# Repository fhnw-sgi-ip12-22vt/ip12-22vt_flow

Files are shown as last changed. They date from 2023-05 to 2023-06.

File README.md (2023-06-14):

# Project FLOW

## Beschreibung

Die Primeo Energie AG ist ein Energieversorgungsunternehmen in Münchenstein und versorgt Teile von Basel-Landschaft, Solothurn und Saint-Louis (F) mit Strom. Primeo legt einen grossen Wert auf erneuerbare Energien.

Primeo hat bereits eine Lernwelt in Münchenstein und in Olten aufgebaut. In dieser Lernwelt werden Workshops angeboten, Experimente können durchgeführt werden und Führungen werden angeboten. Link: [primeo-energie.ch](https://www.primeo-energie.ch/ueber-uns/lernwelt-energie.html)

Mit dem Projekt Primeo Energie Kosmos wird ein neues Science- und Erlebniscenter in Münchenstein gebaut. Es soll eine Verbindung zwischen Klima und Energie geschaffen werden und erneuerbare Energien attraktiver gemacht werden.

### Grundidee
Grundidee unseres Produktes ist, Kindern und Jugendlichen nachhaltige Energieproduktionen und das Max Flow Problem spielerisch näher zu bringen. Die physischen Komponenten sollen bei den Personen ein Interesse wecken, damit sie von alleine auf das Produkt zugehen. Mithilfe von haptischen Elementen soll die Spielperson aktiver am Spiel teilnehmen können.  Eine kurze Spieldauer von 2-3min verhindert Langeweile und Frustration bei der spielenden Person. Um die Verweilzeit am Spiel zu verlängern und die Herausforderung für geschickte Spielpersonen zu erhöhen, können schwierigere Levels ausgewählt werden.

Ziel des Spiels ist es, von der Source (in Abb.1 die Windkraftanlage und der Staudamm) möglichst viel Strom in die Senke (die Fabrik) zu leiten. Dafür wählt die Spielperson die Verbindungslinie zwischen den Häusern mit einem Knopfdruck an und wählt auf dem Display die Menge an Stromeinheiten (0,1,2 oder 3), welche durch diese ausgewählte Kante fliessen soll, aus. Die rote Zahl ist die Maximalkapazität dieser Kante, das heisst die Spielperson kann nicht mehr Einheiten Strom legen, als die Maximalkapazität der Kante. Versucht die Spielperson dennoch einen höheren Wert zu legen, blinkt die Kante rot und nimmt den gelegten Wert nicht an.

Ein Haus kann nur soviel Einheiten Strom weitergeben, wie es auch erhalten hat (Input >= Output). Wird mit einem Spielzug der Input < Output eines Hauses, blinkt die manipulierte Kante und dann die Kontrollleuchte rot und der Wert wird nicht gespeichert. Eine Lösung der Spielperson wird akzeptiert, sobald mindestens 1 Einheit Strom in der Fabrik ankommt.

In schwierigeren Leveln weht kein Wind mehr und die Windkraftwerke produzieren keinen Strom mehr, oder es muss ein Zwischenziel mit Strom versorgt werden. Beim Zwischenziel leuchtet die Kontrollleuchte orange.

Wer nicht unnötig viel Einheiten Strom legt, wird am Ende mit einem höheren Score belohnt. Im Optimalfall sind also bei allen Häusern Input = Output.
## Requirements
[Verweis](Docu/Requirements_Flow.pdf) zu den Requirements.
## Usablity Dossier
[Verweis](Docu/Usability_Dossier.pdf) zu dem Usability Dossier.
## Teileliste
[Verweis](Docu/hardware/Hardware.adoc) zu der Teileliste.

## Visuals
 
Erste Skizze des Projekts: <br />
Erste Skizze des Projekts Erste Skizze <br />
Projektarbeit während der zweiten Projektwoche: <br />
Arbeit an Projekt von zwei Projektmitgliedern Arbeit an Projekt <br />
Erfolgreiches Leuchten der Verbindungslinien: <br />
Projekt mit beleuchteten Plexiglas Stäben Projekt Bild 1 <br />

## Installation

### Vorinstallation

Link für das übernommene Setup: [pi4j.com/getting-started](https://pi4j.com/getting-started/set-up-a-new-raspberry-pi/)
JDK und I2C Konfigurationsänderungen sind im Verweis nicht enthalten.

- Raspberry Pi OS (früher Raspbian) von der offiziellen WebsiteImage auf eine Micro-SD-Karte laden mit Tool Raspberry Pi Imager.
- Micro-SD-Karte mit Tastatur, Maus, HDMI-Kabel, Ethernet-Kabel verbinden und schliesslich das Stromkabel an dem Raspberry Pi anschliessen.
- Raspberry Pi einschalten und warten bis das Raspberry Pi OS gestartet ist.
- Einrichtungsassistenten ausführen, um die Sprache, Zeitzone, Tastaturbelegung und Netzwerkverbindung einzustellen.
- Installiere Bellsoft Liberica full jdk 17 (https://bell-sw.com/pages/downloads/) auf dem Raspberry pi.
- Tool "raspi-config" verwenden, um Einstellungen anzupassen: Ausführen des Befehls "sudo raspi-config"
  - Pfeiltasten verwenden, um zu "Interfacing Options" oder "Schnittstellenoptionen" zu navigieren und Enter betätigen.
  - Navigation zu "I2C" und Enter drücken.
  - Nach Frage ob ARM I2C-Schnittstelle aktivieren werden sollte, "Ja" auswählen und Enter drücken.
- Anschliessen von Maus und Tastatur über den USB-A Anschluss des Raspberry Pi 4 
- Bedienen des Raspberry Pi über Maus und Tastatur 
- Starten des Programms "Terminal"
- Ausführen des Befehls: "cd /opt/flow". Nun befindet sich man im Verzeichnis des Projekts. 
- Das Projekt muss nun geklont werden: [git clone](git-repo-clone-url).

### Rahmenbedingungen
[Verweis](Docu/software(sad)/src/04_solution_strategy.adoc) zu den Rahmenbedingungen.

### Hardware Setup
Der physische Spielkasten beinhaltet alle Hardware Komponenten des Produkts "FLOW".
Folgende Schritte um die Hardware startbereit zu bringen, sind nötig:

- Das daran verbundene Stromkabel muss an einer Steckdose (Typ J) angeschlossen werden.
- Der Switch an dem Stromkabel muss betätigt werden.

Nun hat das Produkt ausreichend Strom um zu funktionieren.

### Software Setup
Um das Softwaresetup auszuführen wird das Hardwaresetup vorausgesetzt.
Die Software wird mithilfe maven gestartet.
Um die Applikation erfolgreich zu starten, werden folgende Schritte benötigt:

- Anschliessen von Maus und Tastatur über den USB-A Anschluss des Raspberry Pi 4
- Bedienen des Raspberry Pi über Maus und Tastatur
- Starten des Programms "Terminal"
- Ausführen des Befehls: "cd /opt/flow". Nun befindet sich man im Verzeichnis des Projekts.
- Ausführen des Befehls: "i2cset -y 1 0x70 0x4"
- Ausführen des Befehls: "export DISPLAY=:0 && xhost local:root && sudo mvn clean javafx:run" im Verzeichnis des Projekts.
- Alternativ kann der pi im selben netzwerk eines Computers sein, welcher mit ssh verbunden wird. In diesem fall kann das bash script: unter /assets/bash-script/run.sh verwendet werden und mit "./run.sh & disown" detached ausgeführt werden.

### Future Requirements
Future Requirements sind im Anhang des Dokuments [Requirements](Docu/Requirements_Flow.pdf) zu finden.

## Autoren und Anerkennung
- Tim H.
- Joshua B.
- Adrian M.
- Shane Z.
- Maik D.
- Erhan B.
- Ron G.

## License
Das Produkt steht unter "MIT License"

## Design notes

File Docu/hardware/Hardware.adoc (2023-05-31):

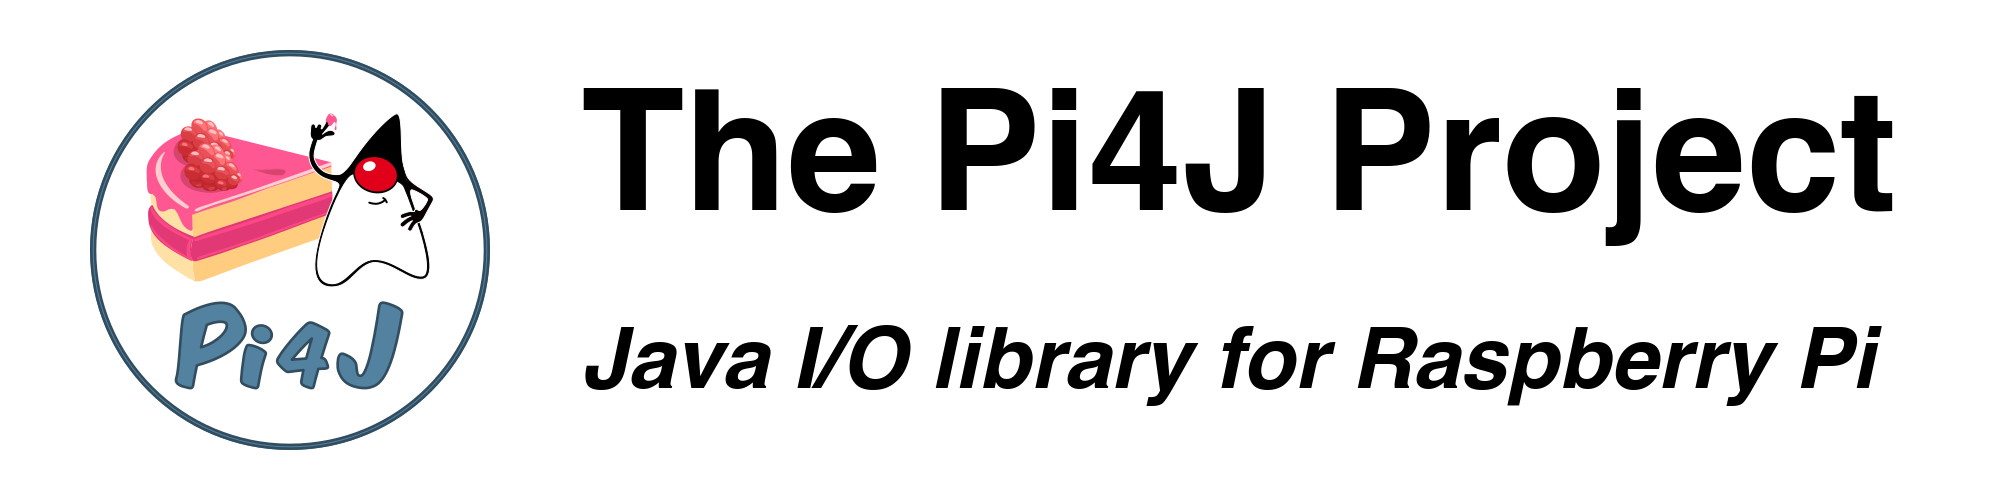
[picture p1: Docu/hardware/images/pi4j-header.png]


Informationen zum Erstellen und Zusammenbauen finden sie hier: https://www.cs.technik.fhnw.ch/confluence20/display/IP1222vt/Material[] TODO: Link anpassen

== Teileliste
[[Teileliste]]
Die Mengenangabe in der Liste ist ohne Ersatzteile und benötigtes Testequipment zu verstehen.

[options="header"]
|=======================================================================
| Nr | Name                            | Stückzahl | Kaufort
| 1 | Raspberry Pi 4B 4GB RAM         | 1 | Von FHNW besorgt
| 2 | 7inch Capacitive Touch Display LCD  1024×600 HDMI   | 1 | https://www.bastelgarage.ch/7inch-capacitive-touch-display-lcd-c-1024-600-hdmi

| 3 | Wax für 3D Druck TODO Liter              | 3 | TODO
| 4 | TCA9548A I2C Multiplexer         | 1 |https://www.bastelgarage.ch/8-kanal-i2c-multiplexer-tca9548a

| 5 | Gravity CH423 I2C 24 Digital IO Portexpander | 7 | https://www.bastelgarage.ch/gravity-ch423-i2c-24-digital-io-portexpander?search=Gravity%20io%20expander
| 6 | Sekundenleim 3ml                    | 2 | Im Migros gekauft
| 7 | Micro HDMI - zu - HDMI Adapter  | 2 |https://www.ricardo.ch/de/a/micro-hdmi-zu-hdmi-adapter-(fabrikneu-ovp)-1218087588/
| 8 | Holz für Baukasten         | 1 | Bei OBI in Deutschland gekauft
| 9 | Square Momentary Button. 12 x 12 x 8 mm with Cap    | 21 |https://www.play-zone.ch/en/platinenschalter-12mm-x-12mm-mit-farbiger-kappe.html

| 10 | PLEXIGLAS® LED FARBLOS 0E011 L | Gesamtlänge 240cm mit &#216;8mm | https://www.plexiglas-shop.com/de/produkte/plexiglas-led/sr0e011l.html
| 11 | LED LL 5-8000RGB (RG LED) | 30 |https://www.distrelec.ch/de/led-gr-565nm-627nm-gruen-rot-mm-kingbright-59egw/p/17521456

| 12 | L-59EGW (RGB LED)| 12 |https://secure.reichelt.com/ch/en/led-5-mm-4-pin-4000-8000-mcd-rgb-led-ll-5-8000rgb-p156358.html?&nbc=1

| 13 | 3D gedruckte Teile | siehe unten | Privat gedruckt von Tim H.
| 14 | Jumperkabel Dupont M/M 30cm | 40 |https://www.bastelgarage.ch/jumperkabel-dupont-set-30cm-m-m-40-stuck?search=Jumper

| 15 | Jumperkabel Dupont M/F 30cm | 40 |https://www.bastelgarage.ch/jumperkabel-dupont-set-30cm-m-f-40-stk?search=Jumper

| 16 | Jumperkabel Dupont F/F 30cm | 40 | https://www.bastelgarage.ch/jumperkabel-dupont-set-30cm-f-f-40-stuck

| 17 | Lötzinn 20cm | 1 | Aus der FHNW Werkstatt
|=======================================================================

== Dateien der 3D gedruckten Spielelemente: +
link:images/[Bilder] +
link:3D_files/[3D files]

== Abmessungen:

[%header,format=csv]
|===
"Objekt","Länge","Breite","Höhe"
"Spielkasten","700mm","700mm","150mm"
"A","X","Y","Z"
|===

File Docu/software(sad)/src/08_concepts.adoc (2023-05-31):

[[section-concepts]]
== Querschnittliche Konzepte
=== Fachliche Konzepte

.Spielprinzip
Das Projekt FLOW basiert auf dem Max-flow Problem und vermittelt den Spielern die Grundlagen der optimalen Verteilung von Strom im Stromnetz. Die Spieler interagieren mit den "Edges" und "Kapazitäten", um die beste Verteilungsmöglichkeit zu finden.

.Spielmechanik
Die Spieler wählen Edges durch das Betätigen von Buttons aus und weisen ihnen Kapazitäten zu. Nodes und Edges sind durch LEDs und LED-Tubes visualisiert. Das Spiel hat zwei Energiequellen (Windrad und Wasserkraftwerk) und ein Ziel (Fabrik).

=== User Experience (UX)

.Benutzerfreundlichkeit
Die Benutzeroberfläche ist intuitiv und ansprechend gestaltet, sodass die Spieler leicht mit den verschiedenen Elementen des Spiels interagieren können. Die LED-Visualisierung hilft dabei, den Status der Nodes und Edges zu verstehen. Die 3D-gedruckten Häuser und Kraftwerke stellen die Problemstellung konkretisierter dar und erhöht somit das Verständnis des Spielers.

.UI des Touch Screen
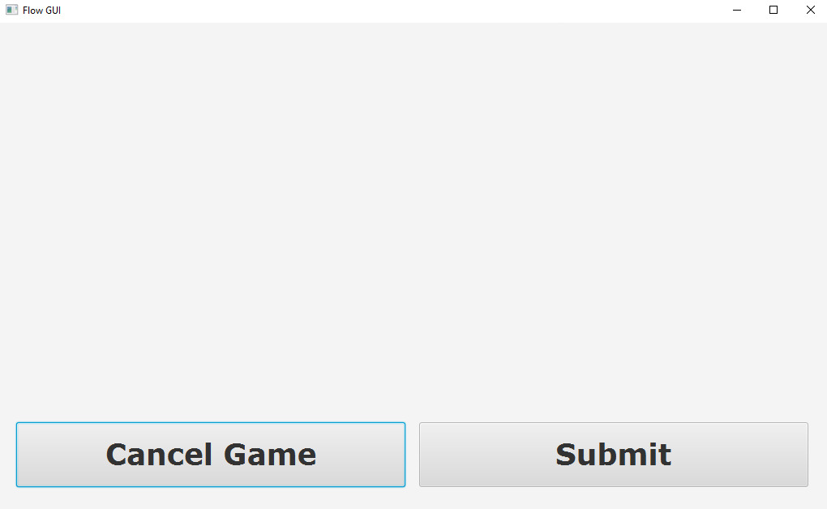
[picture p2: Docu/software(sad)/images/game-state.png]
Game-State

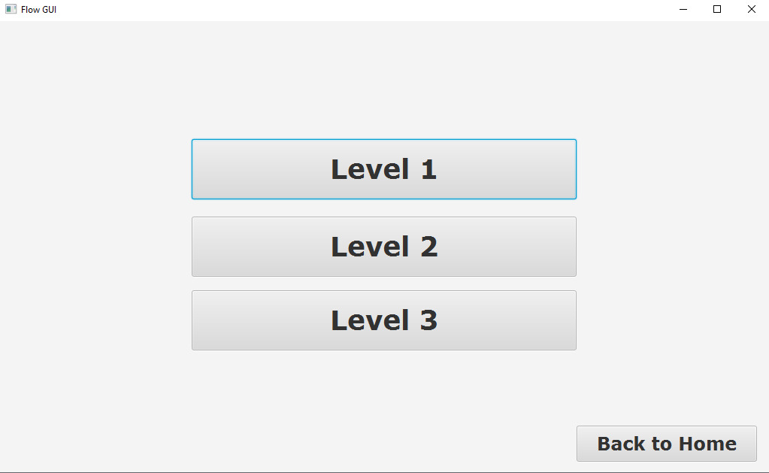
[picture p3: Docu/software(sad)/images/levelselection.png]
Level-Auswahl

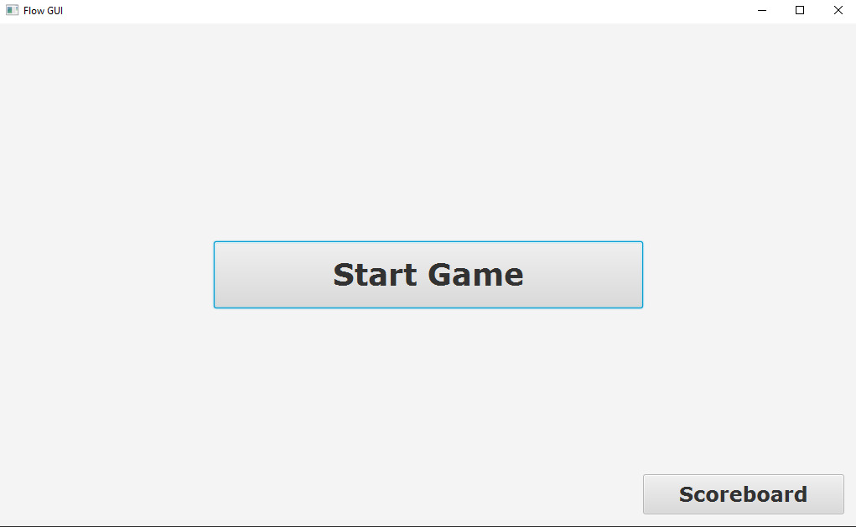
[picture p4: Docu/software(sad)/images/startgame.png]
Start-Game


.Anpassungsfähigkeit
Das Spiel kann an verschiedene Altersgruppen und Bildungsniveaus angepasst werden, indem die Komplexität der Aufgaben und die Anzahl der verfügbaren Ressourcen variiert werden.

=== Sicherheitskonzepte (Safety und Security)

.Elektrische Sicherheit
Das Projekt verwendet sichere elektrische Komponenten und Verkabelung, um Stromschlag- und Brandgefahren zu minimieren. Die Stromversorgung und -verteilung sind so konzipiert, dass sie den geltenden Sicherheitsstandards entsprechen.

.Datenschutz und Datensicherheit:
Da das Projekt hauptsächlich ein physisches Spielbrett ist und keine Benutzerdaten gespeichert werden, sind Datenschutz und Datensicherheit nicht relevant.

=== Unter-der-Haube

.Hardware-Komponenten
Die Hauptkomponenten des Projekts sind der Raspberry Pi 4, TCA9548a, CH423 und Buttons. Sie sind für die Steuerung, Kommunikation und Interaktion der verschiedenen Elemente des Spiels verantwortlich.

.Software
Die Software des Projekts ist in Java geschrieben und verwendet die pi4j-Bibliothek für die Ansteuerung der Hardwarekomponenten. Maven wird für das Deployment der Software eingesetzt.

=== UML Diagramm
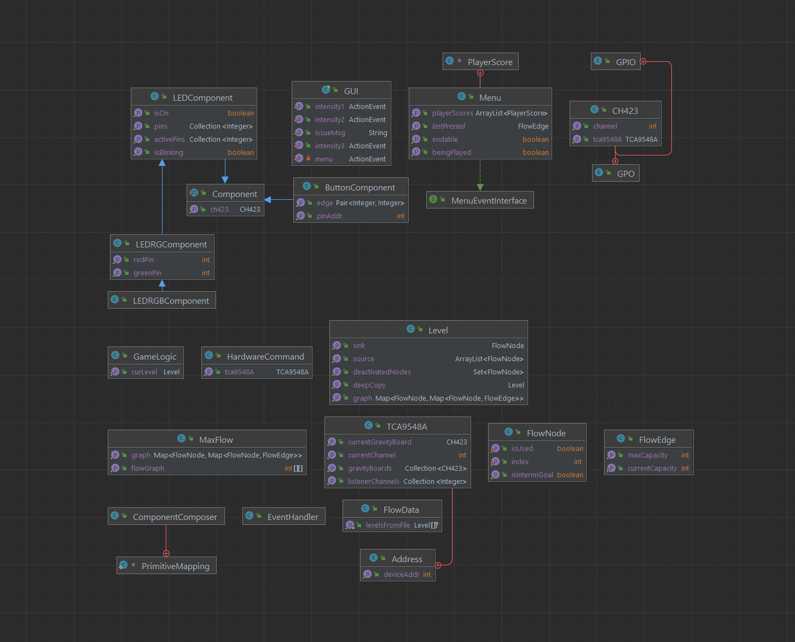
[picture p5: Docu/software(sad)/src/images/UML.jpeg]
Visualiserte Klassen

Dieses Diagramm visualisiert die Abhängigkeit der verschiedenen Klassen und deren Attribute. Es wurde reduziert, um den Überblick zu vereinfachen

=== Architektur- und Entwurfsmuster

.Systemarchitektur
Das Projekt FLOW ist modular aufgebaut, sodass Hardware- und Softwarekomponenten leicht erweitert werden können.
Um dies sicherzustellen wurde: 

- Gängige Technologien verwendet: RFID, Buttons, LED-Lampen, I2C Bus Communication, I2C Multiplexer, GPO/GPIO Gravity Board.
- Funktonalität abstrahiert und Objekt Orientiert Programmiert.
- Konfiguration in Dateien abgelegt oder leicht änderbar implementiert.

==== Netzwerktopologie
Die Netztopologie ist hierarchisch und sternförmig, wobei der Raspberry Pi 4 im Zentrum steht und die Hardwarekomponenten wie RGB LEDs, GPIO Extender, I2C GPIO Expander und Multiplexer über I2C-Busse und GPIO-Pins verbunden sind. Der Multiplexer ist direkt am Extender des Raspberry Pi4 angebunden und daran erweitert sind die I2c GPIO Expander.

===== Verkabelung der Komponenten
Die Dokumentation der Verkabelung der einzelnen Komponenten steht noch aus und muss erstellt werden. Leider sind in der Fritzing Open-Source-Bibliothek einige Komponenten, die wir in unserem Projekt verwenden, nicht verfügbar. Dazu gehört der CH423. Daher werden wir eine eigene Darstellung der Verkabelung dieser Komponenten erstellen und in die Dokumentation aufnehmen. Zusätzlich ist darauf hinzuweisen, dass das aktuell verfügbare Bild der Verkabelung lediglich eine stark vereinfachte Version der endgültigen Verkabelung darstellt. In der finalen Version werden noch weitere Komponenten und Verkabelungen hinzugefügt, welche dann detailliert dokumentiert werden.

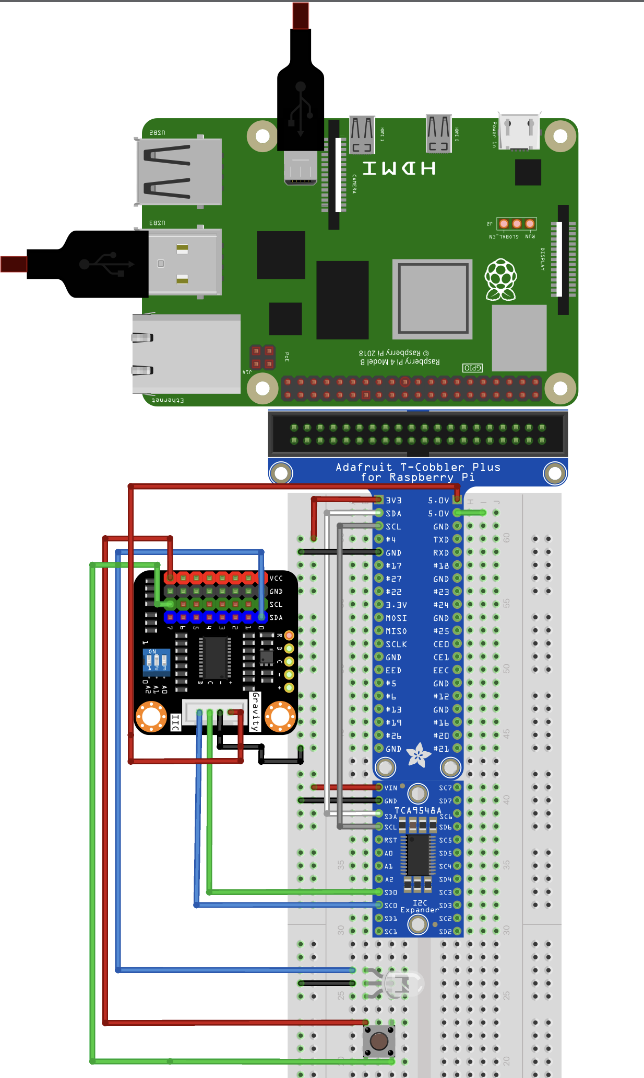
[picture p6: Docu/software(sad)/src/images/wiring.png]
Wiring Template


- Dieses Wiring-Diagramm veranschaulicht die Verbindung eines LED- und Button-Paares. Das CH423 Gravity-Board wurde hier durch ein anderes Board des gleichen Herstellers ersetzt. Der einzige Unterschied besteht darin, dass dieses Board ein anderes visuelles Pin-Layout hat. Ausserdem wurden die Kabel direkt angeschlossen.

.Kommunikationsmuster:
Die I2C-Kommunikation ermöglicht den Datenaustausch zwischen den Hardwarekomponenten wie dem Raspberry Pi 4, TCA9548a und CH423. Dieses Kommunikationsprotokoll gewährleistet eine effiziente und zuverlässige Datenübertragung im System.

=== Entwicklungskonzepte

.Implementierungsregeln
Um eine konsistente und qualitativ hochwertige Implementierung zu gewährleisten, sollten Best Practices für Softwareentwicklung und Hardwareintegration angewendet werden

=== Betriebskonzepte
==== Datenmigration
Beschrieben wird folgend der Vorgang, um die Daten des Projekt "FLOW" auf ein neues Medium zu übertragen:

- Projekt Ordner
    * Auf dem Raspberry Pi unter "/opt/flow" finden sie den Projektordner, auf welchem alle notwendige gespeichert sind.
- Log-Dateien
    * Auf dem Raspberry Pi können separat unter "/var/log/flow" gefunden werden, sie sind aber nicht für das Projekt notwendig.
- Relevanten Daten speichern

    * Kopieren auf ein externes Speichermedium:
        ** USB-Stick
            *** Schliessen Sie den USB-Stick an einen verfügbaren USB-Anschluss Ihres Raspberry Pi an.
            *** Öffnen Sie ein Terminalfenster.
            *** Geben Sie lsblk ein, um die Gerätebezeichnung des USB-Sticks zu identifizieren (z.B. "sda1").
            *** Erstellen Sie einen temporären Mount-Punkt für den USB-Stick: sudo mkdir /mnt/usbstick.
            *** Mounten Sie den USB-Stick an den temporären Mount-Punkt: "sudo mount /dev/sda1 /mnt/usbstick" (Ersetzen Sie "sda1" durch die tatsächliche Gerätebezeichnung).
            *** Kopieren Sie den Ordner "opt/flow" auf den USB-Stick: "sudo cp -r /opt/flow /mnt/usbstick/".
            *** Nachdem der Kopiervorgang abgeschlossen ist, unmounten Sie den USB-Stick: "sudo umount /mnt/usbstick".
            *** Entfernen Sie den USB-Stick sicher vom Raspberry Pi.
        ** Externe Festplatte
            *** Schliessen Sie die externe Festplatte an einen verfügbaren USB-Anschluss Ihres Raspberry Pi an.
            *** Öffnen Sie ein Terminalfenster.
            *** Geben Sie "lsblk" ein, um die Gerätebezeichnung der externen Festplatte zu identifizieren (z.B. "sdb1").
            *** Erstellen Sie einen temporären Mount-Punkt für die externe Festplatte: "sudo mkdir /mnt/ext_hdd".
            *** Mounten Sie die externe Festplatte an den temporären Mount-Punkt: "sudo mount /dev/sdb1 /mnt/ext_hdd" (Ersetzen Sie "sdb1" durch die tatsächliche Gerätebezeichnung).
            *** Kopieren Sie den Ordner "opt/flow" auf die externe Festplatte: "sudo cp -r /opt/flow /mnt/ext_hdd/".
            *** Nachdem der Kopiervorgang abgeschlossen ist, unmounten Sie die externe Festplatte: "sudo umount /mnt/ext_hdd".
            *** Entfernen Sie die externe Festplatte sicher vom Raspberry Pi.
--

- Nach erfolgreicher Migration
    * Auf dem neuen System können nun die gesicherten Daten zurück in den entsprechenden Projektordner kopiert werden
    * Validieren Sie die Datenintegrität (Dateiformat und Dateigrösse).
- Nach erfolgreicher Migration der Daten auf das neue System; Import der gesicherten Daten und Validierung der Datenintegrität:
    * JUnit Tests ausführen
    * Hardware-Komponenten überprüfen

.Löschen vorheriger Version
- Stellen Sie sicher, dass alle wichtigen Daten gesichert und migriert wurden.
- Wenn das Projekt auf einem Raspberry Pi ausgeführt wurde, können Sie auch das Betriebssystem neu installieren oder den Speicherplatz mit einem sicheren Löschen-Tool überschreiben, um sicherzustellen, dass keine Datenreste zurückbleiben.
    * Mehr hierzu steht im Kapitel 7 Verteilungssicht unter Vorinstallationen.
- Wenn dies nicht möglich ist, löschen Sie alle Dateien und Ordner, die mit der Installation von FLOW in Verbindung stehen. Dies einschliesslich der Anwendungsdateien, Konfigurationsdateien und Log-Dateien. Dies umfasst:
    * Projektordner:    "/opt/flow"
    * Log Dateien:      "/var/log/flow
--

==== Konfigurierbarkeit

Das "FLOW" Projekt nutzt zwei JSON-Dateien, "edges.json" und "nodes.json", zur Konfiguration der Hardwarekomponenten an den Knoten und Kanten des Graphen. Dies ermöglicht eine flexible Anpassung des Systems an unterschiedliche Hardware-Konfigurationen und Spielmodi.

===== Edges

Die "edges.json" Datei enthält eine Liste von Objekten, die jeweils eine Kante im Graphen repräsentieren. Jedes Objekt enthält folgende Schlüssel:

- "edge": Eine Liste von zwei Zahlen, die die Indizes der verbundenen Knoten in der Graphenstruktur repräsentieren.
- "leds": Eine Liste von Listen, die die Konfiguration der zugehörigen RGB-LEDs repräsentieren. Jede innere Liste enthält vier Zahlen: Den Index der CH423 Gravity Boards und die GPIO-Pins, an denen die Pins des RGB-LED angeschlossen sind. Eine Kante kann mehrere LEDs beinhalten.
- "button": Eine Liste von zwei Zahlen, den Index des CH423 Gravity Boards und den der GPIO-Pin des zugehörigen Buttons.

Um die "edges.json" Datei zu erweitern oder zu ändern, können Sie einfach neue Objekte zur Liste hinzufügen oder bestehende Objekte bearbeiten. Stellen Sie sicher, dass die Indizes und GPIO-Pins korrekt den physischen Verbindungen in Ihrem System entsprechen.

===== Nodes

Die "nodes.json" Datei enthält eine Liste von Listen, die die Knoten im Graphen repräsentieren. Jede Liste enthält:

- Den Index des CH423 Gravity Boards
- Den GPIO-Pin des roten Kabels
- Den GPIO-Pin des grünen Kabels

Um die "nodes.json" Datei zu erweitern oder zu ändern, können Sie einfach neue Listen zur Liste hinzufügen oder bestehende Listen bearbeiten. Stellen Sie sicher, dass der index des CH423 Gravity Boards und die GPIO-Pins korrekt den physischen Verbindungen in Ihrem System entsprechen.

Insgesamt erlaubt diese Struktur eine hohe Konfigurierbarkeit, sowohl in Bezug auf die Hardware-Konfiguration als auch auf die Spiellogik. Änderungen an den JSON-Dateien erlauben es Ihnen, das System schnell und effizient an neue Anforderungen anzupassen.

= Erweiterbarkeit

Die Erweiterbarkeit eines Systems umfasst sowohl Hardware- als auch Softwarekomponenten.

== Anpassungen an der Hardware

In Bezug auf die Hardware sind Anpassungen im Allgemeinen weniger zeitaufwendig. Der Austausch von LEDs und Tasten ist relativ einfach und kann schnell durchgeführt werden. Dies wurde bereits genauer dokumentiert.

link:07_deployment_view.adoc[Informationen zu "Repairability"]

== Anpassungen an der Software

Verglichen mit der Hardware sind Anpassungen auf der Softwareseite oft zeitaufwendiger. Insbesondere bedeutende Änderungen an der Klasse CH423 sind ohne Vorwissen sehr zeitaufwendig. Dies ist vor allem der Fall, wenn die CH423 mit dem i2c Multiplexer tca9854a verwendet wird. Die Änderungen in diesem Bereich erfordern eine beträchtliche Zeitinvestition.

Als Nachschlagewerk für diese Komponenten dient das Datasheet:

https://www.ti.com/lit/ds/symlink/tca9548a.pdf (I2C Multiplexer)

http://www.wch-ic.com/products/CH423.html (Gravity Board / Ch423)

Oberflächliche Anpassung der grafischen Benutzeroberfläche (GUI) sind jedoch meist weniger zeitaufwendig. Dennoch bedarf auch diese Art von Anpassungen einer gewissen Zeitinvestition.

== Anpassbarkeit der Spiellogik

Auch die Spiellogik ist anpassbar. Obwohl dies durchaus machbar ist, erfordert es jedoch eine gewisse Menge an Recherche und Verständnis für das zugrunde liegende System.

////
[role="arc42help"]
****
.Inhalt
Dieser Abschnitt beschreibt übergreifende, prinzipielle Regelungen und Lösungsansätze, die an mehreren Stellen (=_querschnittlich_) relevant sind.

Solche Konzepte betreffen oft mehrere Bausteine.
Dazu können vielerlei Themen gehören, beispielsweise:

* Modelle, insbesondere fachliche Modelle
* Architektur- oder Entwurfsmuster
* Regeln für den konkreten Einsatz von Technologien
* prinzipielle -- meist technische -- Festlegungen übergreifender Art
* Implementierungsregeln

.Motivation
Konzepte bilden die Grundlage für _konzeptionelle Integrität_ (Konsistenz, Homogenität) der Architektur und damit eine wesentliche Grundlage für die innere Qualität Ihrer Systeme.

Manche dieser Themen lassen sich nur schwer als Baustein in der Architektur unterbringen (z.B. das Thema „Sicherheit“).

.Form
Kann vielfältig sein:

* Konzeptpapiere mit beliebiger Gliederung,
* übergreifende Modelle/Szenarien mit Notationen, die Sie auch in den Architektursichten nutzen,
* beispielhafte Implementierung speziell für technische Konzepte,
* Verweise auf „übliche“ Nutzung von Standard-Frameworks (beispielsweise die Nutzung von Hibernate als Object/Relational Mapper).

.Struktur
Eine mögliche (nicht aber notwendige!) Untergliederung dieses Abschnittes könnte wie folgt aussehen (wobei die Zuordnung von Themen zu den Gruppen nicht immer eindeutig ist):

* Fachliche Konzepte
* User Experience (UX)
* Sicherheitskonzepte (Safety und Security)
* Architektur- und Entwurfsmuster
* Unter-der-Haube
* Entwicklungskonzepte
* Betriebskonzepte

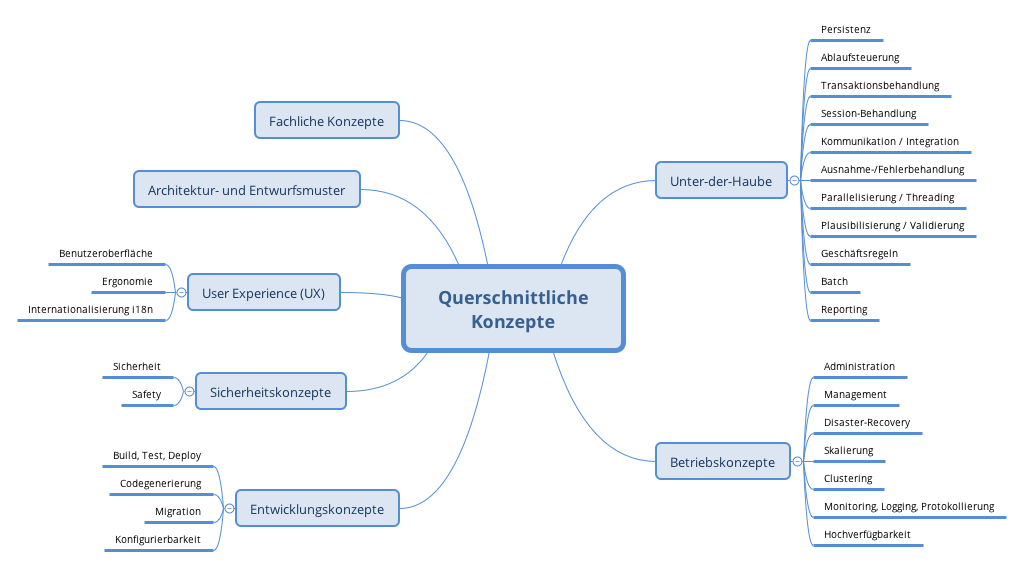
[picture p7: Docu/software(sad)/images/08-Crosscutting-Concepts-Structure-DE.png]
Possible topics for crosscutting concepts


.Weiterführende Informationen

Siehe https://docs.arc42.org/section-8/[Querschnittliche Konzepte] in der online-Dokumentation (auf Englisch).

****

=== _<Konzept 1>_

_<Erklärung>_

=== _<Konzept 2>_

_<Erklärung>_

...

=== _<Konzept n>_

_<Erklärung>_

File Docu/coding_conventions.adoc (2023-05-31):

= Coding Conventions

== Verwendete Konventionen

Zur Sicherung der Code Qualität verwenden wir die Sun Coding Conventions.
https://www.oracle.com/technetwork/java/codeconventions-150003.pdf

== Sicherstellung der Einhaltung der Konventionen

- Checkstyle IntelliJ linter
- Checkstyle Maven Plugin
- Code Reviews
- CI/CD Pipelines

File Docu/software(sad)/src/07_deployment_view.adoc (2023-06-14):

[[section-deployment-view]]
== Verteilungssicht

=== Komponenten
System: Die Applikation wird lokal auf einem Raspberry Pi 4 ausgeführt, der vor Ort beim Benutzer installiert ist. Die Ausführungsumgebung besteht aus dem Betriebssystem Raspberry Pi OS.
Der Hauptrechner ist der Raspberry Pi 4, ein Einplatinencomputer mit einem ARM Cortex-A72 Quad-Core-Prozessor.

Kanäle: Die Kommunikation zwischen dem Raspberry Pi 4 und den Hardwarekomponenten erfolgt über I2C-Verbindungen und GPIO-Pins.

Sonstige Bestandteile:

- RG/RGB LEDs: Verwendet für die Visualisierung von Nodes/Edges.
- Plexiglasstäbe: LED-Röhren, die Edges darstellen.
- GPIO Extension Board: Erweitert die Anzahl der verfügbaren GPIO-Pins auf dem Raspberry Pi 4.
- TCA9548a I2C-Multiplexer: Der TCA9548a ermöglicht es mehrere Busse zu verwenden und bis zu 8 I2C-Geräte über einen I2C-Bus zu steuern.
- CH423 IO Expansion Board: Ermöglicht die Nutzung von zusätzlichen GPIO-Pins über den I2C-Bus.

=== Vorinstallationen
Link für das ursprünglich übernommene Setup: https://pi4j.com/getting-started/set-up-a-new-raspberry-pi/
[%linebreak]
JDK und I2C Konfigurationsänderungen sind im Link nicht enthalten.

- Raspberry Pi OS (früher Raspbian) von der offiziellen WebsiteImage auf eine Micro-SD-Karte laden mit Tool Raspberry Pi Imager.
- Micro-SD-Karte mit Tastatur, Maus, HDMI-Kabel, Ethernet-Kabel verbinden und schliesslich das Stromkabel an dem Raspberry Pi anschliessen.
- Raspberry Pi einschalten und warten bis das Raspberry Pi OS gestartet ist.
- Einrichtungsassistenten ausführen, um die Sprache, Zeitzone, Tastaturbelegung und Netzwerkverbindung einzustellen.
- Installiere Bellsoft Liberica full jdk 17 (https://bell-sw.com/pages/downloads/) auf dem Raspberry pi.
- Tool "raspi-config" verwenden, um Einstellungen anzupassen: Ausführen des Befehls "sudo raspi-config"
. Pfeiltasten verwenden, um zu "Interfacing Options" oder "Schnittstellenoptionen" zu navigieren und Enter betätigen.
. Navigation zu "I2C" und Enter drücken.
. Nach Frage ob ARM I2C-Schnittstelle aktivieren werden sollte, "Ja" auswählen und Enter drücken.
. Anschliessen von Maus und Tastatur über den USB-A Anschluss des Raspberry Pi 4
. Bedienen des Raspberry Pi über Maus und Tastatur
. Starten des Programms "Terminal"
. Ausführen des Befehls: "cd /opt/flow". Nun befindet sich man im Verzeichnis des Projekts.
. Das Projekt muss nun geklont werden: "git clone <git-repo-clone-url>".

=== Deployment

==== Hardwaresetup
Der physische Spielkasten enthält alle Hardware-Komponenten des Produkts "FLOW"
Folgende Schritte sind nötig, um die Hardware startbereit zu bringen:

- Das daran verbundene Stromkabel muss an einer Steckdose (Typ J) angeschlossen werden.
- Die Switch an dem Stromkabel muss betätigt werden.

Nun hat das Produkt ausreichend Strom um zu funktionieren.

==== Softwaresetup
Um das Softwaresetup auszuführen wird das Hardwaresetup vorausgesetzt.
Die Software wird mithilfe maven gestartet.
Um die Applikation erfolgreich zu starten, werden folgende Schritte benötigt:

- Anschliessen von Maus und Tastatur über den USB-A Anschluss des Raspberry Pi 4
- Bedienen des Raspberry Pi über Maus und Tastatur
- Starten des Programms "Terminal"
- Ausführen des Befehls: "cd /opt/flow". Nun befindet sich man im Verzeichnis des Projekts.
- Ausführen des Befehls: "i2cset -y 1 0x70 0x4"
- Ausführen des Befehls: "export DISPLAY=:0 && xhost local:root && sudo mvn clean javafx:run" im Verzeichnis des Projekts.
- Alternativ kann der pi im selben netzwerk eines Computers sein, welcher mit ssh verbunden wird. In diesem fall kann das bash script: unter /assets/bash-script/run.sh verwendet werden und mit "./run.sh & disown" detached ausgeführt werden.

=== Wartung
Um die Wartung zu vereinfachen, können viele Komponenten einfach ausgetauscht werden. Lötkenntnisse sind Voraussetzung,
um die Kabel korrekt zu verbinden. +

Alle Knöpfe und LED haben auf der Unterseite des Baukastens eine Nummer, in welchen Steckplatz sie gehören. Die Nummer ist wie folgt aufgebaut: +
[options="header"]
|===
| Komponent | Aufbau
| Knöpfe | a/b/c
| RG LED | a/b/c,d
| RGB LED | a/b/c,d,e
|===

[options="header"]
|=====================
|Nummer | Bedeutung
| a | Nummer des I2C GPIO Expanders
| b | 0 -> GPO Slot, 1 -> GPIO Slot
| c,d,e | Nummer des Slots
|=====================
Wobei bei einer RG LED bei c der rote Channel und d der grüne Channel ist. Bei einer RGB LED ist c der rote Channel, d der grüne Channel und e der blaue Channel. +

Die I2C GPIO Expander sehen wie folgt aus und ihre Nummerierung ist neben dem Expander zu finden. Hier ist der Expander Nr. 5 abgebildet: +

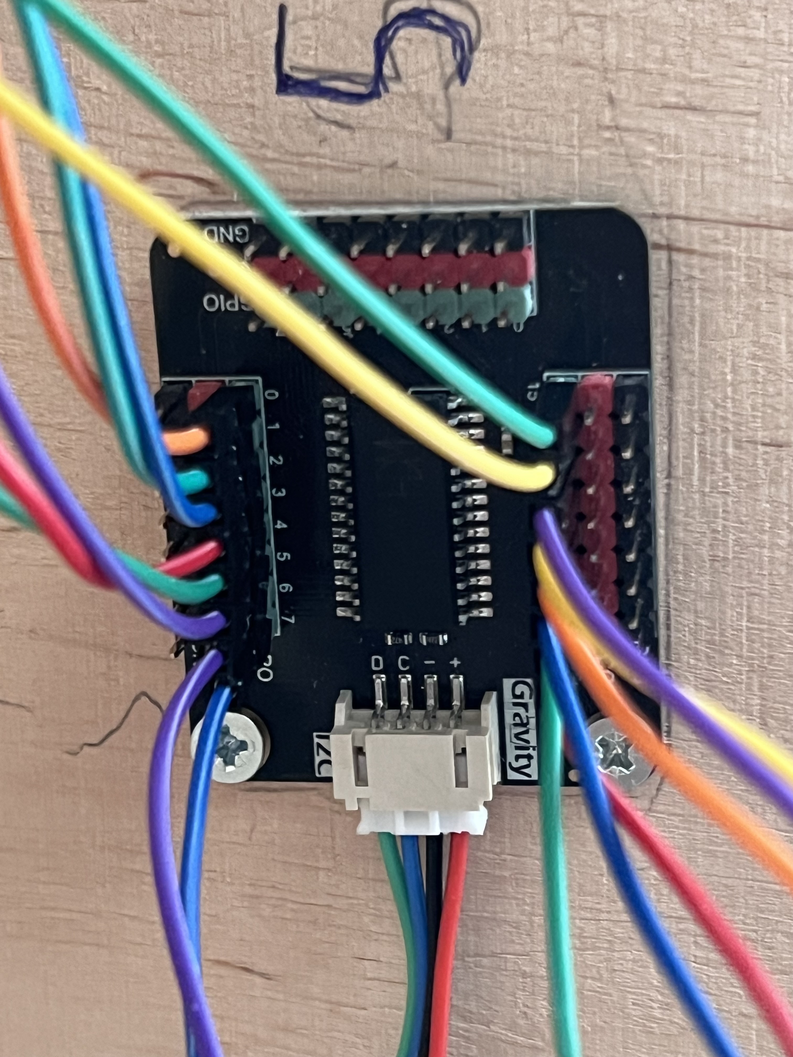
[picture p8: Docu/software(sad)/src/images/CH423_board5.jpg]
I2C GPIO Expander Nr.5


z.B. 1/0/1 bedeutet, dass der Knopf am ersten I2C GPIO Expander im GPIO Slot 1 steckt. +
oder: 2/1/3,4 bedeutet, dass die LED am zweiten I2C GPO Expander im GPO Slot 3 und 4 steckt.

==== Knöpfe
Knöpfe haben zwei Ground Kabel, welche mit anderen Ground Kabeln von Knöpfen verlötet sind. Das andere Kabel ist in einem I2C GPIO Expander im GPIO Channel eingesteckt.
Das eine Ende des Grounds ist in einem beliebigen GND Pin eingesteckt, das andere Ende ist isoliert an den Holzkasten geklebt. +

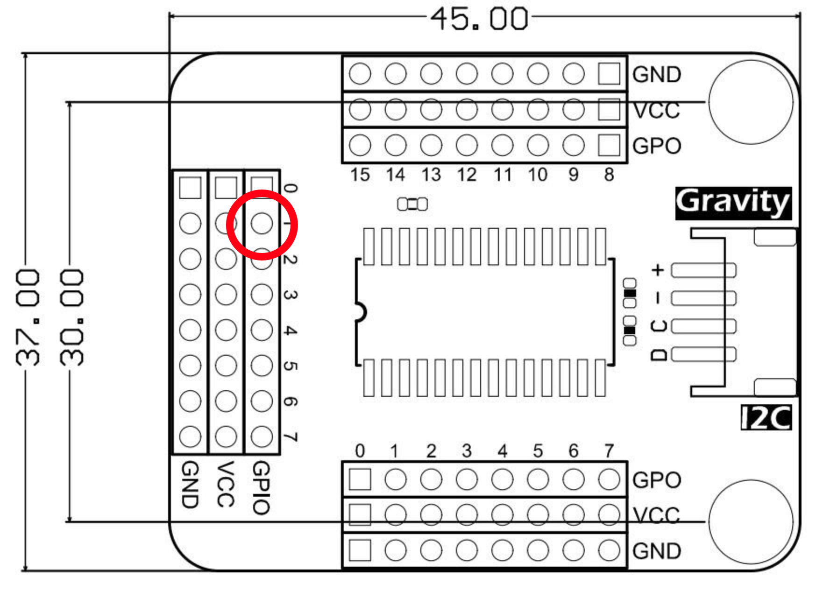
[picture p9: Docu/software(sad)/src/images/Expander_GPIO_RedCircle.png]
Knöpfe GPIO Pins


Um einen Button zu ersetzen, muss zuerst das Kabel vom I2C GPIO Expander ausgesteckt werden, und die Groundkabel mithilfe eines Lötstabes trennen.
Der Button ist mit Sekundenkleber festgeklebt und kann somit vom Brett gelöst werden. Es ist zwingend notwendig, dass die Steckplätze der LED unverändert bleiben.
Es ist zwingend notwendig, dass die Steckplätze der Knöpfe unverändert bleiben.+
Der Arbeitsaufwand für das Ersetzten von 1 Button wird auf 45min geschätzt.

==== Kanten LED (RGB LED)
Damit sind die LEDs gemeint, welche die Plexiglas Stäbe beleuchten.
Für die Verkabelung wurden verschiedene Farben benutzt: +
- Rot/Orange -> Rote LED +
- Grün/Gelb -> Grüne LED +
- Blau/Violett -> Blaue LED +
- Schwarz/Grau/Weiss/Braun -> Ground +
Die RGB Kabel sind im I2C GPIO Expander in den GPO Pins eingesteckt.

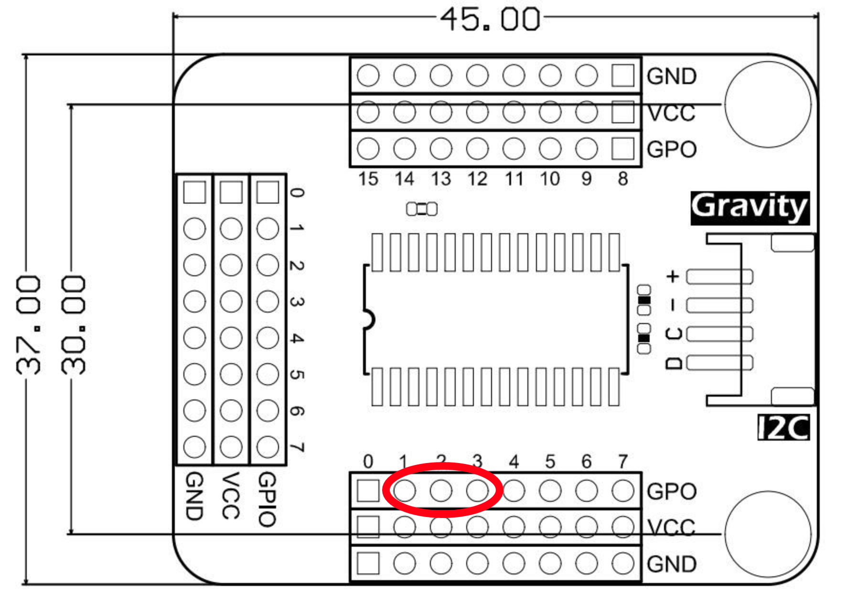
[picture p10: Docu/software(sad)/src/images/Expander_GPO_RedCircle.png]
Kanten LED GPO Pins


Um die LED zu entfernen, müssen die Kabel auf dem I2C GPIO Expander ausgesteckt werden. Dann den Deckel des 3D Gehäuses entfernen und die LED nach unten drücken.
Zu empfehlen ist, die LED mit einem Holz- oder Plastikstäbchen runter zu drücken +
Der Arbeitsaufwand wird auf 1h geschätzt.

==== Knotenpunkt LED (RG LED)
Damit sind die LEDs gemeint, welche neben den Häusern in der grauen 3D gedruckten Halterung sind.
Die Verkabelung ist wie folgt gekennzeichnet: +
- Mit Isolierband markiert -> Gelb +
- Kabel mit gelötetem Ende -> Ground +
- Übriges Kabel -> Rot +

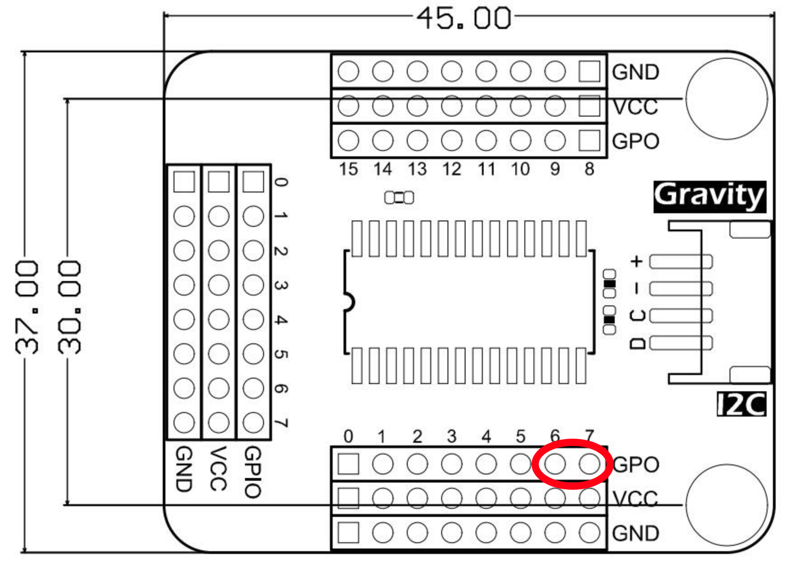
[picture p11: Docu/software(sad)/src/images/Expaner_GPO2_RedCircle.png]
Knotenpunkt LED


Um die LED zu entfernen, ist es von Vorteil, die 3D Halterung ebenfalls abzulösen. Diese ist mit Sekundenkleber festgeklebt. Alternativ kann auch die Verkabelung auf der Unterseite von der LED gelöst werden und versucht werden, die LED aus der 3D gedruckten Halterung zu entfernen.
Es ist zwingend notwendig, dass die Steckplätze der LED unverändert bleiben. +
Der Arbeitsaufwand wird auf 1h geschätzt.

==== I2C GPIO Expander
Die I2C GPIO Expander sind mit zwei Schrauben an der Holzplatte befestigt. Diese müssen gelöst werden, damit die Expander entfernt werden können. +
Die Kabel können am weissen Steckplatz des Expanders entfernt werden, somit muss nicht die ganze Verkabelung neu gelegt werden. +

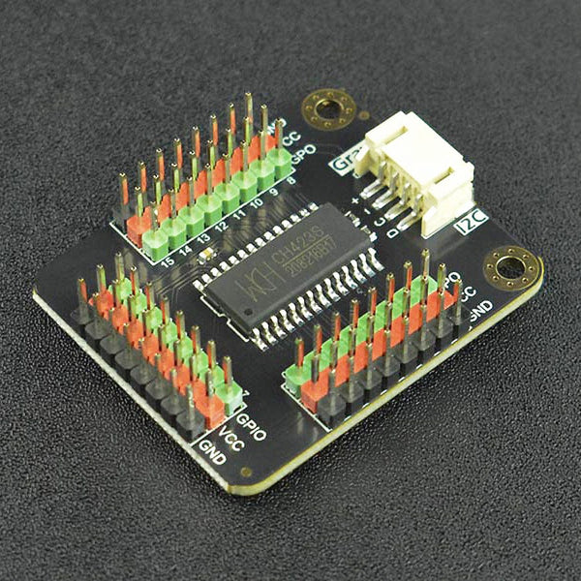
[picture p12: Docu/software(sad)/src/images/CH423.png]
I2C GPIO Expander


Es ist essenziell, dass alle LEDs und Buttons an den gleichen Steckplätzen bleiben, dafür kann die Nummerierung der Steckplätze auf der Unterseite des Holzkastens verwendet werden. +

Der Arbeitsaufwand wird auf 30min geschätzt. +

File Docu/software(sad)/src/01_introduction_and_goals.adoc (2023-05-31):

[[section-introduction-and-goals]]
==	Einführung und Ziele

In diesem Kapitel wird auf die Aufgabenstellung, die funktionalen Anforderung, dies das Produkt beschriebt sowie auch die Qualitätsziele eingegangen.
Ausserdem werden die Stakeholder und ihre Erwartungshaltung definiert.
Dies soll einen Überblick über die Rahmenbedingungen des Systems bieten.

=== Aufgabenstellung

In der Aufgabenstellung wird dies näher angeschaut und das Produkt erläutert.

== Was ist FLOW?

Wie genau das Stromnetz aufgebaut wissen wenige.
Mit der steigenden "Awareness" bezüglichem der effizienten Stromnutzung und optimaler Verteilung des Stroms innerhalb eines Netzes.
Wie gelangt genug Strom effizient an die jeweiligen Endnutzer.
Bzw. in unserem abstrahierten Fall Häuser.

Unser Produkt, mit dem Namen "FLOW" soll diese optimale Verteilung, basierend auf dem "Max-flow-Algorithmus" anschaulich dargestellt werden.

* Thematisiert die Komplexität der Verteilung von Strom im Stromnetz

* Interaktiver Umgang mit den einzelnen "Edges" und den "Kapazitäten"

* Die optimale Verteilung wird als anstrebendes Ergebniss dem Nutzer übergeben.
Der Spieler versucht also durch überlegen, selber auf die beste Verteilungs-möglichkeit zu kommen.

== Wesentliche Features

Die wesentlichen Features sind:

* Anbieten eines strategischen Optimierungs-Spiel.

* Wiederspielbarkeit, durch über Levelauswahl.

* Wissensübertrag, Verständniss bezüglich Stromverteilung und Graphentheorie wird erhört.

.Produktziele
[cols="1,1,2,2,1"]
|===
| ID | Name | Beschreibung | Messung | Soll-Wert

| Z01 | Bewusstsein & Energienutzung
| 14 Jährige haben ein Bewusstsein für eine nachhaltige Energienutzung entwickelt oder erweitert.
| Auf Google Forms wird die Frage "Hast du dir während des Spielens Gedanken zur effizienten Energienutzung gemacht?" gestellt und kann mit "Ja" oder "Nein" beantwortet werden.
| Mindestens 50% der Antworten sind "Ja".

| Z02 | Unterhaltung
| Wer das Produkt nutzt, soll während des Spielens unterhalten werden und Spass daran haben. Im Vergleich zur Alternative "Solarauto-Workshop" und "Lernwelt" hat die jugendliche Zielgruppe mehr Spass in einer kürzeren Zeitspanne. Die Wahrnehmung von Spass und Unterhaltung ist subjektiv.
| Weil Spass und Unterhaltung subjektiv ist, ist es schwierig dies zu messen. Sinnvoll ist eine Frage auf dem Google Forms, welche mit einer Skala von 1-5 bewertet werden kann.
| Der Durchschnitt des Fragenbogens soll bei mindestens 3.5 von 5 Sternen sein.

| Z03 | Max Flow Problem
| Das mathematische Problem (Max Flow Problem) soll den Spielern näher gebracht werden. Benötigt ein Ort im Stromnetz mehr Energie, muss ein optimaler Weg für die Energie vom Herstellungsort bis zur Senke berechnet werden. Dabei hilft das Max Flow Problem.
| Die Spielerinnen und Spieler beantworten eine Frage auf Google Forms, ob sie mehr über das Max Flow Problem lernen möchten und können die Frage mit "Ja" oder "Nein" beantworten. Ein Link zur Website wird gezeigt.
| 10% der Spieler besuchen die Website.
|===

=== Stakeholder

.Stakeholders des Arc42 Document
[role="arc42help"]

[cols="1,1"]
|===
s|Wer?
s|Interesse, Bezug

|Softwarearchitektinnen und -architekten:
|Erfahrungen über das Unterhalten und erstellen eines Arc42 Dokuments sammeln.

|Entwicklerinnen und Entwickler:
|Dokumentieren der Entwicklung eines Projekts

|Kunde:
|Unterstützung der Kreation eines spannenden Max-flow-basierten Spiel

|===

.Stakeholders Projekt
[options="header"]
|=========================================================================================================================================================================================================================================================================================================================================================================
s| Stakeholder           s| Ansprechspersonen                           s| Charakterisierung und Hintergrund                                                                                                                  s| Bedürfnisse
| Art des Stakeholders  | Name, e-Mail...                             | Eigenschaften, Fähigkeiten, Geräte, Wissen, Erfahrungen, etc., die in die Nutzung des Produkts gebracht werden. Evtl. Verweise auf Dokumente/URL.  | Mögliche Ziele, Anforderungen, Einschränkungen, die das Produkt attraktiv machen.
| Kunde                 | Andreas Vogt, andreas.vogt@fhnw.ch          | Vertritt Primeo Energie AG, war in den letzten 3 Jahren bereits Kunde bei der FHNW und hat Board Games und Arcade Games in Auftrag gegeben.        | Spielerischer Faktor des Spiels muss gewährleistet sein, erneuerbare Energien müssen eine Rolle spielen. Muss das Max Flow Problem beinhalten
| Auftraggeber (FHNW)   | Barbara Scheuner, barbara.scheuner@fhnw.ch  | nimmt jährlich Aufträge an, welche realisierbar für das Projekt IP12 sind. Eine Jury wird das Produkt am Ende bewerten.                            | Erfüllung von Deadlines und Abgabeterminen.
| Qualitätsmanager      | Shane Zulauf, shane.zulauf@students.fhnw.ch  | Verantwortlich für die Entwicklung und Einhaltung | Einhaltung der Qualitätsanforderungen im Projekt
| Projektmanager        | Ron Gürber, ron.guerber@students.fhnw.ch | Verantwortlich für das initiieren, Planen, Steuern, Kontrollieren und Abschliessen des Projekts.                | Mitarbeit von Teammitgliedern, Einhaltung von Terminen
|=========================================================================================================================================================================================================================================================================================================================================================================

Features

.Features
[options="header"]
|==========================================================================================================================================================================================================================================================================================================================================================================================================================================================================================================
| ID  | Name                            | Wichtigkeit  | Aufwand  | Kurzbeschreibung                                                                                                                                                                                     | Ziele                                                                                                                                            | Implementierung
| F101 | [line-through]#RFID Daten auslesen# | [line-through]#high# | [line-through]#high#
| [line-through]#Das System sollte die vom User gelegten Bausteine auslesen können.#
| [line-through]#Spieler können ihren Spielzug auf dem Spielfeld realisieren#
| [line-through]#RFID reading in Java#

| F102 | Button Input an Edge erkennen           | high         | high     | Das System sollte nach jetzigen Plan mindestens 20 individuelle ansteuerbare Buttons besitzen | Spieler können ihren Spielzug auf dem Spielfeld realisieren                     | Buttons event handling Java

| F103 | Kontrollleuchte neben den Gebäuden  | high         | low      | Knotenpunkte besitzen eine Kontrollleuchte, damit der Spieler erkennen kann, ob seine Lösung erlaubt ist. Auch kann mit der Kontrollleuchte der Startpunkt und Zwischen-/Endpunkt angezeigt werden.  | System hat die möglichkeit dem User seinen Fehler darzustellen.| LED auf dem Spielfeld sind alle einzeln Ansteuerbar.
| F104 | Levelauswahl                    | high       | high     | Auf einem Touch Bildschirm werden Buttons für verschiedene Levels dargestellt. Mit drücken auf den Bildschirm auf einen Button wird ein Level ausgewählt. Das System weiss somit welches vordefinierte Level dem User dargestellt werden soll.
| System gibt dem User die Möglichkeit das Spiel, an seinen gewollten Schwierigkeitsgrad anzupassen.
| Touch-Bildschirm
| F05| Physische Spielanleitung        | medium       | low       | Auf dem Holz des Board Games ist die Spielanleitung zum Spiel geschrieben.                                                                                                                           | Der Spieler muss nicht den Bildschirm bedienen um die Spielanleitung zu lesen und kann während des Spielens jederzeit die Spielanleitung lesen.  | Laserdruck auf Holz, Klebstoff auf Holz
| F06 | Touch Screen                    | medium       | high     | Mithilfe eines Touch Screens kann die Levelauswahl betätigt werden, der Highscore kann angezeigt werden und bei einem Fehler des Spielers kann dies auch angezeigt werden.                           | Der Spieler tippt auf den Bildschirm, um weitere Level spielen zu können                                                                         | Verkabelung mit RPi und programmierung auf RPi, dann Einsetzung in Holzrahmen
|==========================================================================================================================================================================================================================================================================================================================================================================================================================================================================================================

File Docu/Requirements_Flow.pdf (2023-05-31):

# Requirements

# Umgehen mit neuen Requirements

Falls neue Requirements aufkommen oder bestehende Requirements geändert werden müssen, wird dies innerhalb des Teams besprochen. Zusätzlich wird der Kunde über die Änderung informiert und gefragt, ob er mit dieser Entscheidung zufrieden ist.

Bei grossen Änderungen ist es von Vorteil, ein Meeting mit dem Kunden aufzusetzen, um Alternativen gemeinsam finden zu können.

Geänderte und neue Requirements per 12.04.2023:

Geändert:

F101: siehe Arc42 Dokument

F201: Es werden nicht bei jedem Knotenpunkt Spielbausteine gelegt, sondern nur noch an einem Ort auf dem Spielfeld. Die Knoten werden per Knopfdruck (F301) ausgewählt.

F204.4 (geändert 19.04.): Level 4 wird nicht weiter verfolgt, da während des Meetings am selben Tag gemerkt wurde, dass mehr Zeit in die UX fliessen muss.

Neu:

F301: Buttons an Edges

Future Requirements (Entscheid 17.05.2023)

F401: Level 4

F402: RFID Leser für Gewichtung

# Priorisierung der Requirements

## Top10-Methode

Feature | Name | Votes
F101 | RFID Daten auslesen | 7
F102 | Kontrollleuchten neben den Gebäuden 7
F103 | Levelauswahl | 5
F201 | Spielbausteine | 7
F202 | Kontrollleuchten | 7
F203 | Display | 5
F204 | Physische Spielanleitung | 0
F205 | QR Code | 4

# Glossar

KL | Kontrollleuchte neben einem Knotenpunkt. Leuchtet diese grün, herrscht Input >= Output. Leuchtet diese rot, herrscht Input<Output

EL | Edge Leuchte. Zeigt an, wieviel Einheiten im Moment durch die Edge fliessen.
Display | Touch-Bildschirm, eingebaut im Spielbrett und gesteuert durch den RasperryPi.
Information von EL nach Farbe | gegebene Information
Cyan #48D3FA | 1 Einheit
Gelb #E6D801 | 2 Einheiten
Violett #8500E5 | 3 Einheiten
Rot #EB2000 | Fehler
"Blinkend" | Edge ist im Moment ausgewählt

Die Farbcodes können mit den RGB LEDs nicht genau dargestellt werden und werden so nah wie möglich dem Hexcode angeglichen

# Feature F202: Kontrollleuchten neben Knotenpunkte

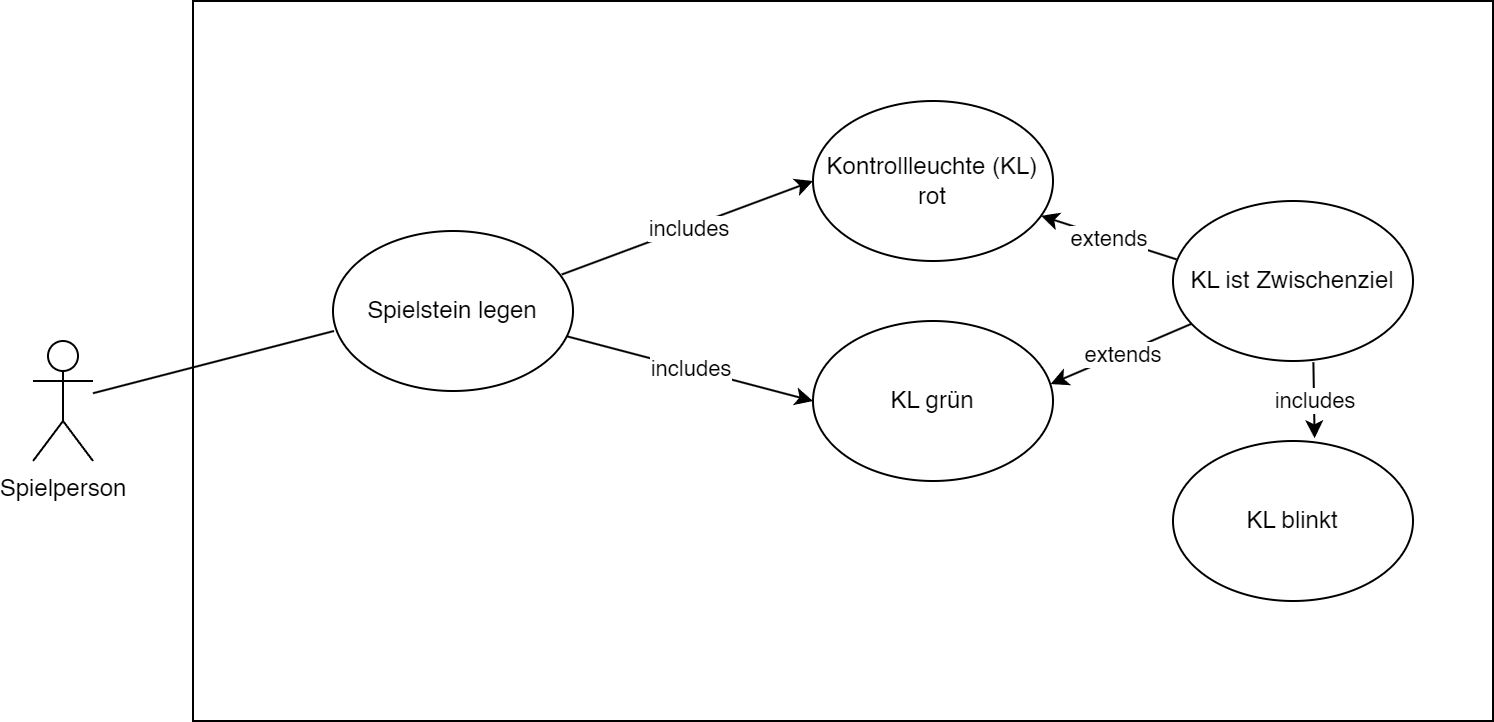
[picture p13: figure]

Name | Beschreibung
ID | F202.UC01
Name | Wert der anliegenden Edge ändern
Summary | Die Spielperson ändert den Wert einer anliegenden Edge, die KL reagiert auf die Aktion der Spielperson
Actor | Spielperson
Precondition | Level wurde gestartet.
| Eine Edge wurde ausgewählt
Post-Condition | a) Ein anderer Button wird gedrückt
b) Das Spiel wurde beendet
Trigger | Ein Spielbaustein wird auf den RFID Reader gelegt.

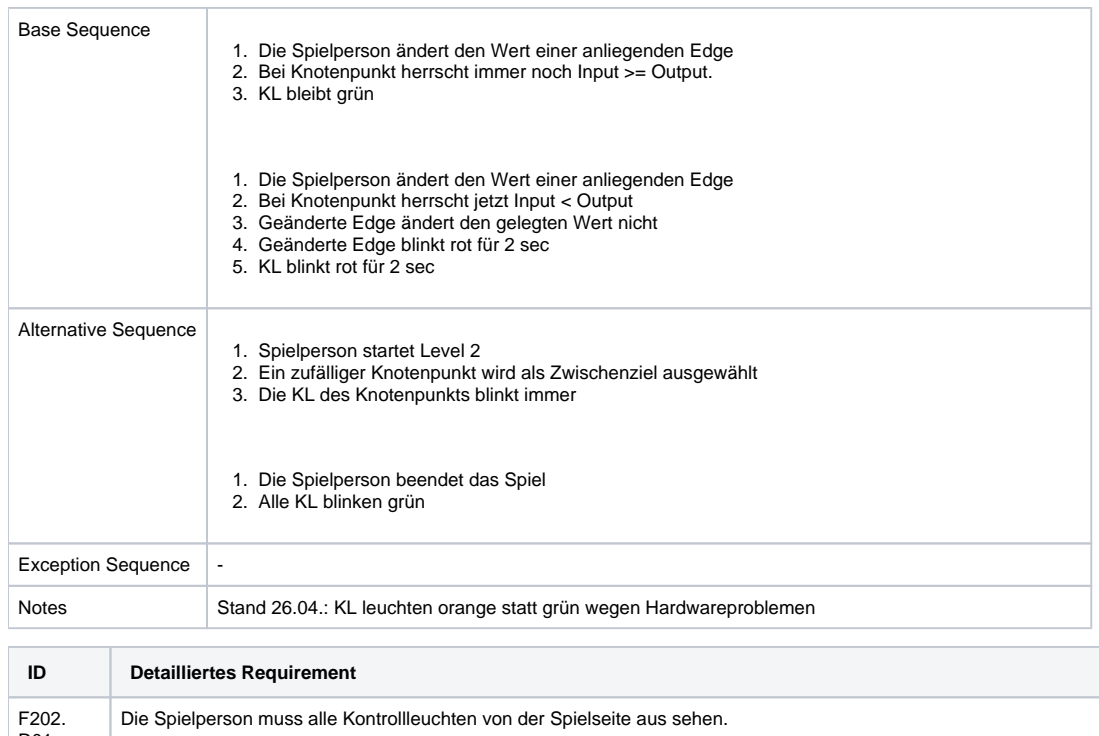
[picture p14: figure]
Base Sequence; KL bleibt grün; Geänderte Edge blinkt rot für 2 sec KL blinkt rot für 2 sec; Alternative Sequence; Spielperson startet Level 2; Die KL des Knotenpunkts blinkt immer; Die Spielperson beendet das Spiel Alle KL blinken grün; Exception Sequence; Detailliertes Requirement

Die Spielperson ändert den Wert einer anliegenden Edge Bei Knotenpunkt herrscht immer noch Input >= Output.

Die Spielperson ändert den Wert einer anliegenden Edge Bei Knotenpunkt herrscht jetzt Input < Output
Geänderte Edge ändert den gelegten Wert nicht

Ein zufälliger Knotenpunkt wird als Zwischenziel ausgewählt

Notes | Stand 26.04.: KL leuchten orange statt grün wegen Hardwareproblemen

R01

Die Spielperson muss alle Kontrollleuchten von der Spielseite aus sehen.

F202.
R02

Die Spielperson muss die Kontrollleuchten in ihrer Farbe unterscheiden können, auch wenn die Spielperson eine Rot/Grün Schwäche besitzt.

F202.
R03

Die Spielperson muss ihre Veränderung auf dem Spielfeld über die Kontrollleuchten innerhalb 3 Sekunden sehen.

F202.
R04

Die Spielperson kann ihre Veränderung auf dem Spielfeld über die Kontrollleuchten innerhalb 0,5 Sekunden sehen.

# Feature F203: Display

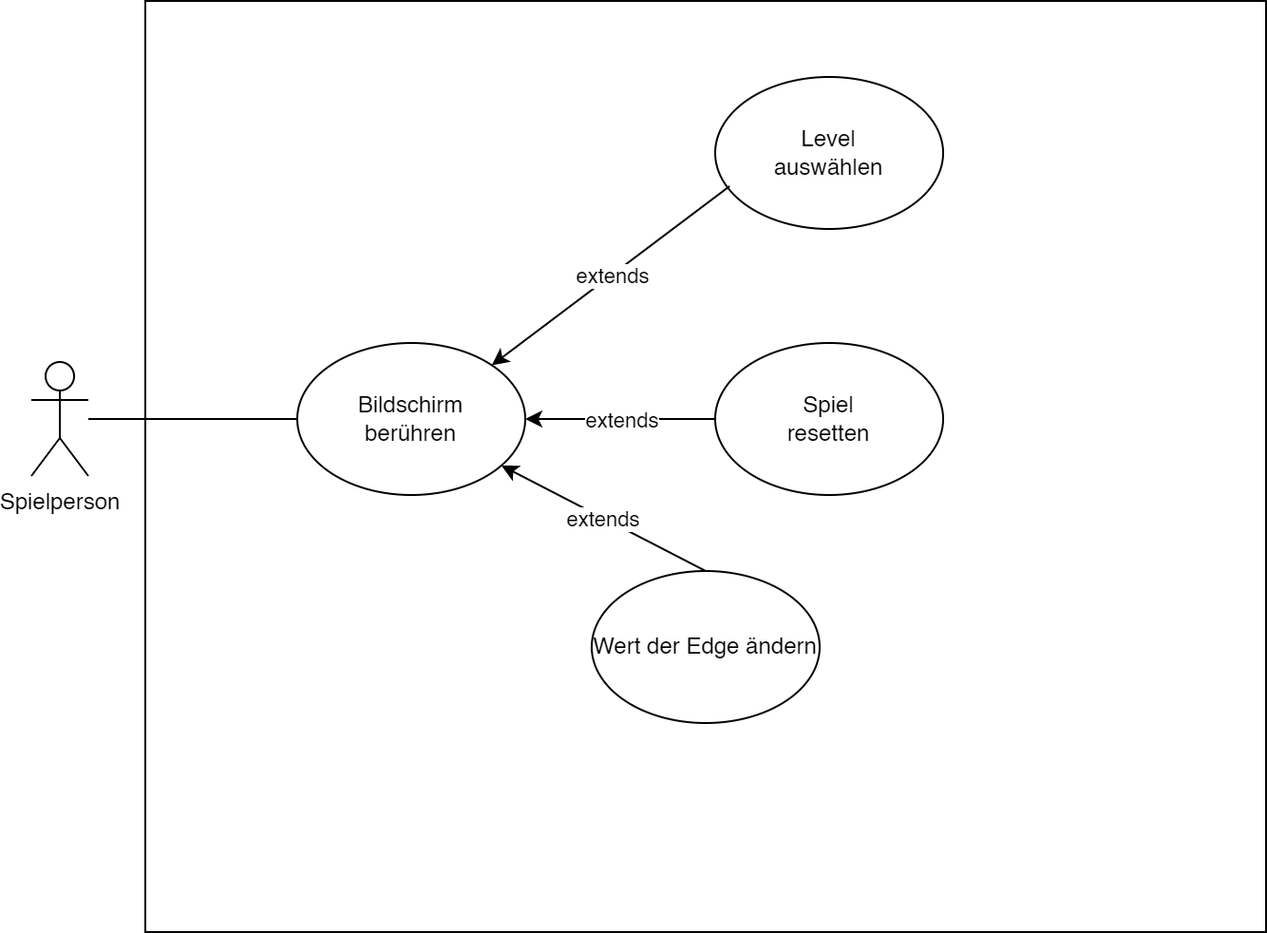
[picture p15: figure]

1.
2.
3.
4.
Name | Beschreibung
ID | F203.UC01
Name | Level auswählen
Summary | Die Spielperson kann auf dem Display zwischen 4 spielbaren Levels auswählen, wobei Level 1 die einfachste und Level 4 die schwerste Spielerfahrung bietet.
Actor | Spielperson

Precondition
| Es befinden sich keine Spielsteine auf dem Spielfeld. Der Bildschirm ist eingeschaltet

Post-Condition
| Das Spiel wurde gestartet
Trigger | Die Spielperson drückt auf die Levelauswahl und wählt mit einem Klick ein Level aus.

Base Sequence
| Spielperson drückt auf dem Bildschirm die Schaltfläche "Levelauswahl" an. Der Display zeigt nun die verschiedenen Level an. Spielperson drückt auf ein Level. Das System startet das ausgewählte Level.
Alternative Sequence | -

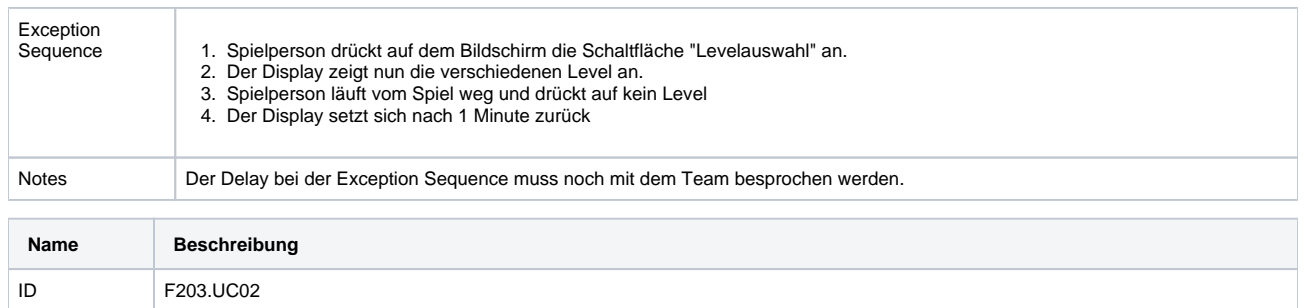
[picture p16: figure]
Exception; Name; Beschreibung

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
Sequence | Spielperson drückt auf dem Bildschirm die Schaltfläche "Levelauswahl" an. Der Display zeigt nun die verschiedenen Level an. Spielperson läuft vom Spiel weg und drückt auf kein Level Der Display setzt sich nach 1 Minute zurück
Notes | Der Delay bei der Exception Sequence muss noch mit dem Team besprochen werden.
Name | Spiel resetten
Summary | Die Spielperson ist in der Lage, durch einen Klick auf dem Bildschirm das Spiel komplett zurücksetzten zu können. Dies ist nötig, falls
| die vorherige Spielperson ein Level nicht beendete.
Actor | Spielperson

Precondition
| Ein Level ist laufend

Post-Condition
| Der Bildschirm zeigt das Hauptmenu
Trigger | Die Spielperson drückt auf dem Bildschirm die Schaltfläche "Spiel resetten" an.

Base
Sequence | Spielperson drückt auf dem Bildschirm die Schaltfläche "Spiel resetten" an.
| System beendet das Spiel.
| Display zeigt keinen Highscore an, aber fordert die Spielperson auf, alle Spielbausteine auf dem Feld zu entfernen.
| Spielperson drückt "ok" auf dem Bildschirm
| Display zeigt Hauptmenu an
| Spielperson kann ein neues Level starten.

Alternative
Sequence | Spielperson drückt auf dem Bildschirm die Schaltfläche "Spiel resetten" an, ohne dass sie dies wollte.
| System beendet das Spiel.
| Display zeigt keinen Highscore an, aber fordert die Spielperson auf, alle Spielbausteine auf dem Feld zu entfernen.
| Spielperson drückt "ok" auf dem Bildschirm.
| Display zeigt Hauptmenu an
| Spielperson kann ein neues Level starten.
Exception | -

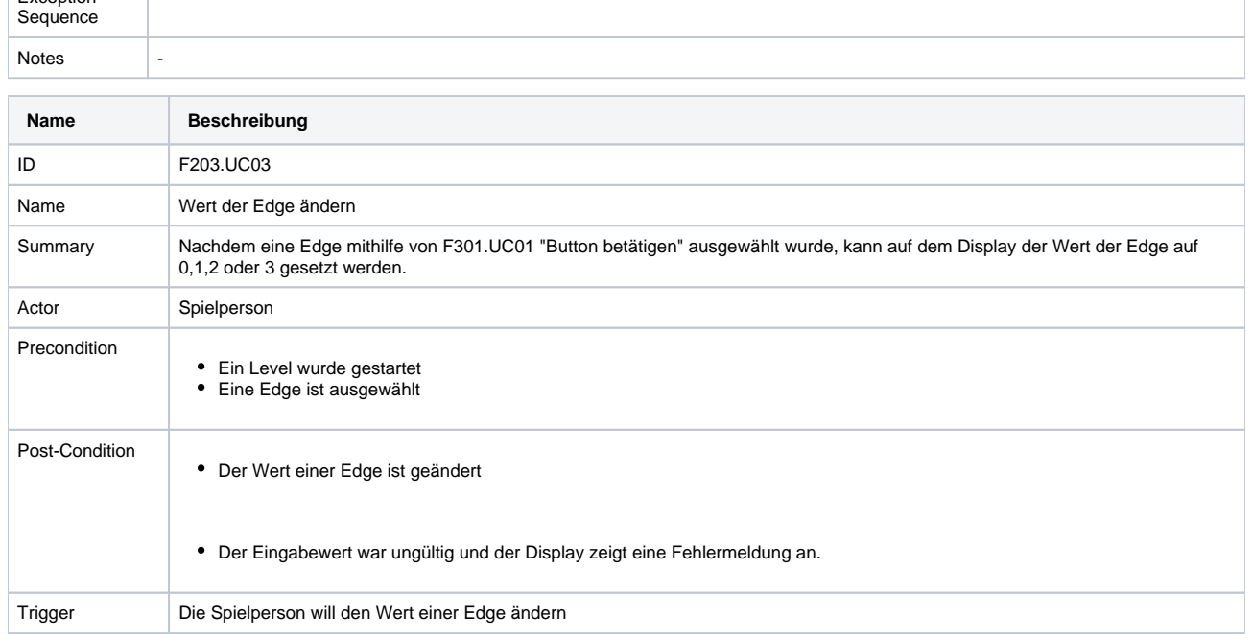
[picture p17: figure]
Sequence; Notes; Name; Beschreibung; Wert der Edge ändern; 0,1,2 oder 3 gesetzt werden.; Actor; Spielperson; Precondition; Ein Level wurde gestartet Eine Edge ist ausgewählt; Post-Condition; Der Wert einer Edge ist geändert

Summary | Nachdem eine Edge mithilfe von F301.UC01 "Button betätigen" ausgewählt wurde, kann auf dem Display der Wert der Edge auf

Der Eingabewert war ungültig und der Display zeigt eine Fehlermeldung an.

Trigger | Die Spielperson will den Wert einer Edge ändern

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
Base Sequence
Spielperson drückt auf die Schaltfläche 0,1,2 oder 3, um den Wert der ausgewählten Edge zu ändern
Es wird geprüft, ob Maximalkapazität der Edge überschritten wurde
Es wird geprüft, ob bei der ausgehenden Node nach Anwenden des Wertes immer noch Input >= Output herrscht Der Wert wird übernommen
Die Edge leuchtet in entsprechender Farbe

Alternative
Sequence | Spielperson drückt auf die Schaltfläche 0,1,2 oder 3, um den Wert der ausgewählten Edge zu ändern
| Es wird geprüft, ob Maximalkapazität der Edge überschritten wurde
| Sie wurde überschritten
| Der Wert wird nicht übernommen
| Die Edge blinkt rot für 3 Sekunden und blinkt dann in der vorherigen Farbe
| Der Display zeigt "Fehlermeldung 1" für 5 Sekunden an.

Spielperson drückt auf die Schaltfläche 0,1,2 oder 3, um den Wert der ausgewählten Edge zu ändern
Es wird geprüft, ob Maximalkapazität der Edge überschritten wurde
Es wird geprüft, ob bei der ausgehenden Node nach Anwenden des Wertes immer noch Input >= Output herrscht Es herrscht Input < Output
Der Wert wird nicht übernommen
Die Edge blinkt rot für 3 Sekunden und blinkt dann in der vorherigen Farbe
Gleichzeitig blinkt die Kontrollleuchte neben der entsprechenden Node Rot für 4 Sekunden Der Display zeigt "Fehlermeldung 2" für 5 Sekunden an.

Exception
Sequence | Die Spielperson drückt auf die Schaltfläche mit dem bereits existierendem Wert der Edge.
| Nichts passiert
Notes | Fehlermeldung 1: "Maximale Kapazität wurde überschritten!"
| Fehlermeldung 2: "Das anliegende Haus hat nicht so viel Strom zur Verfügung!"
ID | Detailliertes Requirement

F203.R01 Die Spielperson muss ein Level auswählen können.

F203.R02 Die Spielperson muss nicht bei Level 1 beginnen.

F203.R03 Die Spielperson muss ein Level abbrechen können.

F203.R04 Die Spielperson muss ihre Lösung überprüfen können.

F203.R05 Die Spielperson sollte von alleine aus die Level in der Reihenfolge spielen.

F203.R06 Die Spielperson sollte eine zusätzliche Hilfestellung über den "Hilfe" Button erhalten

F203.R07 Die Spielperson muss ein Spiel resetten können

F203.R08 Die Spielperson kann ein Spiel abbrechen und weglaufen, ohne etwas zusätzliches tun zu müssen

# Feature F204.1: Level 1

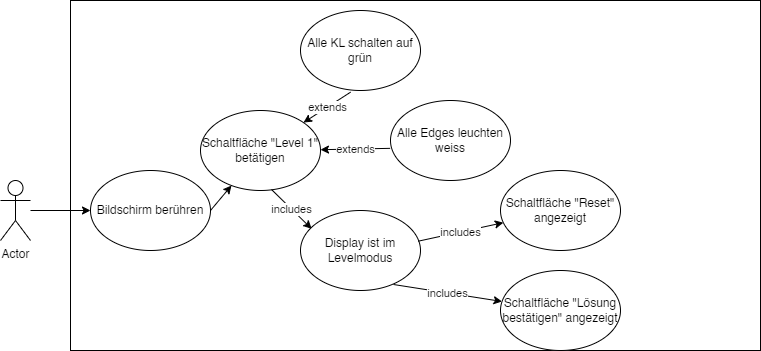
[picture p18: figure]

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
Name | Beschreibung
ID | F204.1.UC01
Name | Schaltfläche "Level 1" betätigen
Summary | Spielperson drückt auf die Schaltfläche "Level 1" und startet somit das erste Level.
Actor | Spielperson

Precondition
| Spielperson drückt auf F203.UC01 "Level auswählen" Es ist kein Spiel am laufen

Post-Condition
| Die Lösung des Spielers wird durch den Spieler mit einer Betätigung auf der Schaltfläche "Lösung bestätigen" eingegeben Ein Highscore wird auf dem Display angezeigt
Trigger | Spielperson drückt auf die Schaltfläche "Level 1"

Base Sequence
| Spielperson drückt auf Schaltfläche "Level 1" Level 1 wird gestartet Alle Knotenpunkte leuchten grün Alle Edges leuchten weiss Level 1 ist spielbar

Alternative Sequence -

Exception Sequence
| Ein Spiel wird bereits gespielt und die Schaltfläche "Level 1" ist fälschlicherweise verfügbar Spielperson drückt auf Schaltfläche "Level 1" Das Spiel wird resetted und das Level 1 wird gestartet

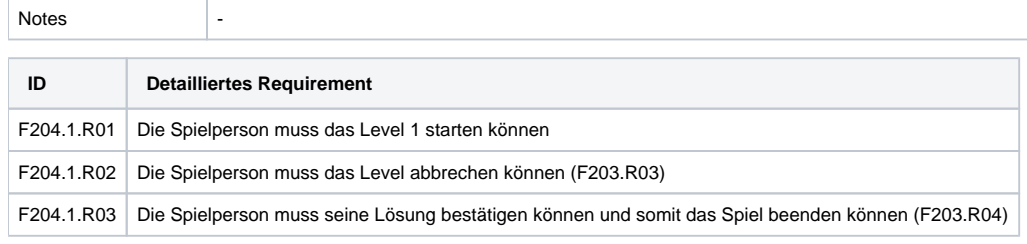
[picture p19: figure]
Notes; Detailliertes Requirement

F204.1.R01 Die Spielperson muss das Level 1 starten können

F204.1.R02 Die Spielperson muss das Level abbrechen können (F203.R03)

F204.1.R03 Die Spielperson muss seine Lösung bestätigen können und somit das Spiel beenden können (F203.R04)

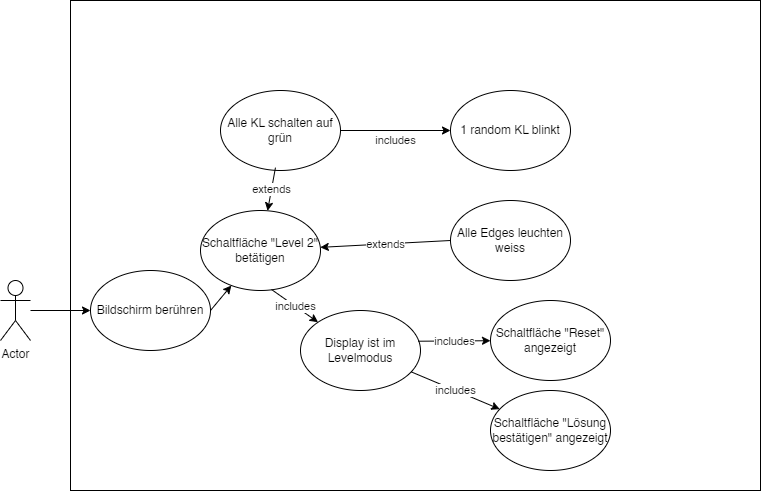
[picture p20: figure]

1.
2.
3.
4.
5.
6.

# Feature F204.2: Level 2

Name | Beschreibung
ID | F204.2.UC01
Name | Schaltfläche "Level 2" betätigen
Summary | Spielperson drückt auf die Schaltfläche "Level 2" und startet somit das zweite Level.
Actor | Spielperson

Precondition
| Spielperson drückt auf F203.UC01 "Level auswählen" Es ist kein Spiel am laufen

Post-Condition
| Die Lösung des Spielers wird durch den Spieler mit einer Betätigung auf der Schaltfläche "Lösung bestätigen" eingegeben Ein Highscore wird auf dem Display angezeigt
Trigger | Spielperson drückt auf Schaltfläche "Level 2"

Base Sequence
| Spielperson drückt auf Schaltfläche "Level 2" Level 2 wird gestartet Alle Knotenpunkte leuchten grün Ein zufälliger Knotenpunkt wird als Zwischenziel ausgewählt, dieser blinkt während der ganzen Dauer des Levels Alle Edges leuchten weiss Level 2 ist spielbar

Alternative Sequence -

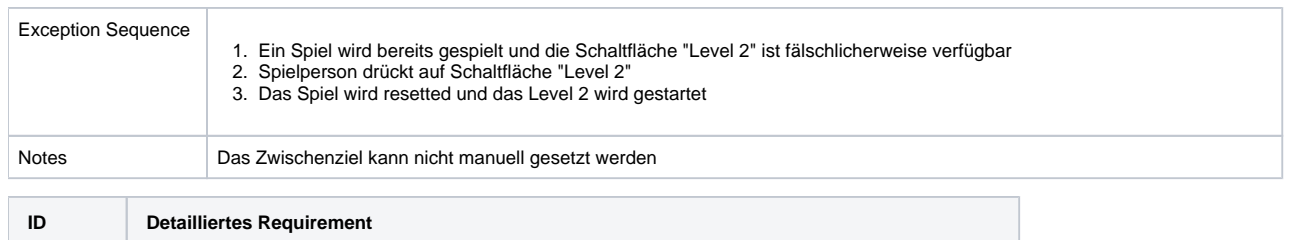
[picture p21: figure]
Exception Sequence; Detailliertes Requirement

Ein Spiel wird bereits gespielt und die Schaltfläche "Level 2" ist fälschlicherweise verfügbar Spielperson drückt auf Schaltfläche "Level 2"
Das Spiel wird resetted und das Level 2 wird gestartet
Notes | Das Zwischenziel kann nicht manuell gesetzt werden

F204.2.R01 Die Spielperson muss das Level 2 starten können

F204.2.R02 Die Spielperson muss das Level abbrechen können (F203.R03)

F204.2.R03 Die Spielperson muss seine Lösung bestätigen können und somit das Spiel beenden können (F203.R04)

# Feature F204.3: Level 3

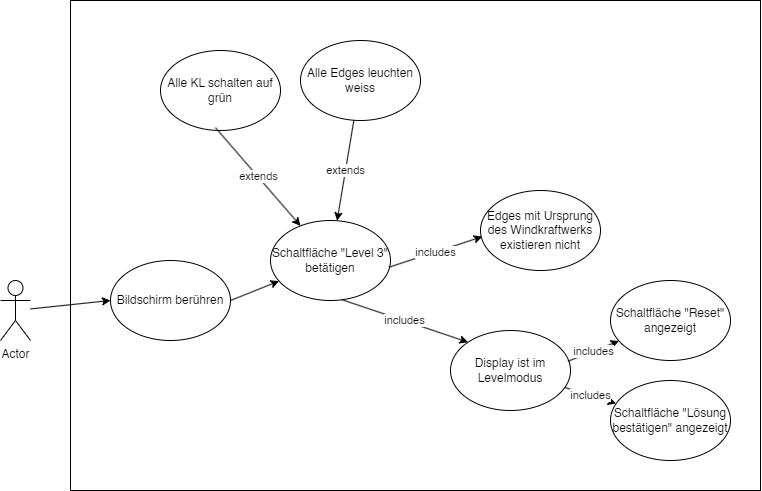
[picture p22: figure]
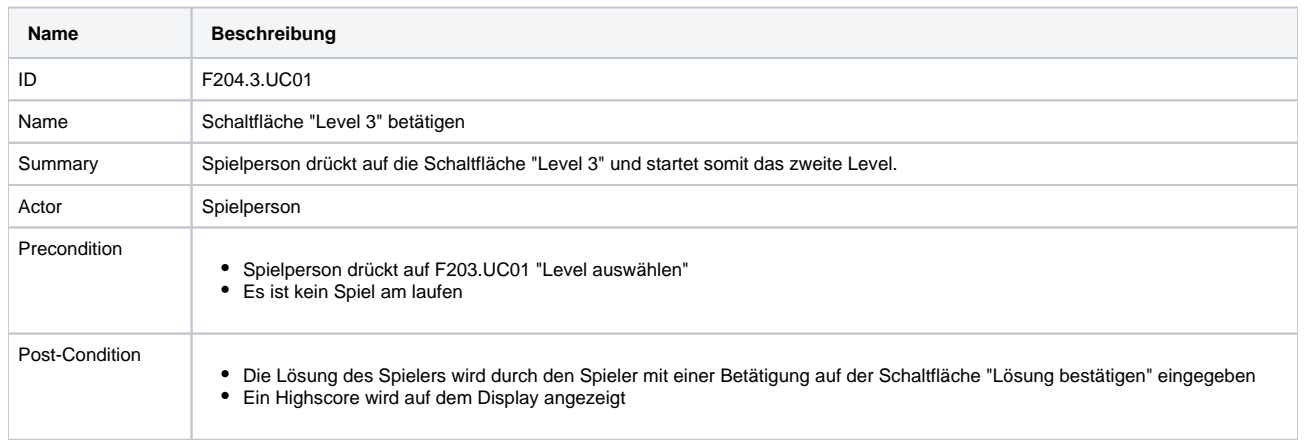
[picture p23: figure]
Name; Beschreibung; Schaltfläche "Level 3" betätigen; Actor; Spielperson; Precondition; Es ist kein Spiel am laufen; Post-Condition

Summary | Spielperson drückt auf die Schaltfläche "Level 3" und startet somit das zweite Level.

Spielperson drückt auf F203.UC01 "Level auswählen"

Die Lösung des Spielers wird durch den Spieler mit einer Betätigung auf der Schaltfläche "Lösung bestätigen" eingegeben Ein Highscore wird auf dem Display angezeigt

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
Trigger | Spielperson drückt auf Schaltfläche "Level 3"

Base Sequence
| Spielperson drückt auf Schaltfläche "Level 3"
| Level 3 wird gestartet
| Alle Knotenpunkte leuchten grün
| Die Edges ausgehend der Windkraftwerke sind nicht verfügbar
| Alle Edges leuchten weiss, ausser die eben Erwähnten
| Level 3 ist spielbar
Alternative Sequence | -

Exception
Sequence | Ein Spiel wird bereits gespielt und die Schaltfläche "Level 3" ist fälschlicherweise verfügbar
| Spielperson drückt auf Schaltfläche "Level 3"
| Das Spiel wird resetted und das Level 3 wird gestartet
Notes | Wird trotzdem ein Edge ausgehend der Windkraftwerke mithilfe der Knöpfe ausgewählt, passiert nichts. Die Edges beginnen nicht

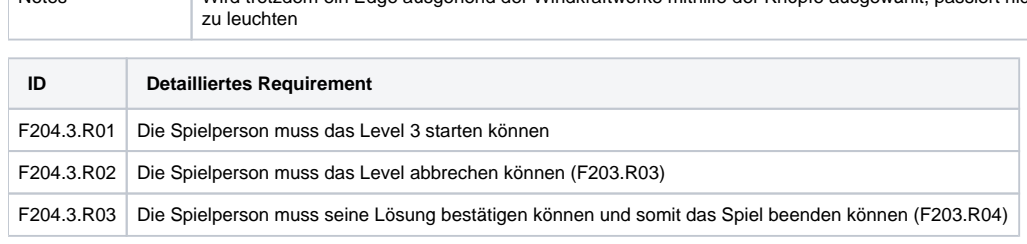
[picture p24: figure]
zu leuchten; Detailliertes Requirement

F204.3.R01 Die Spielperson muss das Level 3 starten können

F204.3.R02 Die Spielperson muss das Level abbrechen können (F203.R03)

F204.3.R03 Die Spielperson muss seine Lösung bestätigen können und somit das Spiel beenden können (F203.R04)

# Feature F205: Physische Spielanleitung


Name | Beschreibung
ID | F205.UC01
Name | Spielanleitung lesen
Summary | Die Spielperson kann die Spielanleitung direkt auf dem Spielbrett lesen, ohne dafür den Bildschirm verwenden zu müssen.
| Damit steht die Spielanleitung jederzeit für die Spielperson leserlich verfügbar.
Actor | Spielperson

Precondition
| keine

Post-Condition
Spielperson versteht die Spielregeln Spielperson wählt Level auf Display aus
Trigger | Person läuft zum Spielbrett.

Base Sequence
| Person läuft zum Spielbrett heran und wird damit zur Spielperson Spielperson liest die Spielregeln Spielperson versteht die Spielregeln Spielperson startet ein beliebiges Level auf dem Display

Alternative Sequence
| Person läuft zum Spielbrett heran und wird damit zur Spielperson Spielperson liest die Spielregeln Spielperson versteht die Spielregeln Spielperson läuft wieder weg und ist damit keine Spielperson mehr
| 2. Person läuft zum Spielbrett heran und wird damit zur Spielperson Spielperson liest die Spielregeln Spielperson versteht die Spielregeln nicht Spielperson läuft wieder weg und ist damit keine Spielperson mehr

Exception Sequence
| Spielperson liest die Spielregeln nicht fertig

Notes; Detailliertes Requirement

F205.R01 Die Spielperson muss die Spielregeln innerhalb von 2min30sec gelesen und verstanden haben

F205.R02 Die Spielperson soll die Spielregeln innerhalb von 1min gelesen und verstanden haben

F205.R03 Die Spielperson kann die Spielregeln innerhalb von 30sec gelesen und verstanden haben

# Feature F206: QR Code


Name | Beschreibung

1.
2.
3.
ID | F206.UC01
Name | QR Code scannen
Summary | Spielperson scannt den QR Code auf dem Brett und wird dann auf die Webseite weitergeleitet, auf der das Max-Flow Problem genauer
| erklärt wird. Ebenfalls ist ein Link zur FHNW Website verfügbar
Actor | Spielperson

Precondition
| Spielperson interessiert sich um die Funktionalität und den Sinn des Spiels
| Spielperson erkennt den QR Code auf dem Spielbrett

Post-
Condition | Spielperson versteht den Sinn des Spiels und dessen Wichtigkeit im Zusammenhang mit der Umwelt
Trigger | Spielperson hat Interesse, mehr über das Problem zu lernen

Base
Sequence | Spielperson hat ein Level beendet
| Spielperson interessiert sich mehr für das Problem
| Spielperson sieht den QR Code und scannt diesen
Alternative Sequence | -
Exception | -

Sequence; Notes; Name; Beschreibung; Link auf der FHNW Seite; Actor; Spielperson; Precondition; Spielperson scannt QR Code; Post-Condition; Base Sequence; Spielperson drückt auf den FHNW Link; Alternative Sequence -; Exception Sequence; Detailliertes Requirement

Summary | Spielperson kann auf der Webseite einen Link finden, der auf die FHNW Projektseite weiterleitet

Spielperson liest den Inhalt der durch den QR Code geöffnete Website

Spielperson lernt andere Projekte der FHNW kennen

Trigger | Spielperson hat Interesse an anderen Projekten der FHNW

Spielperson scrollt durch die durch de QR Code geöffnete Website

F206.R01 Die Spielperson muss den QR Code mit der Kamera seines Smartphones scannen können

F206.R02 Die Spielperson soll den QR Code innerhalb 3sec scannen können

# Feature F301: Buttons an Edges


1.
2.
3.
4.
5.
6.
7.
Name | Beschreibung
ID | F301.UC01
Name | Button betätigen
Summary | Die Spielperson will den Wert einer Edge ändern und betätigt dafür den Button neben einer Edge
Actor | Spielperson, RasperryPi

Precondition
| Beliebiges Level ist gestartet

Post-Condition
| Ein anderer Button wird gedrückt
| oder
| Das Spiel wird beendet/resetted
Trigger | Die Spielperson will den Wert einer Edge ändern, um entweder einen Fehler auszugleichen oder im Spiel voranzukommen.

Base Sequence
| Spielperson drückt auf den Button neben einer Edge Edge blinkt in momentaner Farbe Spielperson legt Spielstein auf RFID Reader Wert der Edge ändert sich auf den des Spielsteins Edge blinkt in Farbe des Spielbausteins Spielperson drückt auf den Button neben einer anderen Edge Vorherige Edge leuchtet (blinkt nicht mehr)

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
Alternative Sequence
Spielperson drückt auf den Button neben einer Edge
Es liegt bereits ein Spielstein auf dem RFID Reader
Edge nimmt sofort den Wert des Spielsteins an und blinkt in spezifischer Farbe

Spielperson startet Level
Alle Edges leuchten weiss
Spielperson drückt auf den Button neben einer Edge
Edge blinkt weiss

Spielperson drückt auf den Button neben einer Edge Edge blinkt
Spielperson beendet das Spiel
Edge hört auf zu blinken.
Falls durch Edge Strom geflossen ist, leuchtet sie blinkt sie grün

Exception Sequence
Spielperson drückt auf den Button neben einer Edge
Edge blinkt in momentaner Farbe
Spielperson legt Spielstein auf RFID Reader
Der Wert des Spielsteins übersteigt die Maximalkapazität der Edge Edge blinkt rot für 2 Sekunden
Edge nimmt den vorherigen Wert wieder an und blinkt in dieser Farbe

Spielperson drückt auf den Button neben einer Edge
Edge blinkt in momentaner Farbe
Spielperson legt Spielstein auf RFID Reader
Der anliegende Knotenpunkt hat nicht so viel Einheiten für die Weitergabe zu Verfügung Der Knotenpunkt blinkt rot für 2 Sekunden
Die Edge blinkt rot für 2 Sekunden
Edge nimmt den vorherigen Wert wieder an und blinkt in dieser Farbe
Notes | Ein fehlerhafter Wert wird nie gespeichert

F301.R01 Spielperson kann 100ms nach dem Drücken auf den Button den Wert der Edge ändern.

F301.R02 Spielperson kann alle Buttons erreichen, wenn sie an der Seite des Displays steht.

F301.R03 Spielperson kann nicht 2 Edges gleichzeitig auswählen.

# Anhänge

# Zukünftige Anforderungen

# F401: Level 4


1.
2.
3.
4.

1.
2.
3.
Name | Beschreibung
ID | F204.4.UC01
Name | Schaltfläche "Level 4" betätigen
Summary | Spielperson drückt auf die Schaltfläche "Level 4" und startet somit das zweite Level.
Actor | Spielperson

Precondition
| Spielperson drückt auf F203.UC01 "Level auswählen"
| Es ist kein Spiel am laufen

Post-Condition
| Die Lösung des Spielers wird durch den Spieler mit einer Betätigung auf der Schaltfläche "Lösung bestätigen" eingegeben
| Ein Highscore wird auf dem Display angezeigt
Trigger | Spielperson drückt auf Schaltfläche "Level 4"

Base Sequence
| Spielperson drückt auf Schaltfläche "Level 4"
| Level 4 wird gestartet
| Alle Knotenpunkte leuchten rot, ausser der Knotenpunkt ist ein Haus mit Solardach. Diese KL leuchtet grün
| Level 4 ist spielbar
Alternative Sequence | -

Exception
Sequence | Ein Spiel wird bereits gespielt und die Schaltfläche "Level 4" ist fälschlicherweise verfügbar
| Spielperson drückt auf Schaltfläche "Level 4"
| Das Spiel wird resetted und das Level 4 wird gestartet

Notes | Wird trotzdem ein Edge ausgehend der Windkraftwerke mithilfe der Knöpfe ausgewählt, passiert nichts. Die Edges beginnen nicht zu leuchten
ID | Detailliertes Requirement

F204.4.R01 Die Spielperson muss das Level 4 starten können

F204.4.R02 Die Spielperson muss das Level abbrechen können (F203.R03)

F204.4.R03 Die Spielperson muss seine Lösung bestätigen können und somit das Spiel beenden können (F203.R04)

F204.4.R04 Die Spielperson sollte eine Lösung innerhalb von 2 Minuten bestätigen können.

F204.4.R05 Die Spielperson muss eine Lösung innerhalb von 3 Minuten bestätigen können.

# F402: RFID Leser für Gewichtung


Name | Beschreibung
ID | F302.UC01
Name | Spielstein auf RFID Leser legen
Summary | Die Spielperson kann drei verschiedene Spielsteine auf den RFID Leser legen, mit dem sie die Werte 1, 2 oder 3 auf der ausgewählten
| Edge speichert.
Actor | Spielperson

Precondition
| Spielperson hat ein Level gestartet
| Spielperson nimmt einen Spielstein in die Hand

Post-
Condition | Wert der aktiven Edge wurde geändert
Trigger | Spielperson will Wert einer Edge ändern

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
Base
Sequence | Spielperson wählt eine Edge aus
| Spielperson legt Spielstein auf RFID Leser
| Wert der Edge verändert sich
| Edge leuchtet in anderer Farbe
| Spielperson wählt eine andere Edge aus

Alternative
Sequence | Spielperson legt Spielstein auf RFID Leser
| Spielperson wählt eine Edge aus
| Wert der Edge verändert sich
| Edge leuchtet in anderer Farbe
| Spielperson wählt eine andere Edge aus

Exception
Sequence | Spielperson wählt eine Edge aus
| Spielperson legt Spielstein auf RFID Leser
| Wert der Edge verändert sich nicht
| Farbe der Edge bleibt unverändert
Notes | Wird eine neue Edge mit betätigen eines Buttons (F301.UC02) ausgewählt, muss der Spielstein nicht ein weiteres Mal aufgelegt
| werden. Es wird sofort der Wert, welcher auf dem RFID Leser liegt genommen.
ID | Detailliertes Requirement

F204.R01 Spielperson muss Änderung der Spieloberfläche nach legen des Spielsteins innerhalb von 1 Sekunde sehen

F204.R02 Spielperson soll Änderung der Spieloberfläche nach legen des Spielsteins innerhalb von 200ms sehen

F204.R03 Spielperson muss sich nicht achten, dass der Spielbaustein korrekt auf dem Feld liegt.

F204.R04 Spielperson kann den Spielbaustein auf dem Feld liegen lassen und eine andere Edge auswählen,

# Verworfene Requirements und Features

# Feature F201: Spielbausteine (verworfen)


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
Summary | Die Spielbausteine sind Stromblöcke, welche von der Spielperson gelegt werden. Es ist die Hauptkomponente des Spiels.
Actor | Spielperson
Pre-conditions | Ein Level wurde gestartet.
Post-conditions | Update von Spielstatus pending.
| Spielstatus aktualisiert.
| Kontrollleuchte ändert ihre Farbe.
Trigger | Spielbaustein auf ein valides Spielfeld gelegt

Base Sequence
| Spielperson nimmt Spielbaustein in die Hand Spielperson legt Spielbaustein auf ein valides Feld Kontrollleuchte am vorherigen Kontrollpunkt leuchtet grün

Alternative Sequence
| Spielperson nimmt Spielbaustein in die Hand Spielperson legt Spielbaustein auf ein valides Feld Kontrollleuchte am vorherigen Knotenpunkt leuchtet magenta

Spielperson nimmt Spielbaustein in die Hand
Spielperson legt Spielbaustein auf ein invalides Feld
RasperryPi erkennt Fehler
Auf dem Bildschirm erscheint eine Info, ein Spielbaustein ist falsch plaziert Kontrollleuchte am vorherigen Knotenpunkt leuchtet magenta

Exception Sequence
Energie unterbrochen
Spielperson weiss nicht, ob Spielzug valid ist

Notes; Name; Beschreibung; Spielbaustein entfernen; Actor; Spielperson; Pre-conditions; Ein Spielbaustein wurde gelegt.; Post-conditions; Update von Spielstatus pending.; Spielstatus aktualisiert.; Kontrollleuchte ändert ihre Farbe.; Base Sequence; Kontrollleuchte ändert seine Farbe; Exception Sequence; Energie unterbrochen; Detailliertes Requirement

Summary | Die Spielbausteine können von der Spielperson vom Spielbrett entfernt werden.
Trigger | Spielbaustein wurde von der Spielperson entfernt.
| Spielperson nimmt den Spielbaustein vom Spielbrett

Spielperson weiss nicht, ob Spielzug erkannt wurde.

F201.R01 Die Spielperson muss die Spielbausteine mit einer Hand bewegen können

F201.R02 Die Spielperson muss genügend Spielbausteine zur Verfügung haben, das Spiel lösen zu können

F201.R03 Die Spielperson muss die Spielbausteine legen können, ohne die Spielfläche zu zerstören

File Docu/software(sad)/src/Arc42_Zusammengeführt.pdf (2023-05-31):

# Einführung und Ziele

In diesem Kapitel wird auf die Aufgabenstellung, die funktionalen Anforderung, dies das Produkt beschriebt sowie auch die Qualitätsziele eingegangen. Ausserdem werden die Stakeholder und ihre Erwartungshaltung definiert. Dies soll einen Überblick über die Rahmenbedingungen des Systems bieten.

# Aufgabenstellung

In der Aufgabenstellung wird dies näher angeschaut und das Produkt erläutert.

# Was ist "Produktname"?

Wie genau das Stromnetz aufgebaut wissen wenige, mit der steigenden "Awareness" bezüglichem der effizienten Stromnutzung und auch der optimalen Verteilung des Stroms innerhalb des Netzes an die jeweiligen Endnutzer. bzw. zur Abstraktion in unserem Fall Häuser.

Unser Produkt, mit dem Namen "Produktname" soll diese optimale Verteilung, basierend auf dem "Max-flow-Algorithmus" anschaulich dargestellt werden.

- Thematisiert die Komplexität der Verteilung von Strom im Stromnetz
- Interaktiver Umgang mit den einzelnen "Edges" und den "Kapazitäten"
- Die optimale Verteilung wird als anstrebendes Ergebniss dem Nutzer übergeben. Der Spieler versucht also durch überlegen, selber auf die beste Verteilungs-möglichkeit zu kommen.

# Wesentliche Features

Die wesentlichen Features sind:

- Strategisches Spiel, bzw. "Quiz".
- Wiederspielbarkeit bzw. "replayability", da Anpassung auf den eigenen Wissenstand möglich, da Levelauswahl vorhanden.
- Wissensübertrag, Verständniss bezüglich Stromnetz wird erhört.

# Qualitätsziele

Die Qualitätsziele umfassen die wichtigsten Qualitätsanforderung an das Spiel mit dem Namen "Produktname". Sie sind nach Priorität in der folgenden Tabelle geordnet.

Table 1. Qualitätsziele
Qualitätsziel | Motivation und Beschreibung
Benutzbarkeit: | Der Aufwand der Nutzung für die User sollte minimal sein.

Zuverlässigkeit: | Unser System soll die zugewiesene Funktion in einem, von uns noch zu definierenden Zeitfenster erledigen.
Robustheit: | Da mit greifbaren Teilen, Knöpfen und Spielfiguren gespielt werden kann, sollen diese Robust und gleichzeitig "wartbar" sein.
Effizienz: | Da unser Spiel live demonstriert wird, ist es wichtig, dass die Berechnungen schnell erledigt werden..

Auszug aus den Produktzielen unserer Confluence Seite (https://www.cs.technik.fhnw.ch/confluence20/display/VT122208/Produktvision)

Table 2. Produktziele
ID | Name | Beschreibung | Messung | Soll-Wert
| Kurzer Name des Ziels | Beschreibung des Zieles im Detail, inkl. in welcher Situation bzw. durch wen das Ziel erreicht werden soll. | Wie in einer Demo/Nutzerte st die Zielerreichung überprüft werden soll | Schwellwert, um auszusagen "Ziel ist erreicht."

Z01 | Bewusstsein & Energienutzung

Die
Besucher:innen
der Ausstellung
der Primeo
Energie AG in
Münchenstein
sollen ein
Bewusstsein für
die Nutzung
von Strom
entwickeln. Ziel
ist es, dass
Strom nicht als
Selbstverständli
chkeit
angeschaut
wird und man
dadurch
sparsamer und
bewusster mit
Energie/Strom
umgeht. Im
Allgemeinen
betrifft dies
nicht nur
Primeo Energie
AG, sondern
jeden
Menschen.14
Jährige haben
ein Bewusstsein
für eine
nachhaltige
Energienutzung
entwickelt oder
erweitert.

Am Schluss
eine Frage auf
Touch Display
stellen, die mit
einer Skala von
1-5 bewertet
werden kann.
Ein Fragebogen
auf Papier
funktioniert
auch

Der
Durchschnitt
des
Fragenbogens
soll bei 3.5 von
5 Sternen sein.

Z02 | Unterhaltung | Wer das Produkt nutzt, soll während des Spielens unterhalten werden und Spass daran haben, das gestellte Problem spielerisch zu lösen. So haben die Besucher:innen der Ausstellung der Primeo Energie AG in Münchenstein eine positive Tätigkeit erlebt
- der Besuch
| | der Ausstellung wird somit emotional positiv gewertet.Habe ich Spass? Qualität Vergleich mit Alternativen. Subjektive Wahrnehmung des Spasses/Unterh altung

Es wird ein
Counter
eingeführt, der
misst, wie viele
Levels gespielt
wurden.dann
dito wie oben

Die Spieler
spielen mehr
als 1 Level bei
unserem
Produkt.

Z03 | Max Flow Problem

Das
mathematische
Problem (Max
Flow Problem)
soll den
Spielern näher
gebracht
werden.
Benötigt ein Ort
im Stromnetz
mehr Energie,
muss ein
optimaler Weg
für die Energie
vom
Herstellungsort
bis zur Senke
berechnet
werden. Dabei
hilft das Max
Flow Problem.

Die Spieler
scannen den
QR-Code um
auf eine
Website mit
Informationen
über das Max
Flow Problem
zu gelangen

10% der Spieler
besuchen die
Website

# Stakeholder

Table 3. Stakeholders des Arc42 Document
Wer? | Interesse, Bezug
Softwarearchitektinnen und -architekten: | Erfahrungen über das Unterhalten und erstellen eines Arc42 Dokuments sammeln.
Entwicklerinnen und Entwickler: | Dokumentieren der Entwicklung eines Projekts
Kunde: | Unterstützung der Kreation eines spannenden Max-flow-basierten Spiel

Table 4. Stakeholders Projekt
Stakeholder | Ansprechspersonen | Charakterisierung und Hintergrund | Bedürfnisse
Art des Stakeholders | Name, e-Mail… | Eigenschaften, Fähigkeiten, Geräte, Wissen, Erfahrungen, etc., die in die Nutzung des Produkts gebracht werden. Evtl. Verweise auf Dokumente/URL. | Mögliche Ziele, Anforderungen, Einschränkungen, die das Produkt attraktiv machen.

Stakeholder | Ansprechspersonen | Charakterisierung und Hintergrund | Bedürfnisse
Kunde | Andreas Vogt, andreas.vogt@fhnw.ch | Vertritt Primeo Energie AG, war in den letzten 3 Jahren bereits Kunde bei der FHNW und hat Board Games und Arcade Games in Auftrag gegeben. | Spielerischer Faktor des Spiels muss gewährleistet sein, erneuerbare Energien müssen eine Rolle spielen. Muss das Max Flow Problem beinhalten
Auftraggeber (FHNW) | Barbara Scheuner, barbara.scheuner@fhn w.ch | nimmt jährlich Aufträge an, welche realisierbar für das Projekt IP12 sind. Eine Jury wird das Produkt am Ende bewerten. | Erfüllung von Deadlines und Abgabeterminen.
Qualitätsmanager | Joshua Brehm, joshua.brehm@student s.fhnw.ch | Verantwortlich für die Entwicklung und Einhaltung der Qualitätsstandarts. Hat bereits in der IT-Branche gearbeitet. | klarer Informationsfluss, Mitarbeit von Teammitgliedern
Projektmanager | Shane Zulauf, shane.zulauf@students. fhnw.ch | Verantwortlich für das initiieren, Planen, Steuern, Kontrollieren und Abschliessen des Projekts. Hat bereits ein Projekt geleitet. | Mitarbeit von Teammitgliedern, Einhaltung von Terminen

Features

Table 5. Features
ID | Name | Wichtigkeit | Aufwand | Kurzbeschr eibung | Ziele | Implementi erung
F101 | RFID Daten auslesen | high | high | Das System sollte die vom User gelegten Bausteine auslesen können. | Spieler können ihren Spielzug auf dem Spielfeld realisieren | RFID reading in Java

ID | Name | Wichtigkeit | Aufwand | Kurzbeschr eibung
Ziele | Implementi
erung
F102 | Kontrollleuc hte neben den Gebäuden | high | low | Knotenpunkt e besitzen eine Kontrollleuc hte, damit der Spieler erkennen kann, ob seine Lösung erlaubt ist. Auch kann mit der Kontrollleuc hte der Startpunkt und Zwischen- /Endpunkt angezeigt werden.

System hat
die
möglichkeit
dem User
seinen
Fehler
darzustellen.

LED auf dem
Spielfeld
sind alle
einzeln
Ansteuerbar.
F103 | Levelauswah
l
high | high | Auf einem Touch Bildschirm werden Buttons für verschieden e Levels dargestellt. Mit drücken auf den Bildschirm auf einen Button wird ein Level ausgewählt. Das System weiss somit welches vordefiniert e Level dem User dargestellt werden soll.

System gibt
dem User die
Möglichkeit
das Spiel, an
seinen
gewollten
Schwierigkei
tsgrad
anzupassen.

Touch-Bildschirm

ID | Name | Wichtigkeit | Aufwand | Kurzbeschr eibung | Ziele | Implementi erung
F04 | Physische Spielanleitu ng | medium | low | Auf dem Holz des Board Games ist die Spielanleitu ng zum Spiel geschrieben. | Der Spieler muss nicht den Bildschirm bedienen um die Spielanleitu ng zu lesen und kann während des Spielens jederzeit die Spielanleitu ng lesen. | Laserdruck auf Holz, Klebstoff auf Holz
F05 | Touch
Screen
medium | high | Mithilfe eines Touch Screens kann die Levelauswah l betätigt werden, der Highscore kann angezeigt werden und bei einem Fehler des Spielers kann dies auch angezeigt werden.

Der Spieler
tippt auf den
Bildschirm,
um weitere
Level spielen
zu können

Verkabelung
mit RPi und
programmie
rung auf RPi,
dann
Einsetzung
in
Holzrahmen

# Randbedingungen

2.1 Technische Randbedingungen

Die Randbedingungen umfassen technische und organisatorische Randbedingungen des Projektes

Randbedingung | Erläuterung, Hintergrund
Hardwareausstattung | Das Projekt sollte auf einem 1,5 GHz 64-Bit ARM Cortex-A72 Quad-Core-Prozessors funktionieren. Dieser Computer bringt eigene Begrenzungen bezüglich Performance und den diversen Ausgabemöglichkeiten mit.
Betrieb auf einem Embedded System bzw mit Raspbian OS | Das Projekt muss auf Rasbian OS laufen.
Implementierung in Java 17 | Der Code soll grösstenteils in Java implementiert und geschrieben werden
Pi4j | Die Applikation soll mit der offiziellen Pi4J Library entwickelt werden.
Testing & JUnit5 | Das Testing-Framework ist zu übernehmen. Dokumentieren von funktionstüchtigen Tests im Gitlab Repository
Coding Conventions | https://www.oracle.com/technetwork/java/codeconventions-150003.pdf (https://www.oracle.com/technetwork/java/codeconventions-150003.pdf) - Kapitel 2, 5, 6, 7, 8, 9 und 10
Source Code & Version Control | Eigenes Gitlab-Project. https://gitlab.fhnw.ch/ip12-22vt/ip12-22vt_netzwerkkapazitaeten (https://gitlab.fhnw.ch/ip12-22vt/ip12-22vt_netzwerkkapazitaeten)
Architekturdokumentation | Arc42
Zeitplan | Genauer Nötig: Sommer 2023
Qualitätsanforderung | Das Projekt soll weiter, nicht funktionale Anforderungen beinhalten und umsetzen: TODO
SQLite DB | Vorgegebene Datenbank
Entwicklungsumgebung | Intellij IDEA - Professional Edition (Students)
Internet Verbindung | Wichtig zu beachten, Falls kein Internet vorhanden, müssen wichtige Dinge in den "Cache" gespeichert werden (Wetter API)
Dokumentation | Das ganze Projekt sollte gründlich dokumentiert werden. Dies beinhaltet Aspekte wie z.B: Spielablauf, Inbetriebnahme und die Wartung des Systems

### 2.2 Organisatorische Randbedingungen

Randbedingung | Erläuterung, Hintergrund
Team | Shane Zulauf (PM) Adrian Miller (IM) Erhan Bilgili (Test-Manager) Ron Gürber (RE) Tim Hoffmann (DEV) Maik Degen (SA) Joschua Brehm (QM)
Zeitplan | --- Genauer Nötig 12.09.22 - Start 28.11. - 03.12.22 - Projektwoche im Team 20.02.23 - Start FS23
Vorgehensmodell | Entwicklung risikogetrieben, iterativ und inkrementell. Zur Dokumentation der Architektur kommt arc42 zum Einsatz. Eine Architekturdokumentation gegliedert nach dieser Vorlage ist zentrales Projektergebnis.
Entwicklungswerkzeuge | Entwurf mit Stift und Papier, UML - Diagramme im Enterprise Architect. Arbeitsergebnisse zur Architekturdokumentation gesammelt auf dem Gitlab sowohl auch dem Confluence Wiki. Erstellung der Java-Quelltexte in IntelliJ.
Testing | JUnit-Testing für die Sicherstellung der Software. "Test-driven development".

### 2.3 Konventionen

Konventionen | Erläuterung, Hintergrund
Architekturdokumentation | Gliederung nach dem deutschen arc42-Template auf dem Gitlab.
Kodierrichtlinien für Java | Java Coding Conventions basierend auf Oracle
Sprache (Deutsch vs. Englisch) | Grundsätzlich wird die Benennung von Dingen (Schnittstellen und Komponenten) in Diagrammen auf Deutsch verfasst. Im Fachbereich der Grafentheorie bezüglich Max-flow-Problem werden, wenn möglich alle Englische begriffe auf Deutsch übersetzt und ausführlich erklärt. **

# Kontextabgrenzung

In der Kontextabgrenzung werden folgende Fragen beantwortet: Welche Nachbarsysteme existieren.+ Wie sehen diese Grenzen aus.

Allgemeine definierung des Scopes des Projekts.

# Fachlicher Kontext

Der fachliche Kontext definiert alle Kommunikationsbeziehung des Systems. (Ein- und Ausgabedaten)

Das Projekt "PROJEKTNAME" interagiert im jetzigen Stand nur mit einer externen Schnittstelle, der Wetter API. Sonst wird ausschliesslich mit dem menschlichen Benutzer interagiert.

[Context-Diagramm] | ./images/Outside_Template.bmp

# Nutzer:

Unser "Spiel" wird zwischen dem User und dem System gespielt. Das System übernimmt die Rolle des "Gegners". Jede Aktion von dem User wird vom System überprüft und bewertet. (Eingabe möglich? - Eingabe entspricht Maxflow?)

Wetter API (Fremdystem)
Integration der Wetter-API für die Kalkulation der Stromproduktion in späteren Levels

# Ein- und Ausgabearten des Systems

Table 1. Dokumentation Ein- und Ausgabewerte
Kommunikationsa rt | Eingabe | Ausgabe
Veränderung der Kapazitäten | RFID-Chip mit Datenhinterlegung im SQLite DB | Visuelle Bestätigung des Inputs (LEDS)
Auswahl eines neuen Levels | Touchscreen eingabe | Visuelle Darstellung Spielfeld ändert sich.
Maxflow Ergebnis | Konstante Überprüfung innerhalb des Systems. Touchscreen bestätigung | Visuelle Darstellung mithilfe LEDS

Table 2. Technische Schnittstellen

Schnittstelle | Beschreibung | Mapping
GPIOPins | Raspberry Pi 4 (rev. B) besitzt 26 ansteuerbare GPIOPins | LEDS, Schalter?, TODO
Stromversorgung | Raspberry Pi 4 (rev. B) besitzt ein USB-Netzteil mit 5 Volt und 3 Ampere mit USB-Typ-C (Steckverbindung) | -
USB | Raspberry Pi 4 (rev. B) hat 4 USB 3.0 Ports und 2 USB 2.0 Ports | TODO
Touchscreen | Raspberry Pi (4 rev. B) besitzt zwei Micro-HDMI Displayanschlüsse. | Darstellung von Levelauswahl und Eingabe

# Lösungsstrategie

# Erreichen der Qualitätsziele

Table 1. Erreichen der Qualitätsziele
Qualitätsziel | Entscheide zur Erfüllung
Funktionale Eignung | Gestaltung sollte interkativ sein
Funktional korrekt erstellt
Wartbarkeit | Verwendet Komponenten, welche bereits markt- erprobt sind.
| Aus diesem Grund auch einfach in der Beschaffung
Zuverlässigkeit | Testing mithilfe von Unitstests
| Zuverlässige Komponenten (RFID - TO-DO) / Weiteres Testing (mit mehreren RFID (interference) nötig)

# Bausteinsicht

Das System wird in einzelne Bausteine unterteilt. Die Bausteinsicht zeigt diese Bausteine auf und verdeutlicht diese Abhängigkeit.


# Whitebox Gesamtsystem

Die genauere Zerlegung des Gesamtsystems wird in diesem Abschnitt genauer untersucht.

TODO: Create Diagrams

[Hierarchie in der Bausteinsicht] | 05_building_blocks-DE.png

Ebene 1 ist die Whitebox-Beschreibung des Gesamtsystems, zusammen mit Blackbox-Beschreibungen der darin enthaltenen Bausteine.

Ebene 2 zoomt in einige Bausteine der Ebene 1 hinein. Sie enthält somit die Whitebox-Beschreibungen ausgewählter Bausteine der Ebene 1, jeweils zusammen mit Blackbox-Beschreibungen darin enthaltener Bausteine.

Ebene 3 zoomt in einige Bausteine der Ebene 2 hinein, usw.

Weiterführende Informationen

# Risiken und technische Schulden

ID | Risiken | Risiko "LEVEL"
I001 | RFID interference, Da wir vor haben, mehrere RFID Reader zu nutzen, besteht das Risiko von grosser interference. Die Praktische anwendung haben wir noch nicht untersucht (nur small scale testing). | High, lösbar mit viel Testing
I002 | Erste Erfahrung mit Implementation eines Maxflow problems, da implementierung und Verständniss kompliziert, hoher aufwand. | High, viel know-how noch nachzuholen
I003 | Verbindung technischer Komponenten (Verkabelung, Löten), Touchscreen, LED’s | High, da know-how noch zu erarbeiten ist.
I004 | Absturz aufgrund von Memory-Leaks. | medium, Problem sollte bis zur Live-demonstration, nach genug Testing "low" sein.
I004 | Bezüglich Qualitätsziele: Sinnvolle Generation des Schwierigkeitsgrads vom Maxflowproblem. Abschätzung der Stärke | medium
I005 | Implementierung der Wetter API, basierend auf Qualitätszielen: Sollte Offline verfügbar sein. (Caching der Daten) | low
I008 | - | -
I009 | - | -
I010 | - | -
I011 | - | -

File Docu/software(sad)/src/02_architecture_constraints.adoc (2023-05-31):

[[section-architecture-constraints]]
== Randbedingungen

[role="arc42help"]

2.1 Technische Randbedingungen

Die Randbedingungen umfassen technische und organisatorische Randbedingungen des Projektes

[options="header"]
|======================================================================================================================================================================================

|Randbedingung  | Erläuterung, Hintergrund

|Hardwareausstattung               |
Das Projekt sollte auf einem 1,5 GHz 64-Bit ARM Cortex-A72 Quad-Core-Prozessors funktionieren. Dieser Computer bringt eigene Begrenzungen bezüglich Performance und den diversen Ausgabemöglichkeiten mit.

| Betrieb auf einem Embedded System bzw mit Raspbian OS  |
Das Projekt muss auf Rasbian OS laufen.

| Implementierung in Java 11|
Der Code soll in Java implementiert und geschrieben werden
| Pi4j |
Die Applikation soll mit der offiziellen Pi4J Library entwickelt werden.
| Testing & JUnit5
|Das Testing-Framework ist zu übernehmen. Dokumentieren von funktionstüchtigen Tests im Gitlab Repository|
Coding Conventions
|https://www.oracle.com/technetwork/java/codeconventions-150003.pdf - Kapitel 2, 5, 6, 7, 8, 9 und 10
| Source Code & Version Control
| Eigenes Gitlab-Project. +
https://gitlab.fhnw.ch/ip12-22vt/ip12-22vt_netzwerkkapazitaeten
|Architekturdokumentation|Arc42
|Zeitplan|
12.09.2022-14.06.2023
|Qualitätsanforderung | Das Projekt soll weiter, nicht funktionale Anforderungen beinhalten und umsetzen: xref:04_solution_strategy.adoc[Qualitätsanforderungen]
|SQLite DB| Vorgegebene Datenbank
|Entwicklungsumgebung | Intellij IDEA - Professional Edition (Students)
| Internet Verbindung| Keine Internetverbindung nötig
| Dokumentation |
Das ganze Projekt ist gründlich dokumentiert. Dies beinhaltet Aspekte wie z.B: Spielablauf, Inbetriebnahme und die Wartung des Systems

|======================================================================================================================================================================================
////
.Inhalt
Randbedingungen und Vorgaben, die ihre Freiheiten bezüglich Entwurf, Implementierung oder Ihres Entwicklungsprozesses einschränken.
Diese Randbedingungen gelten manchmal organisations- oder firmenweit über die Grenzen einzelner Systeme hinweg.

.Motivation
Für eine tragfähige Architektur sollten Sie genau wissen, wo Ihre Freiheitsgrade bezüglich der Entwurfsentscheidungen liegen und wo Sie Randbedingungen beachten müssen.
Sie können Randbedingungen vielleicht noch verhandeln, zunächst sind sie aber da.

.Form
Einfache Tabellen der Randbedingungen mit Erläuterungen.
Bei Bedarf unterscheiden Sie technische, organisatorische und politische Randbedingungen oder übergreifende Konventionen (beispielsweise Programmier- oder Versionierungsrichtlinien, Dokumentations- oder Namenskonvention).

.Weiterführende Informationen

Siehe https://docs.arc42.org/section-2/[Randbedingungen] in der online-Dokumentation (auf Englisch!).
////

*2.2 Organisatorische Randbedingungen*

|======================================================================================================================================================================================
s|Randbedingung                 s| Erläuterung, Hintergrund
|  Team              |
Shane Zulauf +
Adrian Miller +
Erhan Bilgili +
Ron Gürber +
Tim Hoffmann +
Maik Degen +
Joshua Brehm

| Zeitplan |
12.09.22 - Start +
28.11. - 03.12.22 - Projektwoche im Team +
08.05. - 12.05.23 - Projektwoche im Team +
14.06.23 - Ende

| Vorgehensmodell |
Entwicklung risikogetrieben, iterativ und inkrementell. Zur Dokumentation der Architektur kommt arc42 zum Einsatz. Eine Architekturdokumentation gegliedert nach dieser Vorlage ist zentrales Projektergebnis.

|Entwicklungswerkzeuge |
Entwurf mit Stift und Papier, Diagramme, wenn möglich mit PlantUML. Arbeitsergebnisse zur Architekturdokumentation gesammelt auf dem Gitlab sowohl auch dem Confluence Wiki. Erstellung des Sourcecodes in IntelliJ.

|Testing|
JUnit-Testing für die Sicherstellung der Software. "Test-driven development".

|======================================================================================================================================================================================

*2.3 Konventionen*

|======================================================================================================================================================================================

s|Konventionen                 s| Erläuterung, Hintergrund
|  Architekturdokumentation
|
Gliederung nach dem deutschen arc42-Template auf dem Gitlab.

| Kodierrichtlinien für Java |
Java Coding Conventions basierend auf Oracle

| Sprache (Deutsch vs. Englisch) |
Grundsätzlich wird die Benennung von Dingen (Schnittstellen und Komponenten) in Diagrammen auf Deutsch verfasst. +
Im Fachbereich der Grafentheorie bezüglich Max-flow-Problem werden, wenn möglich alle Englische begriffe auf Deutsch übersetzt und ausführlich erklärt.

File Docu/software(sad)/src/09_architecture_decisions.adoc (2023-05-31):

[[section-design-decisions]]
== Architekturentscheidungen
:toc: right
:toclevels: 3

== Einführung

In diesem Dokument werden die wichtigsten Architekturentscheidungen für das Projekt "FLOW" erfasst.
Jede Entscheidung wird ausführlicher in einem eigenen Unterkapitel behandelt.

== Übersicht der Entscheidungen

[options="header"]

- Entscheidung von Technologie für Benutzerschnittstelle und Interaktion
* [line-through]#RFID-Reader#
* Touch Display
* Knopf

[role="architectural-decision"]
=== Technologie für Benutzerschnittstelle und Interaktion

==== Kontext

Als Hauptinteraktion in dem Produkt "FLOW" interagiert der Spieler mit den Edges des Graphen (mehr zum Spiel unter Kapitel 1):
Der Spieler kann den Flow, welcher durch die Edges fliesst, verändern, dies ist limitiert durch die maximale Kapazität der Edges. Das Verändern des Fluss durch ein Edge ist ein Hauptbestandteil des Spiels und gleichzeitig die, am häufigsten vorkommende Interaktion.

==== Entscheidung

Wir wollen sicherstellen, dass die gewählte Technologie für die Benutzerinteraktion möglichst einfach zu bedienen und intuitiv ist. Die Schnittstelle muss augenblicklich und unmerklich schnell abfolgen. Es muss sichergestellt werden, dass alle Personen unserer Zielgruppe, Jugendliche von 12-17 Jahren, das Produkt verwenden können. Die verwendete Technologie muss schon etabliert sein, um die technische Schuld möglichst realistisch zu behalten.

==== Status

Das Projekt verwendet den Touch Display mit je einem Knopf pro Edge. Somit kann der Benutzer eine Edge mit einem Knopf anwählen und anschliessend einen Wert über den Touch Display zuweisen.
Die ursprüngliche Version des Spiels beinhaltete nur RFID-Reader, welche, entlang der Edges verbaut geworden wären.
Begründet wurde dies mit der einfachen und intuitiven Anwendung für den Benutzer und der bereits zahlreich existierenden Implementationen der RFID Technologie. Zudem existieren für die vorgegebene Library Pi4j Beispielprojekte.
Die geplante Verwendung von RFID-Reader entlang der Edges des Graphen hatte eine Kaskade von technischen Komplikationen zur Folge:

.RFID Interference:
Mögliche Störung der Leseprozesse der RFID Reader, bei zu vielen und zu nah aneinanderliegenden Komponenten.

.Komplexitätszunahme der Hardware Architektur:
Das Verwalten und Ansprechen von über 20 RFID Readern erhöht die technischen Schulden schwerwiegend.
Um die technischen Schulden verkraften zu können, musste ein Grossteil der Interaktion auf Knöpfe verlegt werden. Diese sind ebenfalls einfach zu bedienen, brauchen aber deutlich weniger technischen Aufwand:

.Weniger Verkabelung:
Statt 4 Kabel per Reader nur 2 per Knopf.
Dies vereinfacht das Ersetzen der entsprechenden Komponente und die Verkabelung als Ganzes.

.Weniger komplexe Kommunikation:
Es gibt nur eine Interaktion, nämlich das Betätigen des Knöpfe. Leseoperationen folgen immer durch den gleichen RFID-Reader.

.Einfachere Fehlerbehebung:
Im Falle eines Defekts ist es einfacher, einen einzelnen Knopf auszutauschen, als einen RFID-Reader zu ersetzen. Zudem sind die Kosten für Ersatzteile bei Knöpfe geringer.

.Skalierbarkeit:
Die Verwendung von Knöpfe ermöglicht es, das Projekt einfacher zu erweitern, da sie weniger Platz beanspruchen und kostengünstiger sind als RFID-Reader.

.Energieeffizienz:
Knöpfe verbrauchen weniger Energie als RFID-Reader, was zu einer übersichtlicheren Stromversorgung des Gesamtsystems führt und gleichzeitig die Umweltbelastung verringert.

.Intuitive Lösung für Benutzer, insbesondere Kinder:
Knöpfe sind eine vertraute und einfach zu verstehende Interaktionsmethode für Benutzer aller Altersgruppen, insbesondere für Kinder. Dies fördert die Akzeptanz bei der Zielgruppe.

[role="architectural-decision"]
=== RFID-Reader und Knöpfe

==== Kontext

Der Touch Display und Knöpfe sind entscheidende Elemente der Benutzerschnittstelle des Projekts "FLOW". Sie ermöglichen die Interaktion des Benutzers mit den Edges und die Anpassung des Flusses.

==== Entscheidung

Die Entscheidung wurde getroffen, keine RFID-Reader und stattdessen Knöpfe für jede Edge zu verwenden und dies mit einem Touch Display zu kombinieren.
Dies wurde als der beste Kompromiss zwischen Benutzerfreundlichkeit, technischer Komplexität und Kosten angesehen.

==== Status

Die Umsetzung dieser Entscheidung ist bereits im Gange. Die Verwendung eines zentralen RFID-Readers und Knöpfe für jede Edge wird voraussichtlich die technische Komplexität reduzieren und ermöglicht eine einfachere Skalierung des Projekts.

[role="architectural-decision"]
=== Verwendung von etablierten Technologien

==== Kontext

Um die technische Schuld des Projekts "FLOW" in Grenzen zu halten, ist es wichtig, etablierte Technologien zu verwenden. Dies ermöglicht eine leichtere Integration mit bestehenden Systemen und fördert die Akzeptanz bei der Zielgruppe.

==== Entscheidung

Die Entscheidung wurde getroffen, Technologien zu verwenden, die weit verbreitet sind, wie z. B. RFID-Technologie und Knöpfe. Das Requirement der Programmiersprache Java ist jedoch beibehalten, was für die Implementierung eine Rolle spielt.

==== Status

Die Verwendung etablierter Technologien ist derzeit im Projekt in Arbeit. Obwohl die gewählten Technologien weit verbreitet sind, besteht die Herausforderung darin, dass wenig Code in Java verfügbar ist. Dies hat dazu geführt, dass das Team bei der jetzigen Umsetzung der Library und
der I2C-Schnittstelle auf einige Probleme gestossen ist. Trotz dieser Herausforderungen ermöglicht die Nutzung etablierter Technologien eine Verringerung der technischen Schuld und die Verbesserung der Akzeptanz bei der Zielgruppe, sobald die Umsetzung abgeschlossen ist.

[role="arc42help"]
////
****
.Inhalt
Wichtige, teure, große oder riskante Architektur- oder Entwurfsentscheidungen inklusive der jeweiligen Begründungen.
Mit "Entscheidungen" meinen wir hier die Auswahl einer von mehreren Alternativen unter vorgegebenen Kriterien.

Wägen Sie ab, inwiefern Sie Entscheidungen hier zentral beschreiben, oder wo eine lokale Beschreibung (z.B. in der Whitebox-Sicht von Bausteinen) sinnvoller ist.
Vermeiden Sie Redundanz.
Verweisen Sie evtl. auf Abschnitt 4, wo schon grundlegende strategische Entscheidungen beschrieben wurden.

.Motivation
Stakeholder des Systems sollten wichtige Entscheidungen verstehen und nachvollziehen können.

.Form
Verschiedene Möglichkeiten:

* ADR (https://cognitect.com/blog/2011/11/15/documenting-architecture-decisions[Documenting Architecture Decisions]) für jede wichtige Entscheidung
* Liste oder Tabelle, nach Wichtigkeit und Tragweite der Entscheidungen geordnet
* ausführlicher in Form einzelner Unterkapitel je Entscheidung

.Weiterführende Informationen

Siehe https://docs.arc42.org/section-9/[Architekturentscheidungen] in der arc42 Dokumentation (auf Englisch!).
Dort finden Sie Links und Beispiele zum Thema ADR.

****
////

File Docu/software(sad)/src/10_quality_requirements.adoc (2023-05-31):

[[section-quality-scenarios]]
== Qualitätsanforderungen

[role="arc42help"]
////
****
.Inhalt
Dieser Abschnitt enthält möglichst alle Qualitätsanforderungen als Qualitätsbaum mit Szenarien.
Die wichtigsten davon haben Sie bereits in Abschnitt 1.2 (Qualitätsziele) hervorgehoben.

Nehmen Sie hier auch Qualitätsanforderungen geringerer Priorität auf, deren Nichteinhaltung oder -erreichung geringe Risiken birgt.

.Motivation
Weil Qualitätsanforderungen die Architekturentscheidungen oft maßgeblich beeinflussen, sollten Sie die für Ihre Stakeholder relevanten Qualitätsanforderungen kennen, möglichst konkret und operationalisiert.
****

.Weiterführende Informationen

Siehe https://docs.arc42.org/section-10/[Qualitätsanforderungen] in der online-Dokumentation (auf Englisch!).
////
=== Qualitätsbaum

//link to drawio file in order to edit Qualitätsbaum diagram: https://drive.google.com/file/d/1wzS0GLwfnXFBJj2lL3eeOxayUR5lHsQ1/view?usp=share_link

////
[role="arc42help"]
****
.Inhalt
Der Qualitätsbaum (à la ATAM) mit Qualitätsszenarien an den Blättern.

.Motivation
Die mit Prioritäten versehene Baumstruktur gibt Überblick über die -- oftmals zahlreichen -- Qualitätsanforderungen.

.Form
* Baumartige Verfeinerung des Begriffes „Qualität“, mit „Qualität“ oder „Nützlichkeit“ als Wurzel.
* Mindmap mit Qualitätsoberbegriffen als Hauptzweige

In jedem Fall sollten Sie hier Verweise auf die Qualitätsszenarien des folgenden Abschnittes aufnehmen.
****
////
=== Qualitätsszenarien

==== Nutzungsszenarien
[%header,format=csv]
|===
Name,Beschreibung
Spielstart,"Ein Spieler startet das Spiel, verteilt den "Strom" auf die Verbindungslinien anhand der Buttons und überprüft die Kontrollleuchten, um sicherzustellen, dass die Regeln eingehalten werden."
Levelauswahl,"Ein erfahrener Spieler wählt ein höheres Level, um eine grössere Herausforderung zu erleben."
Fehlerkorrektur,"Ein Spieler bemerkt, dass eine Kontrollleuchte rot blinkt, korrigiert die Stromverteilung und überprüft, ob die Leuchte aufhört rot zu blinken."
Highscore-Überprüfung,"Nach Abschluss des Spiels überprüft der Spieler den Highscore und versucht, ihn im nächsten Spiel zu überbieten."
|===

==== Änderungsszenarien
[%header,format=csv]
|===
Name,Beschreibung
Neues Level,"Die Spielentwickler fügen ein neues Level mit zusätzlichen Häusern und Verbindungslinien hinzu."
Regeländerung,"Die Spielregeln ändern sich, z.B. werden neue Arten von "Strom" hinzugefügt, oder die Kapazitäten der Verbindungslinien werden angepasst."
Designänderung,"Das Design des Spiels ändert sich, z.B. werden neue Farben für die Kontrollleuchten eingeführt oder die physischen Komponenten des Spiels werden modifiziert."
Highscore-Systemänderung,"Das Highscore-System wird geändert, z.B. werden Bonuspunkte für das Erreichen bestimmter Ziele eingeführt."
|===
////
[role="arc42help"]
****
.Inhalt
Konkretisierung der (in der Praxis oftmals vagen oder impliziten) Qualitätsanforderungen durch (Qualitäts-)Szenarien.

Diese Szenarien beschreiben, was beim Eintreffen eines Stimulus auf ein System in bestimmten Situationen geschieht.

Wesentlich sind zwei Arten von Szenarien:

* Nutzungsszenarien (auch bekannt als Anwendungs- oder Anwendungsfallszenarien) beschreiben, wie das System zur Laufzeit auf einen bestimmten Auslöser reagieren soll.
Hierunter fallen auch Szenarien zur Beschreibung von Effizienz oder Performance.
Beispiel: Das System beantwortet eine Benutzeranfrage innerhalb einer Sekunde.
* Änderungsszenarien beschreiben eine Modifikation des Systems oder seiner unmittelbaren Umgebung.
Beispiel: Eine zusätzliche Funktionalität wird implementiert oder die Anforderung an ein Qualitätsmerkmal ändert sich.

.Motivation
Szenarien operationalisieren Qualitätsanforderungen und machen deren Erfüllung mess- oder entscheidbar.

Insbesondere wenn Sie die Qualität Ihrer Architektur mit Methoden wie ATAM überprüfen wollen, bedürfen die in Abschnitt 1.2 genannten Qualitätsziele einer weiteren Präzisierung bis auf die Ebene von diskutierbaren und nachprüfbaren Szenarien.

.Form
Entweder tabellarisch oder als Freitext.
****
////

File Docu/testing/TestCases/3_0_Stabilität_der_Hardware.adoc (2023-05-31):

TC 3.0 Stabilität der 3D-Komponenten

*Beschreibung:* Bei diesem Test soll geprüft werden, ob es möglich ist, physische Komponenten des Spielbretts ohne böswillige Absichten zu entfernen/abreissen.

*Annahmen und Voraussetzungen:* Mit Araldit festgeklebte Komponenten lösen sich unter keinen Umständen, anders festgeklebte Komponenten können böswillig abgerissen werden.

*Testdaten:* 10/11/12.05.2023

*Auszuführende Schritte:* +
Durch horizontales versuchtes Hin- und Herbewegen eines Komponenten mit einer ungefähren Stärke von 100 Newton wird die Stabilität geprüft.

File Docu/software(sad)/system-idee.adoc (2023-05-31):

= Systemidee
Als Grundlage Ihrer Entwurfstätigkeiten sollten Sie eine Vorstellung wichtiger Systemeigenschaften und Anforderungen besitzen und mindestens folgende Fragen über das System beantwortet haben.

Umfang dieses Dokuments 1-3 A4 Seiten.

== Kernaufgabe des Systems
****
//Beschreiben Sie die Kernaufgabe und Verantwortlichkeit des Systems in zwei bis drei Sätzen. Formulieren Sie positiv und benutzen Sie die Kernbegriffe der Fachdomäne.
//Fügen Sie die wichtigsten Begriffe oder Aspekte der Fachdomäne hinzu; wenige Begriffe (fünf bis zehn) genügen häufig.
//Stimmen Sie diese Formulierung mit Kunden und Auftraggebern ab!

Die Kernaufgabe von unserem System ist ein Spiel.
Es gibt dem Nutzer einen Einblick in das Problem, im Teilbereich der Graphentheorie mit dem Namen [.underline]#Maximum flow problem.# 

Dies wird voraussichtlich auf einer Spielfläche geschehen.
Mit 3D-Gedruckten Knotenpunkten (z.B Wind- und Wasserkraftwerke, Solarzellen sowie verschiedene noch zu definierende Senken) und deren jeweiligen Kabelverbindungen.

 - Dieses System sollte einen kleinen Einblick in die Komplexität der Netzstruktur zeigen.

- Anbei eine kleine Darstellung dieses Problems.

Maximum Flow Problem

- Erklärungen der wichtigsten Begriffe der Fachdomäne:

* Source: +
+
Eine Quelle in einem gerichteten Graphen ist ein Scheitelpunkt ohne eingehende Kanten (in Grad gleich 0).

* Sink: +
+
Eine Senke in einem gerichteten Graphen ist ein Scheitelpunkt ohne ausgehende Kanten (Ausgangsgrad gleich 0).

* Kapazität:
+
Die Kapazität einer Kante ist die maximale Durchflussmenge, die eine Kante passieren kann. Formal ist es eine Karte
[STEM]
latexmath:[c :E\to\mathbb {R}^{+}]
+
Weitere Informationen zu Begriffen im Max Flow Problem:
https://en.wikipedia.org/wiki/Maximum_flow_problem

//Eine solche kurze Formulierung erleichtert die Kommunikation über das System. Sie definiert für alle Beteiligten das wichtigste Ziel (= das System). Gleichzeitig schafft sie einen begrifflichen Kontext, an dem sich alle Beteiligten orientieren können.

****

== Kategorie von System
****
Das System beinhaltet Teile aus:

- Teile eines eingebetteten System (weil wir mit einem Raspberry Pi arbeiten).
- Teile eines Systems mit Echtzeitanforderungen, da wir konstante Anforderungen an die Nutzer, mit Hilfe eines kleinen Bildschirms, stellen.
// Interaktive Online-Systeme: Auch als operationale Systeme bezeichnet, arbeiten diese Systeme als Teil der normalen Geschäftsprozesse in Unternehmen. In den meisten Fällen enthalten sie Operationen auf Daten (Transaktionen Änderungs-und Lösch-Operationen), die vom Ablauf her in die Benutzeroberfläche eingebettet sind. Die Art der Transaktionen ist festgelegt. Die Systeme operieren auf möglichst aktuellen Datenbeständen. Sie erfordern ein hohes Maß an Systemverfügbarkeit und Performance.

//- Mobile Systeme: Eine (moderne) Variante von Online-Systeme - durch die starke Verbreitung von Smartphones und Tablet-Computern sehr wichtig geworden. Starker Fokus auf Benutzeroberfläche und Benutzbarkeit, oftmals per Internet an Backend-Systeme angebunden.

//- Entscheidungsunterstützungssysteme (decision support system): arbeiten oftmals auf Kopien der aktuellen Unternehmensdaten (data warehouse) und enthalten hauptsächlich lesende Datenzugriffe. Die Art der Anfragen an die Daten ist flexibel. Benutzer können neue Anfragen (queries) formulieren. Daher ist die Laufzeit von Anfragen im Vorfeld kaum abschätzbar. Solche Systeme tolerieren höhere Ausfallzeiten und geringere Performance.
//- Hintergrundsysteme (Offline-Systeme, Batch-Systeme): dienen hauptsächlich der Datenmanipulation, oftmals zur Vor- oder Nachverarbeitung vorhandener Datenbestände; werden zur Interaktion mit anderen Systemen eingesetzt.

//- Eingebettete Systeme (embedded systems): arbeiten eng verzahnt mit spezieller Hardware. Ein Beispiel für eingebettete Systeme sind Mobiltelefone (viele haben auch Echtzeitanforderungen).

//- Systeme mit Echtzeitanforderungen (real-time systems): Operationen werden innerhalb garantierter Zeiten fertiggestellt. Beispiel: Produktionssteuerung (Fließbänder mit festen Taktzeiten), Herzschrittmacher.
****

== Wesentliche Qualitätsanforderungen
****
//Die Qualität von Softwaresystemen wird immer bezogen auf einzelne Eigenschaften oder Merkmale. Beispiele für solche Merkmale sind Effizienz (Performance), Verfügbarkeit, Änderbarkeit, Verständlichkeit und Zuverlässigkeit.
Die vorrangigen Qualitätsanforderungen an unser System sind die *Benutzbarkeit*, *Zuverlässigkeit* aber natürlich auch die *Robustheit*

Spezifische Qualitätsanforderungen:

- Benutzbarkeit: +
*  Der Aufwand der Nutzung für die User sollte minimal sein.

- Zuverlässigkeit: +
* Unser System soll die zugewiesene Funktion in einem, von uns noch zu definierenden Zeitfenster erledigen.

- Robustheit
* Da mit greifbaren Teilen, Knöpfen und Spielfiguren gespielt werden kann,  sollen diese Robust und gleichzeitig "wartbar" sein.
//Es gibt eine ganze Reihe unterschiedlicher Definitionen von Qualitätsmodellen und Qualitätsmerkmalen. Alle definieren einige zentrale Qualitätseigenschaften (beispielsweise Zuverlässigkeit, Effizienz, Wartbarkeit, Portabilität etc.) und verfeinern diese Eigenschaften durch eine Hierarchie weiterer Merkmale.

//Egal, welches dieser Modelle Sie verwenden: Achten Sie innerhalb Ihrer Systeme oder Projekte auf eine einheitliche Terminologie für Qualitätsanforderungen. Der folgende Link zeigt Ihnen die Qualitätsmerkmale gemäss https://de.wikipedia.org/wiki/ISO/IEC_9126[DIN/ISO 9126]. Diese Norm enthält die wesentlichen Begriffe rund um Softwarequalität.

//Weil unsere Systeme auch Hardware enthalten, beziehen wir die oben beschriebenen Qualitäten auf das Gesamtsystem.
****

== Relevante Stakeholder
****
//Welche Rollen oder Personen (= Stakeholder) innerhalb oder ausserhalb der Organisation haben ein Interesse am System? Beispiele sind Benutzer der Kernfunktionalität („Anwender“), Administratoren und Betreiber, Benutzer mit Sonderfunktionen.

- Stakeholder Ausserhalb: +
Der Kunde (Primeo Energie) erwartet ein Lernspiel, was den Kindern und Teenagern die Funktionalität der Energie im  Stromnetz mithilfe des Maximum flow problem spielerisch beibringt.

- Stakeholder innerhalb:
* Die FHNW, welche interessante Projekte für die Sponsoringpartnern zur Verfügung stellen möchte.
+
* Qualitätsmanager: +
Verantwortlich für die Entwicklung und Einhaltung  der Qualitätsstandards.

* Projektmanager: +
Verantwortlich für das initiieren, Planen, Steuern, Kontrollieren und Abschliessen des Projekts.
****

== Schnittstellen zu externen Systemen
****
//Sie sollten immer eine präzise Vorstellung der (fachlichen wie technischen) Umgebung eines Systems besitzen (= Kontext), d. h. welche Nachbarsysteme mit dem System interagieren.
Schnittstellen sollten zu folgenden Nebensystemen existieren:

- RFID decoder, API, TBD.
- Wetter API der Schweiz, welche uns die aktuelle Wettersituation an den gewünschten Standorten übermittelt. Dies würden wir zur Bestimmung der Energieproduktion verschiedener Solarzellen verwenden. (überlegung über offline nutzung nötig)

//Führen Sie hier eine Liste dieser Systeme auf.

****
== Datenhaltung:
****

Welche Daten müssen gespeichert werden: +

- Mögliche Speicherung des currentScore um Vergleiche mit maxScore last hour/ overall zu darstellen.

- Informationen, welche die RFID referenziert. Das Mapping von RFID zu den verschiedenen Capacities

-
****

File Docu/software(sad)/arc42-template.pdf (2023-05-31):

# Template

### Über arc42

arc42, | das | Template | zur | Dokumentation | von | Software- | und
Systemarchitekturen.

Template Version 8.1 DE. (basiert auf AsciiDoc Version), Mai 2022

Created, maintained and © by Dr. Peter Hruschka, Dr. Gernot Starke and contributors. Siehe https://arc42.org.

HINWEIS

Diese Version des Templates enthält Hilfen und Erläuterungen. Sie dient der Einarbeitung in arc42 sowie dem Verständnis der Konzepte. Für die Dokumentation eigener System verwenden Sie besser die plain Version.

# Inhaltsverzeichnis

# 1. Einführung und Ziele

In diesem Kapitel wird auf die Aufgabenstellung, die funktionalen Anforderung, dies das Produkt beschriebt sowie auch die Qualitätsziele eingegangen. Ausserdem werden die Stakeholder und ihre Erwartungshaltung definiert. Dies soll einen Überblick über die Rahmenbedingungen des Systems bieten.

# 1.1. Aufgabenstellung

In der Aufgabenstellung wird dies näher angeschaut und das Produkt erläutert.

# 2. Was ist "Produktname"?

Wie genau das Stromnetz aufgebaut wissen wenige, mit der steigenden "Awareness" bezüglichem der effizienten Stromnutzung und auch der optimalen Verteilung des Stroms innerhalb des Netzes an die jeweiligen Endnutzer. bzw. zur Abstraktion in unserem Fall Häuser.

Unser Produkt, mit dem Namen "Produktname" soll diese optimale Verteilung, basierend auf dem "Max-flow-Algorithmus" anschaulich dargestellt werden.

- Thematisiert die Komplexität der Verteilung von Strom im Stromnetz
- Interaktiver Umgang mit den einzelnen "Edges" und den "Kapazitäten"
- Die optimale Verteilung wird als anstrebendes Ergebniss dem Nutzer übergeben. Der Spieler versucht also durch überlegen, selber auf die beste Verteilungs-möglichkeit zu kommen.

# 3. Wesentliche Features

Die wesentlichen Features sind:

- Strategisches Spiel, bzw. "Quiz".
- Wiederspielbarkeit bzw. "replayability", da Anpassung auf den eigenen Wissenstand möglich, da Levelauswahl vorhanden.
- Wissensübertrag, Verständniss bezüglich Stromnetz wird erhört.

# 3.1. Qualitätsziele

Die Qualitätsziele umfassen die wichtigsten Qualitätsanforderung an das Spiel mit dem Namen "Produktname". Sie sind nach Priorität in der folgenden Tabelle geordnet.

Tabelle 1. Qualitätsziele
Qualitätsziel | Motivation und Beschreibung
Benutzbarkeit: | Der Aufwand der Nutzung für die User sollte minimal sein.

Zuverlässigkeit: | Unser System soll die zugewiesene Funktion in einem, von uns noch zu definierenden Zeitfenster erledigen.
Robustheit: | Da mit greifbaren Teilen, Knöpfen und Spielfiguren gespielt werden kann, sollen diese Robust und gleichzeitig "wartbar" sein.
Effizienz: | Da unser Spiel live demonstriert wird, ist es wichtig, dass die Berechnungen schnell erledigt werden..

Auszug aus den Produktzielen unserer Confluence Seite (https://www.cs.technik.fhnw.ch/confluence20/display/VT122208/Produktvision)

Tabelle 2. Produktziele
ID | Name | Beschreibung | Messung | Soll-Wert
| Kurzer Name des Ziels | Beschreibung des Zieles im Detail, inkl. in welcher Situation bzw. durch wen das Ziel erreicht werden soll. | Wie in einer Demo/Nutzerte st die Zielerreichung überprüft werden soll | Schwellwert, um auszusagen "Ziel ist erreicht."

Z01 | Bewusstsein & Energienutzung
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

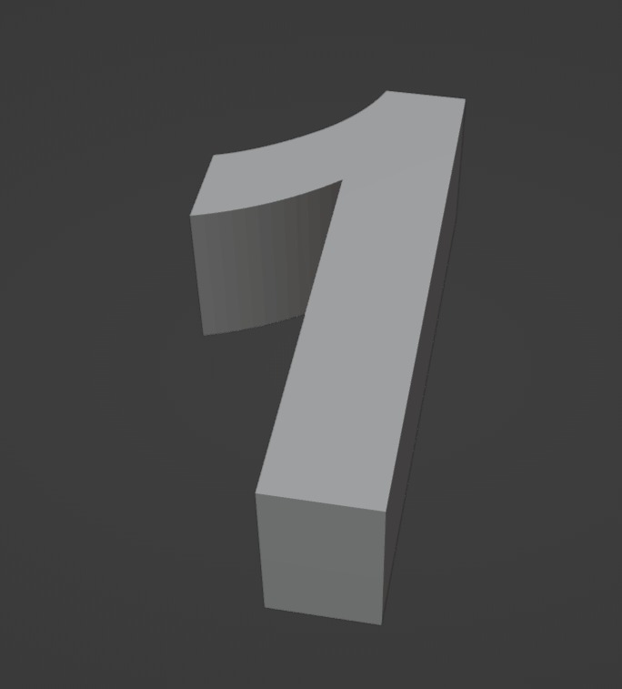
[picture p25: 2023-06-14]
Docu/hardware/images/IP12_Edge_Capacity_Number_1.jpg

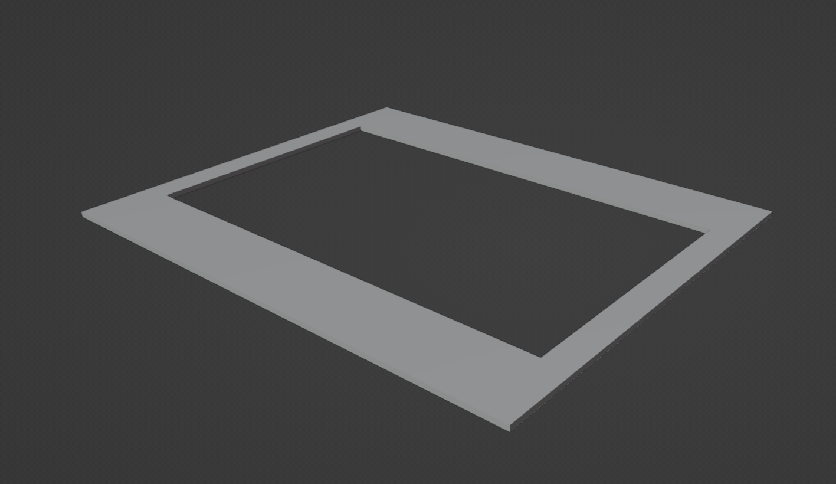
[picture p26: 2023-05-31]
Docu/hardware/images/LCD_Abdeckung_1.png

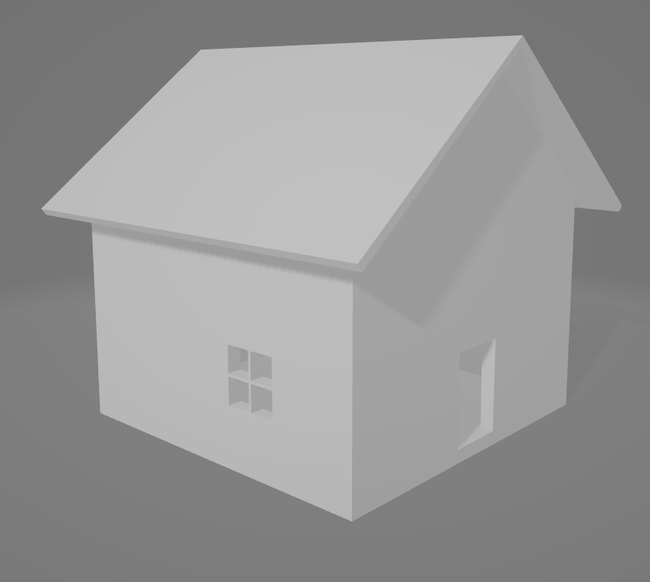
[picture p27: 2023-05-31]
Docu/hardware/images/flow_house3x3.png

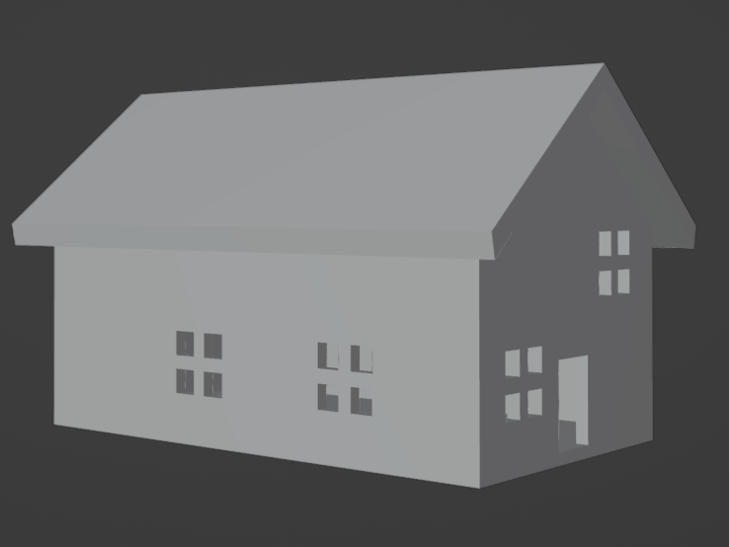
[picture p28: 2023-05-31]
Docu/hardware/images/fow_house3x5.png

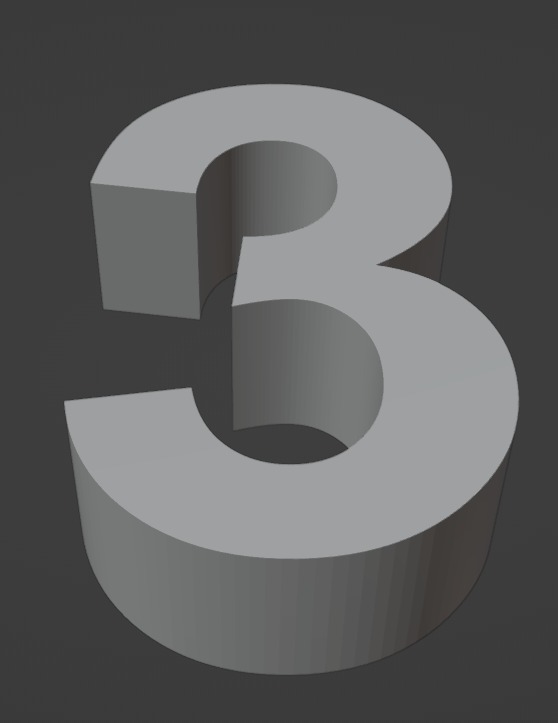
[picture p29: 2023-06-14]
Docu/hardware/images/IP12_Edge_Capacity_Number_3.jpg

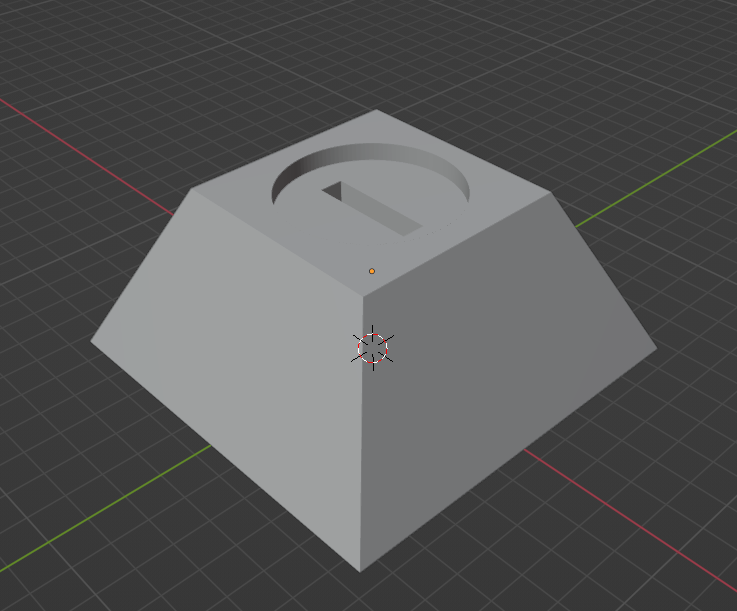
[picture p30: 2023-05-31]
Docu/hardware/images/LED_Cap.png

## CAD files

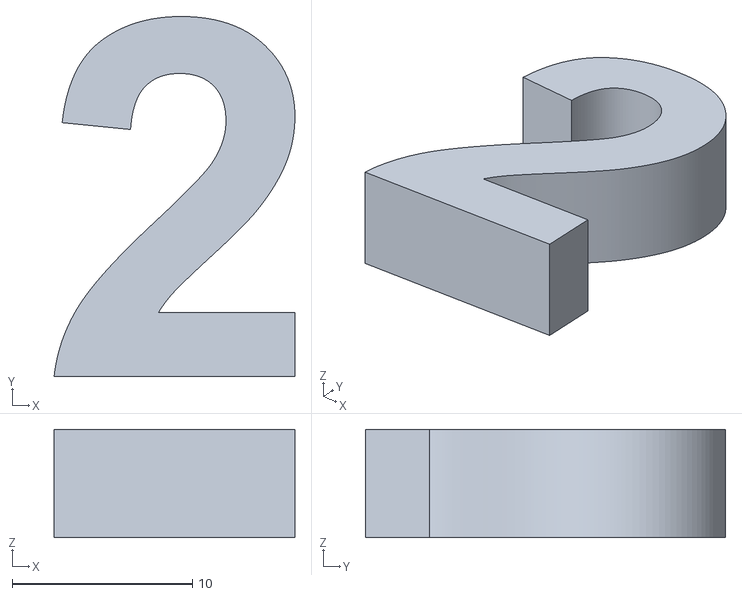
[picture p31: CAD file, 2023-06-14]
Docu/hardware/3D_files/IP12_Edge_Capacity_Number_2.stl
13.3 x 19.9 x 6.00

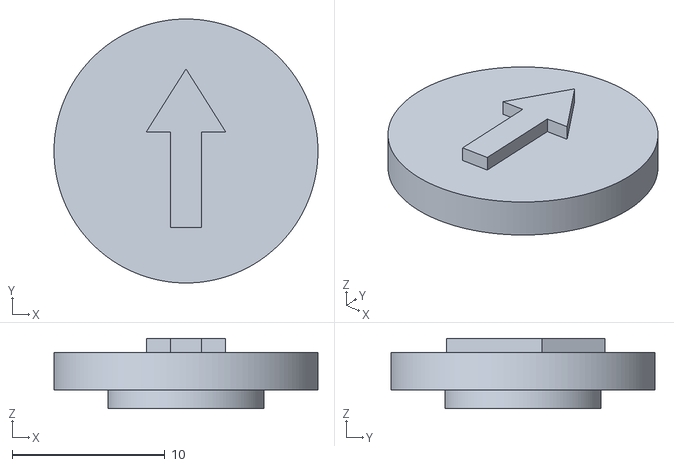
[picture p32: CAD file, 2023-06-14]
Docu/hardware/3D_files/Deckel_mit_Arrow.stl
17.3 x 17.3 x 4.60

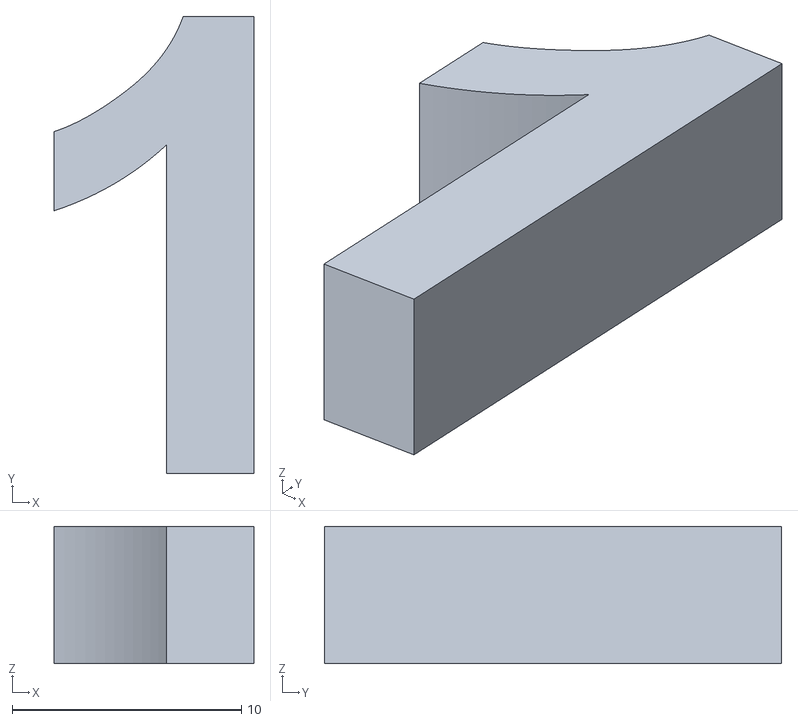
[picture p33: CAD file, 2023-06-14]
Docu/hardware/3D_files/IP12_Edge_Capacity_Number_1.stl
8.73 x 19.9 x 6.00

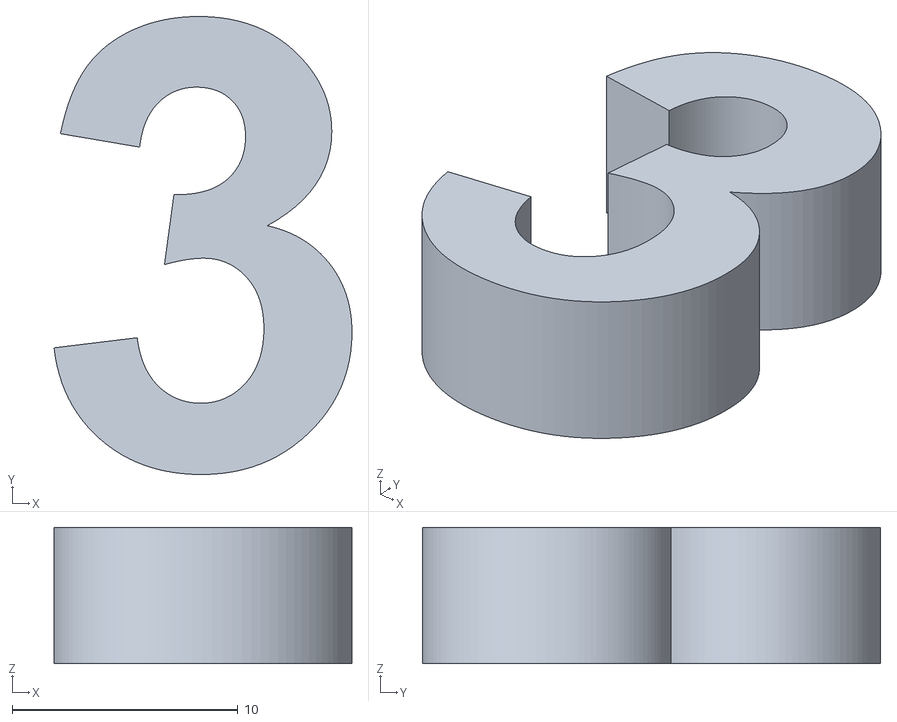
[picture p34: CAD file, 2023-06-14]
Docu/hardware/3D_files/IP12_Edge_Capacity_Number_3.stl
13.2 x 20.3 x 6.03

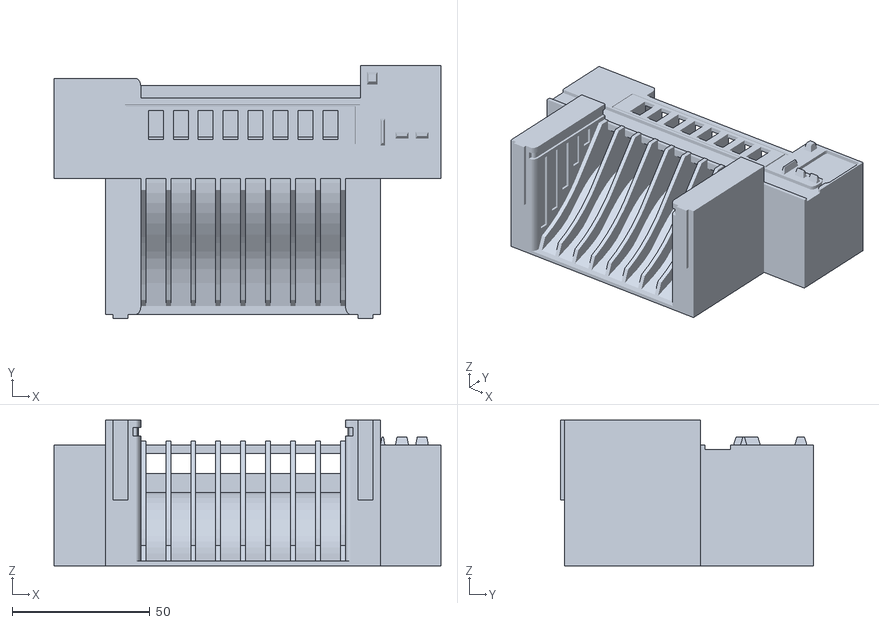
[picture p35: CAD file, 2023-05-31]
Docu/hardware/3D_files/Wasserkraftwerk14x9.stl
140.3 x 91.8 x 52.8

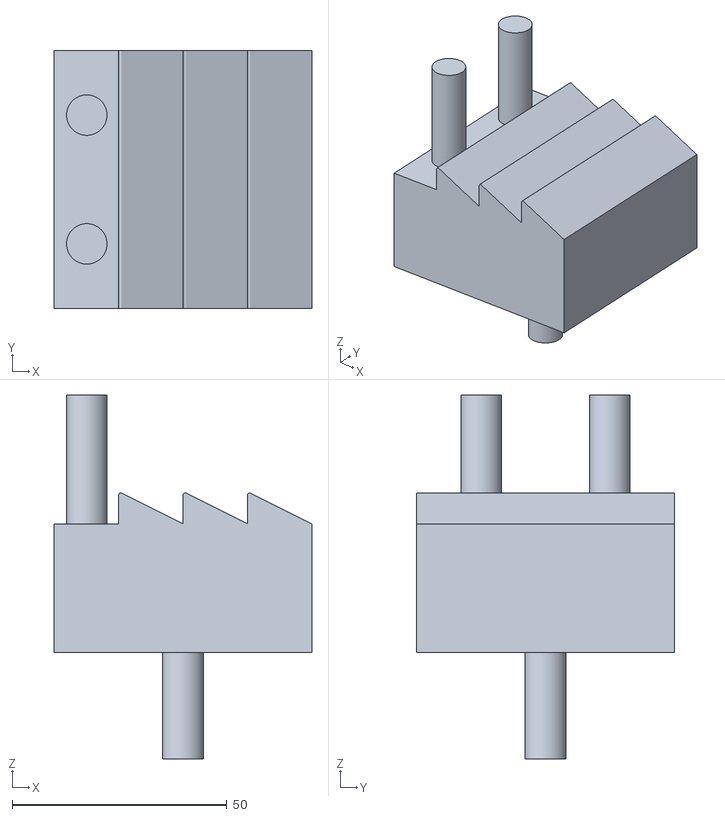
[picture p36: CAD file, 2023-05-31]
Docu/hardware/3D_files/ip12factory.stl
60.0 x 60.0 x 84.8

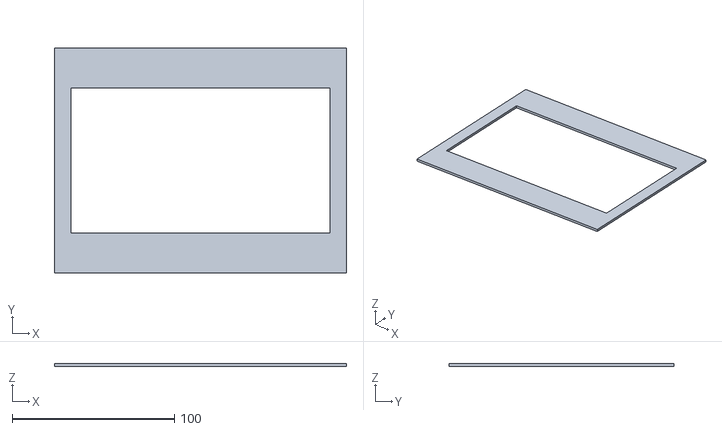
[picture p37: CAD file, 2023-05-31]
Docu/hardware/3D_files/LCD_Abdeckung_1.stl
180.0 x 139.0 x 1.92

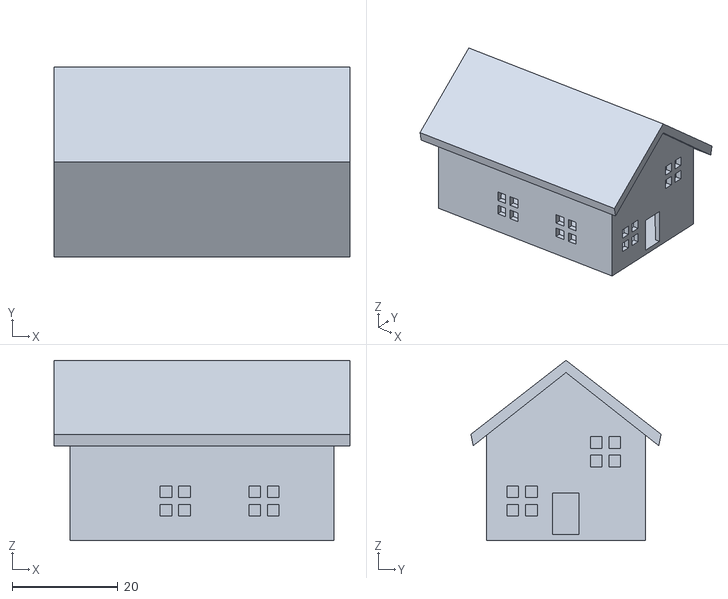
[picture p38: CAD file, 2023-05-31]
Docu/hardware/3D_files/flow_house3x5new.stl
56.0 x 36.0 x 34.1

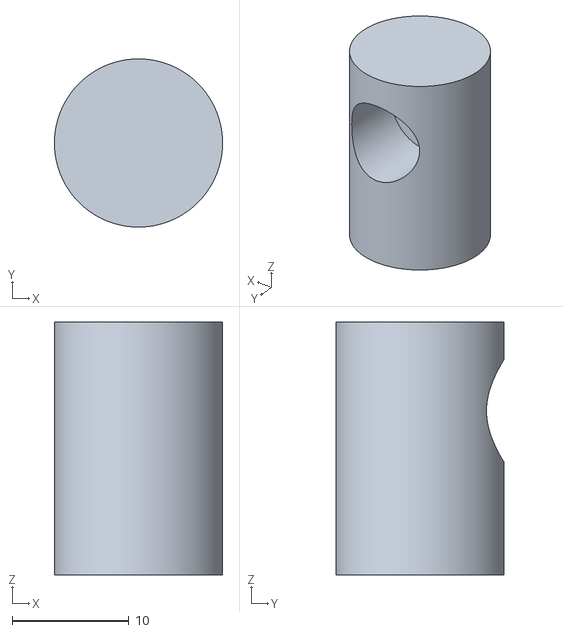
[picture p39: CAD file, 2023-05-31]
Docu/hardware/3D_files/AcrylstabHalter.stl
14.4 x 14.4 x 21.7

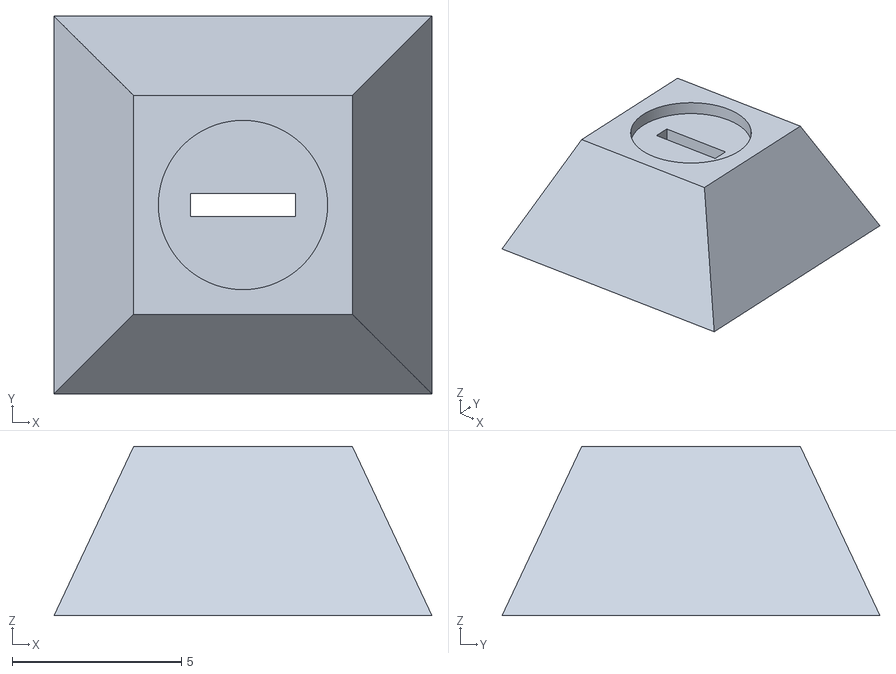
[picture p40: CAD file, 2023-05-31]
Docu/hardware/3D_files/LED_Cap.stl
11.2 x 11.2 x 5.00

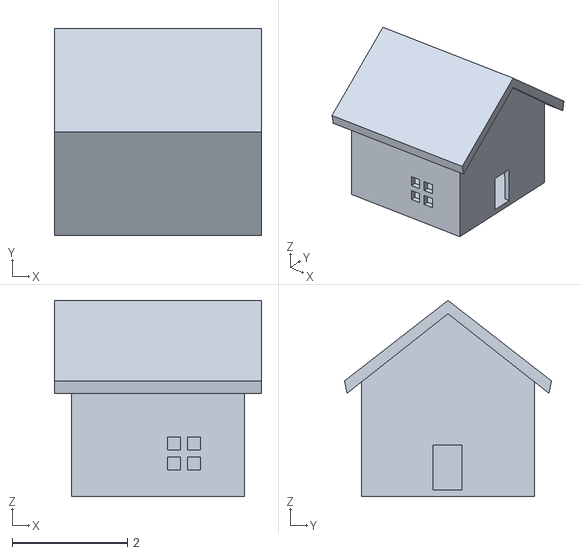
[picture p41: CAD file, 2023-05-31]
Docu/hardware/3D_files/flow_house3x3.stl
3.60 x 3.60 x 3.41

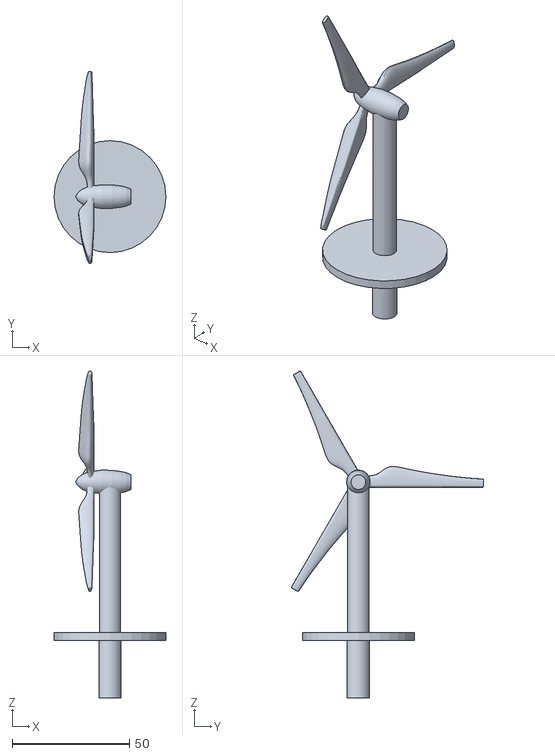
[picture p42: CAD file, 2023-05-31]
Docu/hardware/3D_files/WindkraftwerkTurbine.stl
47.7 x 81.9 x 139.3

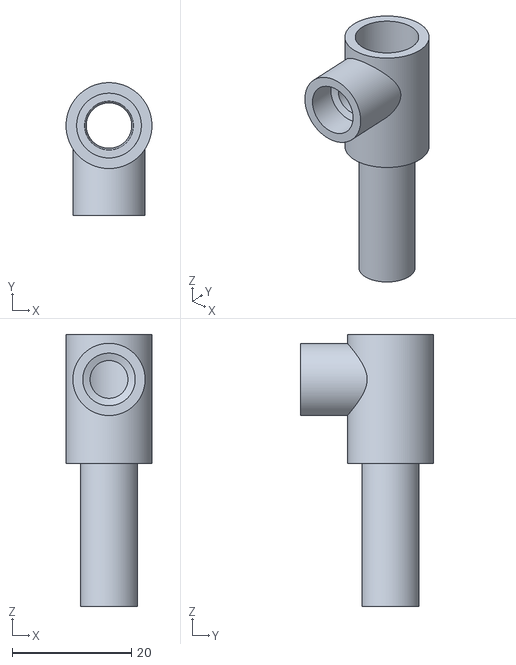
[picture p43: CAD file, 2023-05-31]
Docu/hardware/3D_files/HyperLoopStationVar4_2.stl
14.4 x 22.3 x 45.6

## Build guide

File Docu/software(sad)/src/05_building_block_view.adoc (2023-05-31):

[[section-building-block-view]]
== Bausteinsicht

Das System wird in einzelne Bausteine unterteilt. Die Bausteinsicht zeigt diese Bausteine auf und verdeutlicht diese Abhängigkeit.

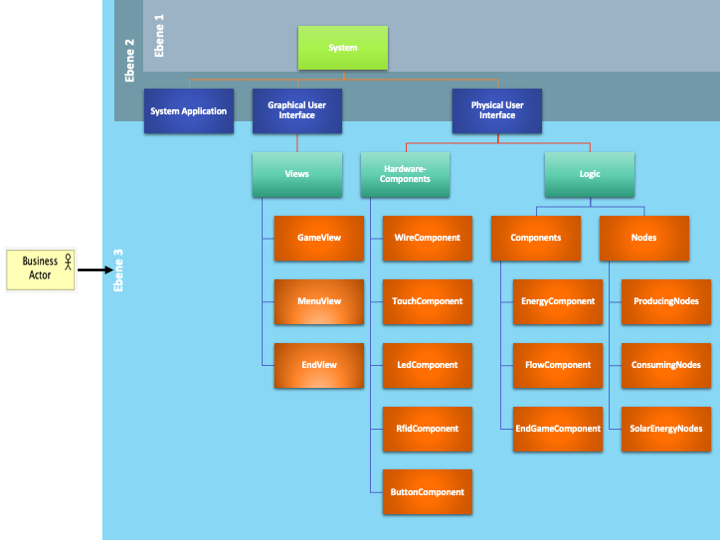
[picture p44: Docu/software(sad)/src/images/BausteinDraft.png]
Bausteinsicht
//  Change Removed, outdated: 

////
.Inhalt
Die Bausteinsicht zeigt die statische Zerlegung des Systems in Bausteine (Module, Komponenten, Subsysteme, Klassen, Schnittstellen, Pakete, Bibliotheken, Frameworks, Schichten, Partitionen, Tiers, Funktionen, Makros, Operationen, Datenstrukturen, ...) sowie deren Abhängigkeiten (Beziehungen, Assoziationen, ...)

Diese Sicht sollte in jeder Architekturdokumentation vorhanden sein.
In der Analogie zum Hausbau bildet die Bausteinsicht den _Grundrissplan_.

.Motivation
Behalten Sie den Überblick über den Quellcode, indem Sie die statische Struktur des Systems durch Abstraktion verständlich machen.

Damit ermöglichen Sie Kommunikation auf abstrakterer Ebene, ohne zu viele Implementierungsdetails offenlegen zu müssen.

.Form
Die Bausteinsicht ist eine hierarchische Sammlung von Blackboxen und Whiteboxen (siehe Abbildung unten) und deren Beschreibungen.
////

=== Whitebox Gesamtsystem

Whitebox Gesamtansicht
[Diagramm platzhalter: Ein Diagramm, das die vier Hauptblöcke und ihre Beziehungen zeigt]

Das Spiel beinhaltet 4 Grundkonzepte welche sachlich voneinander getrennt werden können.

. Benutzerinteraktion
. Logik und Ablauf des Spiels
. Initialisierung und Datenverwaltung der Spielinformationen
. Schnittstelle mit Informationsaustausch zu Hardwarekomponenten

Das System wurde dementsprechend in vier Hauptblöcke unterteilt:

. User Interface (UI)
. Game Logic
. Game Data Management
. Hardware Interface

==== User Interface (UI)

Dieser Baustein ist für die Interaktion mit dem Benutzer verantwortlich. Er verarbeitet Benutzereingaben, welche von dem Hardwareinterface geliefert werden: Eingabeinformation von Knöpfen und Touchscreen. Diese Informationen werden an die Geschäftslogik weitergegeben.

[Diagramm platzhalter: Ein Diagramm das in das entsprechene Element der Ebene 2 hineinzoomt]

==== Game Logic

Dieser Baustein implementiert die Hauptlogik des Spiels. Er erhält Eingaben vom Benutzer durch das UI und steuert die Verteilung von "Strom" in den Kanten des Graphen. Er kommuniziert mit dem Game Data Management, um den Zustand des Spiels zu ändern und abzufragen.

[Diagramm platzhalter: Ein Diagramm das in das entsprechene Element der Ebene 2 hineinzoomt]

==== Game Data Management

Dieser Baustein verwaltet den Zustand des Spiels. Er speichert Informationen über die Verteilung von "Strom" in den Kanten und die Zustände der Knoten. Er erhält Anweisungen von der Game Logic und stellt Informationen zur Verfügung, wenn sie benötigt werden.

==== Hardware Interface

Dieser Baustein ist für die Kommunikation mit der Hardware verantwortlich. Er empfängt Anweisungen von der Game Logic, um die LEDs zu steuern und die Zustände der Buttons abzufragen und entnimmt Signale der Komponenten, welche die Benutzerinteraktion ermöglichen.

[Diagramm platzhalter: Ein Diagramm das in das entsprechene Element der Ebene 2 hineinzoomt]

=== Blackbox Gesamtsystem

Hier folgen jetzt Erläuterungen zu Blackboxen der Ebene 1.

[cols="1,2" options="header"]
|===
| **Name** | **Verantwortung**
| _User Interface_ | _Verarbeitet Benutzereingaben und liefert Benutzerinteraktionen_
| _Game Logic_ | _Steuert den Spielablauf und die Spiellogik_
| _Game Data Management_ | _Speichert und verwaltet den Zustand des Spiels_
| _Hardware Interface_ | _Verantwortlich für die Kommunikation mit der Hardware_
|===

==== User Interface
Zweck/Verantwortung: Verarbeitung der Benutzereingaben und Lieferung von Benutzerinteraktionen.
Schnittstelle(n): Interaktion mit der Hardware und dem Benutzer, Kommunikation mit der Game Logic.

==== Game Logic
Zweck/Verantwortung: Steuerung der Spiellogik und des Spielablaufs.
Schnittstelle(n): Empfang von Benutzereingaben vom User Interface, Kommunikation mit dem Game Data Management und dem Hardware Interface.

==== Game Data Management
Zweck/Verantwortung: Speicherung und Verwaltung des Zustandes des Spiels.
Schnittstelle(n): Empfang von Anweisungen von der Game Logic und Bereitstellung von Informationen, wenn sie benötigt werden.

==== Hardware Interface
Zweck/Verantwortung: Verantwortlich für die Kommunikation mit der Hardware.
Schnittstelle(n): Empfang von Anweisungen von der Game Logic zur Steuerung der Hardware.

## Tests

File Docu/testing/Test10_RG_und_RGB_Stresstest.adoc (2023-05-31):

== Test 6

[%autowidth]
|===
|Datum | 10.05.2023
| Verantwortlich | Ron Gürber & Shane Zulauf
|===

include::TestCases/3_5_RG_und_RGB_Stresstest.adoc[]

*Status:* Erfolgreich

*Bemerkungen:*
Durchührungsort: Werkstatt 4.027 FHNW Campus Brugg-Windisch
|===
|LED Typ| Bemerkung
|Knoten LED (RG)|LED überhitz nicht und leuchtet in den erwarteten Farben. Laufzeit ca. 50'000 Stunden. Sind schwierig zu entfernen
|Edge LED (RGB)|LED überhitzt nicht und leuchtet in den erwarteten Farben. Sehr hell, gut für die Edges. Laufzeit ca. 50'000 Stunden. kann man nicht entfernen, da sie von den Edge Halterungen umhüllt sind.
|===

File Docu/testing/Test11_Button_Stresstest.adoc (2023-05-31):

== Test 6

[%autowidth]
|===
|Datum | 08.05.2023
| Verantwortlich | Ron Gürber & Shane Zulauf
|===

include::TestCases/3_6_Button_Stresstest.adoc[]

*Status:* Erfolgreich

*Bemerkungen:*
Durchührungsort: Werkstatt 4.027 FHNW Campus Brugg-Windisch
|===
|Komponente|Bemerkung
|Button |Die Buttons halten sehr gut. Man kann den Button Kopf abnehmen und ersetzen, falls er zerstört wird. Die Funktionalität der Buttons ist auch unter hohen Druck noch gewährleistet. Es kann jedoch bei hohem benutz dazu führen, dass die Buttons bei leichtem Betätigen klicken, jedoch kein Signal registrieren. Solche Buttons sind noch funktionsfähig, aber man muss etwas fester drücken.
|===

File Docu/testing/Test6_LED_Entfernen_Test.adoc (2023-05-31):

== Test 6

[%autowidth]
|===
|Datum | 10/11.05.2023
| Verantwortlich | Ron Gürber
|===

include::TestCases/3_1_Entfernen_von_LEDs.adoc[]

*Status:* Erfolgreich

*Bemerkungen:* Durchührungsort: Werkstatt 4.027 FHNW Campus Brugg-Windisch. +
RGB LED sollten nach unten gedrückt werden. Nach oben herausziehen stellte sich äusserst schwierig heraus.

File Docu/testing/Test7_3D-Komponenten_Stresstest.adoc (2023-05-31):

== Test 6

[%autowidth]
|===
|Datum | 10/11.05.2023
| Verantwortlich | Ron Gürber & Shane Zulauf
|===

include::TestCases/3_2_3D-Komponenten_Stresstest.adoc[]

*Status:* Erfolgreich

*Bemerkungen pro Komponente:*
Durchührungsort: Werkstatt 4.027 FHNW Campus Brugg-Windisch
|===
|Komponente|Klebstoff|Widerstandskraft|Stress
|Knoten Halterung|Sekundenkleber| ca. 100N |Die Knoten Halterungen halten generell auch sehr fest. Man kann sie mit alleinigem Ziehen nicht lösen.
|Knoten LED|Sekundenkleber| ca. 50N| Die LEDs selber sind etwas weniger resistent aber sind auch schwieriger daran zu ziehen. Laufzeit ca. 50'000 Stunden
|Häuser & Wasserkraftwerk| Araldite| ca. 150N| Diese Komponenten wurden mit Araldite (2-Komponenten-Kleber) befestigt. Die Komponenten sind generell auch resistent gegen Druck
|Windrad & Fabrik| Stöpsel in Brett geklebt mit Araldite | ca. 200N | Die Windräder und Fabrik werden auch per Stöpsel ins Holz festgeklebt. Die Fabrik ist Massiv und generell nicht mehr lösbar nach Befestigung. Die Windräder sind etwas zerbrechlicher, da sie verglichen ermassen dünne Druck Komponenten haben.
|Edge Halterung | Stöpsel in Brett geklebt mit Araldite| ca. 200N| Da die Edge-Halterungen gesteckt und geklebt sind halten sie sehr gut. Wir haben sie auch auf druck getestet und sie sind auch dort ziemlich resistent.
|===

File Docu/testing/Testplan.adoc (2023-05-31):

= Testplan

// https://de.parasoft.com/blog/how-to-write-test-cases-for-software-examples-tutorial/
// Beschreiben Sie hier, wann Sie was testen wollen.

Wir haben 15 RFID-Leser und dazugehörige Chips bestellt. Wenn die angekommen sind, testen wir ob die zusammen funktionieren und nicht zur Störung führen.

Unsere Website wird anschliessend auch getestet, wenn wir die erstellen.

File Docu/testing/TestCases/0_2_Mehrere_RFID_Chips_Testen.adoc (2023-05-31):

TC 0.2: Mehrere RFID auf einmal testen

*Beschreibung:* Bei diesem Test soll geprüft werden, ob der RFID-Leser und die RFID-Chips die vorhanden sind, funktionieren.

*Annahmen und Voraussetzungen:* Sobald wir mehrere RFID-Teile haben..

*Testdaten:* -

*Auszuführende Schritte:*

. 5-10 Stück RFID-Leser mit dem Crowpi oder mit dem RasbPi verbinden und die RFID-Chips an den RFID-Leser halten. Schauen ob mehrere Chips miteinander interferieren.

*erwartetes Ergebnis:* Die LEDs von den RFID-Leser sollten ohne Problem blinken und zusammen benutzbar sein.

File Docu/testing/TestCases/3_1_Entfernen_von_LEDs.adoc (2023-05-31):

TC 3.1 Entfernen von LEDs

*Beschreibung:* Das erfolgreiche Entfernen von RGB und RG LEDs soll getestet werden.

*Annahmen und Voraussetzungen:* LEDs können nicht von Drittpersonen entfernt werden. Die RGB LEDs sind schwierig zu entfernen. Am Besten wird ein schmaler Holz- oder Plastikstab verwendet, um die RGB LEDs nach unten rauszudrücken.

*Testdaten:* 10/11.05.2023

*Auszuführende Schritte:* Ziehen oder drücken der LED nach oben oder unten wird die optimale Weise zu Ersetzung der LED gefunden.

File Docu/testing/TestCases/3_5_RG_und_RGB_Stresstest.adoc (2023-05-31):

TC 3.5 RG und RGB LEDs Stresstest

*Beschreibung:* Die Belastbarkeit und auch funktionalität der genannten LEDs soll getestet werden.

*Annahmen und Voraussetzungen:* Die genannten LEDs können nicht von Drittpersonen entfernt oder zersört werden. Die LEDs sind schwierig zu entfernen. Die LEDs überhitzen nicht und leuchten wie erwartet. Die LEDs funktionieren bei 15-25°C in einem Raum mit Belüftung.

*Testdaten:* 10.05.2023

*Auszuführende Schritte:* Ziehen, Drücken und generelle Druck auf die LEDs ausüben und messen bei welchen Kräften die Komponente sich löst.

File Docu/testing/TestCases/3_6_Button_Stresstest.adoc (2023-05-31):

TC 3.6 Button Stresstest

*Beschreibung:* Die Belastbarkeit der Buttons soll getestet werden.

*Annahmen und Voraussetzungen:* Buttons können nicht von Drittpersonen entfernt oder zersört werden. Die Komponenten sind schwierig zu entfernen und sind nach langer Benutzdauer noch funktional. Die Buttons funktionieren bei 15-25°C in einem Raum mit Belüftung.

*Testdaten:* 08.05.2023

*Auszuführende Schritte:* Ziehen, Drücken und generelle Druck auf den Button ausüben. Button sehr oft, sehr schnell und mit verschiedenen Druckwerten betätigen; schauen wie oft dieser Vorgang wiederholt werden kann bevor Button bricht / nicht mehr funktional ist.

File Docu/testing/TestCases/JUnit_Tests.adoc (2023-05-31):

= JUnit Test Dokumentation
:author:
:date:
:icons:
:source-highlighter:
:toc:

== Einleitung

Diese Dokumentation deckt die Testklassen ab, die für das Projekt "Flow" erstellt wurden. Sie beinhaltet zwei Hauptpakete: `ch.fhnw.game`, das Tests für die Hauptspiellogik enthält, und `ch.fhnw.flow.maxflowalg`, das Tests für die Max-Flow-Algorithmus-Implementierung enthält.

== Testklassen in ch.fhnw.game

Im `ch.fhnw.game` Paket finden sich drei Testklassen:

- `GameLogicTest`
- `LevelTest`
- `MenuTest`

=== GameLogicTest

Die Klasse `GameLogicTest` testet die Hauptspiellogik. Sie überprüft die korrekte Ausführung der Spiellogik, die Interaktion mit den Spielobjekten und die Auswirkungen von Spieleraktionen.

=== LevelTest

Die Klasse `LevelTest` testet die korrekte Erzeugung und Funktion der Level. Sie überprüft, ob jedes Level mit den richtigen Attributen initialisiert wird, und ob Übergänge zwischen den Leveln korrekt funktionieren.

=== MenuTest

Die Klasse `MenuTest` testet das Hauptmenü und dessen Interaktionen. Sie stellt sicher, dass Menüoptionen korrekt funktionieren und dass Benutzerinteraktionen ordnungsgemäss verarbeitet werden.

== Testklassen in ch.fhnw.flow.maxflowalg

Im `ch.fhnw.flow.maxflowalg` Paket gibt es ebenfalls drei Testklassen:

- `FlowEdgeTest`
- `FlowNodeTest`
- `MaxFlowTest`

=== FlowEdgeTest

Die Klasse `FlowEdgeTest` überprüft die Funktionalität der Klasse `FlowEdge`. Sie stellt sicher, dass Kanten korrekt erstellt werden und dass die Klassenmethoden korrekt funktionieren, insbesondere dass Kapazitäten korrekt gesetzt und gehandhabt werden.

=== FlowNodeTest

Die Klasse `FlowNodeTest` überprüft die Funktionalität der Klasse `FlowNode`. Sie stellt sicher, dass Knoten korrekt erstellt werden und dass ihre Eigenschaften (wie Verwendungszustand und Zwischenzielstatus) korrekt gesetzt und manipuliert werden können.

=== MaxFlowTest

Die Klasse `MaxFlowTest` überprüft die Implementierung des Edmonds-Karp Algorithmus für den Maximalfluss. Sie stellt sicher, dass der Algorithmus die korrekten Ergebnisse in verschiedenen Situationen liefert und dass Zwischenziele ordnungsgemäss extrahiert werden.

== Weitere Tests hinzufügen

Wenn Sie weitere Tests hinzufügen möchten, erstellen Sie einfach eine weitere Klasse in dem jeweiligen Paket. Benennen Sie die Klasse entsprechend der Funktionalität, die sie testen soll, und fügen Sie `Test` am Ende hinzu. Innerhalb dieser Klasse können Sie dann Methoden mit der Annotation `@Test` erstellen, um verschiedene Aspekte der zu testenden Funktionalität zu überprüfen.

Es ist eine gute Praxis, Tests so klein wie möglich zu halten und jede Testmethode auf einen bestimmten Aspekt der zu testenden Klasse zu beschränken. Darüber hinaus ist es ratsam, den Code so zu strukturieren, dass er leicht getestet werden kann, was oft bedeutet, dass Methoden und Klassen einzeln verantwortlich sind für das, was sie tun.

== Fazit

Diese sechs Klassen bieten eine umfassende Testabdeckung für das "GraphAlgorithm" Projekt. Sie stellen sicher, dass sowohl die Hauptspiellogik als auch der Maximalflussalgorithmus korrekt funktionieren.

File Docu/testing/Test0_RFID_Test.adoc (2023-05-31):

== Test 0

[%autowidth]
|===
|Datum | 19.10.2022
|Verantwortlich | Erhan Bilgili
|===

include::TestCases/0_0_RFID-Leser_Testen.adoc[]

*Status:* Teilweise Erfolgreich

*Bemerkungen:* Der externe RFID-Leser hat funktioniert aber, der integrierte RFID-Leser von dem Crowpi hat nicht funktioniert.

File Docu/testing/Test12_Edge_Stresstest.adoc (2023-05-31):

== Test 6

[%autowidth]
|===
|Datum | 08.05.2023
| Verantwortlich | Ron Gürber & Shane Zulauf
|===

include::TestCases/3_7_Edge_Stresstest.adoc[]

*Status:* Erfolgreich

*Bemerkungen:*
Durchührungsort: Werkstatt 4.027 FHNW Campus Brugg-Windisch
|===
|Komponente|Bemerkung
|Edge (Acrylglasstab) | Das Schneiden mit dem Klebbandstreifen ist zwar nicht optimal, aber mit kurzem schleifen der neuen Kante mit 240er-Schleifpapier ist die Kante brauchbar. Bei einer Länge von 300mm reicht eine einseitige Beleuchtung. Die Stäbe können problemlos auf den Boden fallen und verlieren ihre Funktionialität nicht.
|===

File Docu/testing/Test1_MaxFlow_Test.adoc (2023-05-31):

== Test 0

[%autowidth]
|===
|Datum | 18.11.2022
|Verantwortlich | Erhan Bilgili
|===

include::TestCases/0_1_MaxFow_Alg_Testen.adoc[]

*Status:* Erfolgreich

*Bemerkungen:* -.

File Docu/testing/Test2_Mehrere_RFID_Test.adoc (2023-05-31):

== Test 0

[%autowidth]
|===
|Datum | dd.11.2022
|Verantwortlich | Erhan Bilgili
|===

include::TestCases/0_2_Mehrere_RFID_Chips_Testen.adoc[]

*Status:* -

*Bemerkungen:* -

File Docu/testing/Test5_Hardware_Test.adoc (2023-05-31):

== Test 5

[%autowidth]
|===
|Datum | 10/11/12.05.2023
| Verantwortlich | Ron Gürber
|===

include::TestCases/3_0_Stabilität_der_Hardware.adoc[]

*Status:* Erfolgreich

*Bemerkungen:* Durchührungsort: Werkstatt 4.027 FHNW Campus Brugg-Windisch. +
Komponenten mit Araldit sind sehr stabil.

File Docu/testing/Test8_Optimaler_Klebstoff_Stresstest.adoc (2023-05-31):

== Test 6

[%autowidth]
|===
|Datum | 08.05.2023
| Verantwortlich | Ron Gürber & Shane Zulauf
|===

include::TestCases/3_3_Optimaler_Klebstoff_Stresstest.adoc[]

*Status:* Erfolgreich

*Bemerkungen pro Klebstoff:*
Durchührungsort: Werkstatt 4.027 FHNW Campus Brugg-Windisch
|===
|Klebstoff|Bemerkung
|Heissleim|Gut für den Rasen. 3D-Komponenten haften gut aber sind einfach zu entfernen. Leim selber kann auch gut entfernt werden
|Sekundenkleber|Der Sekundenkleber klebt komischerweise nicht immer gleich-. Wir nehmem an, dass es auf die Auflagefläche draufan kommt. Ab und zu klebt es unglaublich stark aber meistens kann man die Komponente mit wenig Druck lösen.
|Araldite| Araldite ist generell die beste Lösung für alles. Unglaubliche Widerstandsfähigkeit.Wir haben schlussendlich die meisten Komponenten mit Araldite befestigt.
|===

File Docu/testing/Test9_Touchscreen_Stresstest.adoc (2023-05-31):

== Test 6

[%autowidth]
|===
|Datum | 12.05.2023
| Verantwortlich | Ron Gürber & Shane Zulauf
|===

include::TestCases/3_4_Touchscreen_Stresstest.adoc[]

*Status:* Erfolgreich

*Bemerkungen:*
Durchührungsort: Werkstatt 4.027 FHNW Campus Brugg-Windisch
|===
|Komponente|befestigung|Widerstandskraft|Stress
|Display|Geschraubt|Muss abgeschraubt werden |Das Display ist generell sehr robust. Man kann ihn nicht bewegen und das touch-interface ist auch belastbar.
|===

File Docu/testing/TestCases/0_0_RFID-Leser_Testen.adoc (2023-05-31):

TC 0.0: Mit RFID herumexperimentieren

*Beschreibung:* Bei diesem Test soll geprüft werden, ob der RFID-Leser und die RFID-Chips die vorhanden sind, funktionieren.

*Annahmen und Voraussetzungen:* RFID-Leser muss mit dem Crowpi verbindet sein.

*Testdaten:* -

*Auszuführende Schritte:*

. Externe RFID-Leser mit dem Crowpi verbinden und den RFID-Chip an dem RFID-Leser halten. Dasselbe mit dem Crowpi integriertem RFID-Leser machen.

*erwartetes Ergebnis:* Das LED von dem RFID-Leser sollte blinken.

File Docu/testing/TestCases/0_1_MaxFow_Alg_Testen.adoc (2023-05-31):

TC 0.1: Max-Flow Algorithm source code testen

*Beschreibung:* Bei diesem Test soll geprüft werden, ob der Source Code das unser Entwickler geschrieben hat, fehlerfrei funktioniert und richtiges Output rausgibt.

*Annahmen und Voraussetzungen:* Unit-Tests sollten geschrieben werden.

*Testdaten:*

import org.junit.Test;

import static org.junit.Assert.*;

public class MaxFlowTest {

@Test

    public void fordFulkerson() {
        int graph[][] = new int[][]{
        {0, 16, 13, 0, 0, 0, 0},
        {0, 0, 10, 12, 0, 0, 0},
        {0, 4, 0, 0, 14, 0, 0},
        {0, 0, 9, 0, 0, 20, 1},
        {0, 0, 0, 7, 0, 4, 0},
        {0, 0, 0, 0, 0, 0, 0},
        {0, 0, 0, 0, 1, 0, 0}
                                };

    MaxFlow m = new MaxFlow();
    int[] interimGoals = new int[]{0, 1, 2, 3, 4, 5, 6};
    int mF = m.fordFulkerson(graph, 0, 5, interimGoals);

    assertEquals(23, mF);
    boolean[] interimGoalsReached = m.getInterimGoalsReached(m.getFlowGraph(), interimGoals);
    assertEquals(false, interimGoalsReached[6]);// 7th element should be false
    for(int i = 0; i < interimGoalsReached.length - 1; i++) { // everything except for 7th (last) element
        assertEquals(true, interimGoalsReached[i]);
        }
    }
}

*Auszuführende Schritte:*

. Unit-Tests ausführen.

*erwartetes Ergebnis:* Tests sollten bestehen.

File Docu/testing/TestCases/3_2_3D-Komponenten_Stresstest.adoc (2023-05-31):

TC 3.2 3D-Komponenten Stresstest

*Beschreibung:* Die Widerstandsfähigkeit und generelle Belastbarkeit aller 3D-Komponeten soll getestet werden

*Annahmen und Voraussetzungen:* 3D-Komponenten können nicht von Drittpersonen entfernt oder zersört werden. Die Komponenten sind schwierig zu entfernen.

*Testdaten:* 10.05.2023

*Auszuführende Schritte:* Ziehen, Drücken und generelle Druck auf die 3D-Komponenten ausüben und messen bei welchen Kräften die Komponente Bricht/sich löst

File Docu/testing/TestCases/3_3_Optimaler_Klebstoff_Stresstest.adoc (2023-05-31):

TC 3.3 Optimaler Klebstoff Stresstest

*Beschreibung:* Der optimale Klebstoff für das Kleben der Komponenten soll gefunden werden

*Annahmen und Voraussetzungen:* Komponenten sollen festkleben und nicht entfernbar sein.

*Testdaten:* 08.05.2023

*Auszuführende Schritte:* Ziehen, Drücken und generelle Druck auf die 3D-Komponenten ausüben und messen bei welchen Kräften die Komponente sich löst. Dieses Verafheren mit allen Klebstoffen vergleichen.

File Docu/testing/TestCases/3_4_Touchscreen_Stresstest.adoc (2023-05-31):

TC 3.4 3D-Komponenten Stresstest

*Beschreibung:* Die Widerstandsfähigkeit und generelle Belastbarkeit des Touchscreen-Displays soll getestet werden

*Annahmen und Voraussetzungen:* Display soll nicht von Drittpersonen entfernt oder zersört werden können. Der Display funktionieren bei 15-25°C in einem Raum mit Belüftung.

*Testdaten:* 12.05.2023

*Auszuführende Schritte:* Ziehen, Drücken und generelle Druck auf den Display ausüben. Mögliche Schwachstellen notieren.

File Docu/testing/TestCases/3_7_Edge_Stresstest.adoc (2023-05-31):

TC 3.7 Edge Stresstest

*Beschreibung:* Die Belastbarkeit und Leuchtkraft der Edges soll getestet werden. Die Bearbeitungstechnik soll getestet werden

*Annahmen und Voraussetzungen:* Die Edges funktionieren bei 15-25°C in einem Raum mit Belüftung.

*Testdaten:* 08.05.2023

*Auszuführende Schritte:* Die Edges sollen unter Druck gesetzt werden um zu schauen bei welchen Werten sie Brechen. Mit einer Lichtquelle (von Smartphone und RGB LED) soll der Acrylstab durchleuchtet werden und die maximale Länge, bei welcher die Lichtsärke nicht abnimmt, messen. Acrylglas mit Klebband bei Schnittstelle einwickeln und bei Decoupiersäge zerschneiden. Schauen ob neue Kante das Licht immernoch gleich bricht. Edge soll bei neuer Kante immernoch gleich leuchten.

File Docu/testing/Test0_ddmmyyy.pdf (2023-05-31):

# Test 0

Datum | dd.mm.yyy
Verantwortlich | Max Muster

TC 1.1: Ein Ausschalten

Beschreibung: Bei diesem Test soll geprüft werden, ob das Produkt ein und ausgeschaltet werden kann.

Annahmen und Voraussetzungen: Damit das Produkt eingeschaltet werden kann muss eine Stromversorgung vorhanden sein.

Testdaten: -

Auszuführende Schritte:

1. Einstecken des Steckers in die Stromversorgung.
2. Drücken des roten Knopfes.

erwartetes Ergebnis: Das grüne LED sollte leuchten

Status: Erfolgreich

Bemerkungen: Der Knopf lies sich nur schwer drücken.

1

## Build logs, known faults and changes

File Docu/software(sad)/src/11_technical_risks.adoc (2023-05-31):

[[section-technical-risks]]
== Risiken und technische Schulden
=== Risikotabelle

|==========================================================================================================================================================================================================================================================================================================================================================================================================================================================================================================
| ID  | Risiko  | Beschreibung | Massnahme | Risiko "LEVEL"

| I001
| I2C-Kommunikationsprobleme
| Fehlende oder fehlerhafte Kommunikation zwischen Raspberry Pi 4 und angeschlossenen I2C-Geräten (z. B. TCA9548a, CH423)
| Überprüfung der Verkabelung und der Adressierung der I2C-Geräte, Implementierung von Fehlerbehandlungsroutinen im Code
| high: Wird momentan noch implementiert und nimmt sehr viel Zeit in Anspruch

| I002
| Geeignete Betriebsumgebung
| Überhitzung des Raspberry Pi 4 oder anderer Hitze erzeugender Komponenten
| Verwendung des Produkts ausschliesslich in durchlüfteten/klimatisierten Innenräumen
| low: In der richtigen Umgebung kein Risiko

| I003
| Absturz aufgrund von Memory-Leaks
| Fehler in der Java-Software, die das Projekt steuert
| Durchführung von Code-Reviews, Implementierung von Unit-Tests
| low: Wird fortlaufend mit Erweiterung des Codes durchgeführt

| I004
| RFID-Reader-Kommunikationsprobleme
| Probleme bei der Kommunikation zwischen dem RFID-Reader und dem Raspberry Pi 4
| Verwendung von genug Abstand zu anderen Komponenten zur Reduzierung von elektromagnetischen Störungen, Überprüfung der Verkabelung und Implementierung von Fehlerbehandlungsroutinen im Code
| medium: Nur ein RFID-Reader, aber noch nicht genügend getestet
|==========================================================================================================================================================================================================================================================================================================================================================================================================================================================================================================

=== Vergangene Hürden

=== RFID-Chips

Eines der ersten Hindernisse, auf die wir in unserem Projekt gestossen sind, war die Beschaffung von RFID-Chips. Die bestellten Chips stellten sich als nicht "out of the box"-i2c-kompatibel heraus, und konnten nur durch einen sehr komplizierte Modifizierung auf i2c geändert werden. Dies führte zu erheblichen Verzögerungen und zusätzlichen Aufwand für das Team.

=== Komplexität der ursprünglichen Idee

Die ursprüngliche Idee unseres Projekts war sehr komplex und umfasste die Verwendung von 25 RFID-Lesegeräten. Die Umsetzung dieser Idee erwies sich als äusserst schwierig und zeitaufwändig. Deshalb haben wir uns entschieden, das Konzept zu ändern und die Anzahl der RFID-Lesegeräte zu reduzieren, um das Projekt realisierbar zu machen.

=== Verfügbarkeit von Hardware-Bibliotheken

Ein weiterer technischer Risikofaktor in unserem Projekt war die Verfügbarkeit von Bibliotheken für die verwendeten Hardware-Komponenten. Leider waren die benötigten Bibliotheken nur für Python verfügbar, was uns dazu zwang, zusätzliche Zeit für die Anpassung der Bibliotheken an unsere Projektanforderungen zu investieren.

=== Dokumentation von Pi4j Methoden und Klassen

Wir stellten fest, dass die Dokumentation der Pi4j in Bezug auf Methoden und Klassen nicht unseren Erwartungen entsprach. Die bereitgestellten Informationen waren unserer Meinung nach unzureichend, was die Verwendung für die selbst umgeschriebene CH423 Wrapper-Class in unserem Projekt erschwerte. Trotz zahlreicher Beispiele in der Dokumentation waren nur wenige von diesen relevant. Was die Situation weiter verschärfte.

////
Erst am Schluss des Projekts:
Zusammenfassend konnten wir durch Vereinfachungen des Projektkonzepts und Einsatz von zusätzlichen Ressourcen, diese Hürden bewältigen und unser Projekt umsetzen.
////

////
| I001 | RFID interference, Da wir vor haben, mehrere RFID Reader zu nutzen, besteht das Risiko von grosser interference. Die Praktische anwendung haben wir noch nicht untersucht +
(nur small scale testing). | High, lösbar mit viel Testing

| I002 | Wissensaneignung in Bezug auf allgemeine Lösungen mit der Libary Pi4j. Speziell in Bezug auf die RFID Chips und deren ansteuerung (bei grösserer Anzahl)   | High, Zeitintensiv, Backup plan notwendig.

| I002.1 | Wissensaneignung im Bezug auf i2c, SPI, UART, ansteuerung von mehrfachen RFID Chips unter Verwendung der Pi4j libary.| High, Zeitintensiv, Backup plan notwendig.

|I002.2
| Vordefinierter Backup plan: Einen, zentralen RFID Chip für Erkennung der "Capacity", bestätigung dieser  jedoch mithilfe von Knöpfen an den diversen Stellen.      | HIGH Technisch leichter umsetzbar, da nur ein RFID anzusteuern ist und nicht 20.

|I003| Erste Erfahrung mit Implementation eines Maxflow problems, da implementierung und Verständniss kompliziert, hoher aufwand.| High, viel know-how noch nachzuholen

|I004| Verbindung technischer Komponenten (Verkabelung, Löten), Touchscreen, LED's  | High, da know-how noch zu erarbeiten ist.

|I005 | Absturz aufgrund von Memory-Leaks. | medium, Problem sollte bis zur Live-demonstration, nach genug Testing "low" sein.

|I006| Bezüglich Qualitätsziele:
Sinnvolle Generation des Schwierigkeitsgrads vom Maxflowproblem. Abschätzung der Stärke| medium|

I007| Implementierung der Wetter API, basierend auf Qualitätszielen: Sollte Offline verfügbar sein. (Caching der Daten)|low

|I008
| Vordefinierter Backup plan: Einen, zentralen RFID Chip für Erkennung der "Capacity", bestätigung dieser  jedoch mithilfe von Knöpfen an den diversen Stellen.      | HIGH Technisch leichter umsetzbar, da nur ein RFID anzusteuern ist und nicht 20.   |
I009
| -          | -   | I010
| -  | -     | I011       | -  |-
|==========================================================================================================================================================================================================================================================================================================================================================================================================================================================================================================
////
////
.Motivation
"Risikomanagement ist Projektmanagement für Erwachsene."
-- Tim Lister, Atlantic Systems Guild

Unter diesem Motto sollten Sie Architekturrisiken und/oder technische Schulden gezielt ermitteln, bewerten und Ihren Management-Stakeholdern (z.B. Projektleitung, Product-Owner) transparent machen.

.Form
Liste oder Tabelle von Risiken und/oder technischen Schulden, eventuell mit vorgeschlagenen Maßnahmen zur Risikovermeidung, Risikominimierung oder dem Abbau der technischen Schulden.

.Weiterführende Informationen

Siehe https://docs.arc42.org/section-11/[Risiken und technische Schulden] in der online-Dokumentation (auf Englisch!).
****

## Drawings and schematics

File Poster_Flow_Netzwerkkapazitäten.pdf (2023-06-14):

# flow

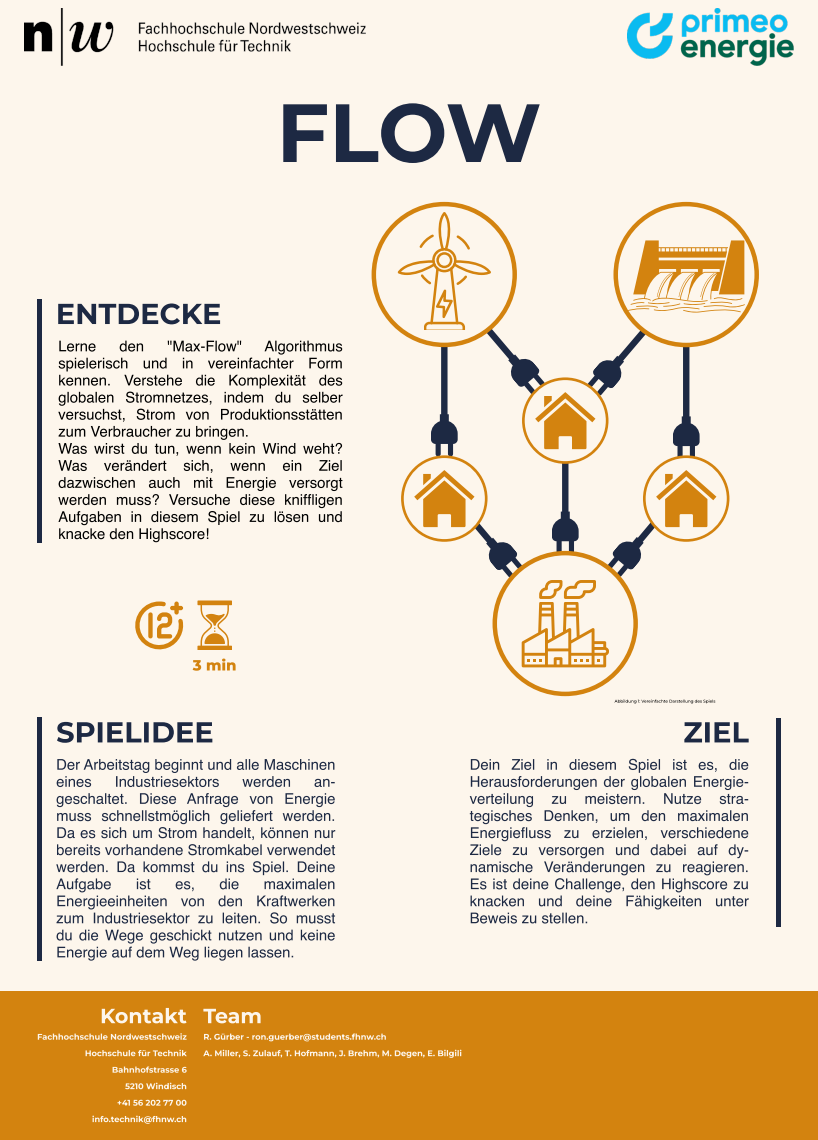
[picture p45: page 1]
eines; Industriesektors; werden; Aufgabe; ist; die; maximalen; Energieeinheiten; von; den; Kraftwerken; Spielidee; Entdecke; Lerne; "Max-Flow"; Algorithmus; spielerisch; und; vereinfachter; Form; Was; verändert; sich,; wenn; ein; Ziel; verteilung zu; meistern.; Nutze; stra-; Kontakt; Fachhochschule Nordwestschweiz; Bahnhofstrasse 6; 5210 Windisch; Team; 3 min

kennen. Verstehe die Komplexität des
globalen Stromnetzes, indem du selber
versuchst, Strom von Produktionsstätten
zum Verbraucher zu bringen.
Was wirst du tun, wenn kein Wind weht?
dazwischen auch mit Energie versorgt
werden muss? Versuche diese kniffligen
Aufgaben in diesem Spiel zu lösen und
knacke den Highscore!

Abbildung 1: Vereinfachte Darstellung des Spiels

Der Arbeitstag beginnt und alle Maschinen
geschaltet. Diese Anfrage von Energie
muss schnellstmöglich geliefert werden.
Da es sich um Strom handelt, können nur
bereits vorhandene Stromkabel verwendet
werden. Da kommst du ins Spiel. Deine
zum Industriesektor zu leiten. So musst
du die Wege geschickt nutzen und keine
Energie auf dem Weg liegen lassen.

Dein Ziel in diesem Spiel ist es, die
Herausforderungen der globalen Energie-
tegisches Denken, um den maximalen
Energiefluss zu erzielen, verschiedene
Ziele zu versorgen und dabei auf dy-
namische Veränderungen zu reagieren.
Es ist deine Challenge, den Highscore zu
knacken und deine Fähigkeiten unter
Beweis zu stellen.

R. Gürber - ron.guerber@students.fhnw.ch

Hochschule für Technik

A. Miller, S. Zulauf, T. Hofmann, J. Brehm, M. Degen, E. Bilgili

info.technik@fhnw.ch

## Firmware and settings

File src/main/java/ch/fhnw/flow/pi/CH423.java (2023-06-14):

package ch.fhnw.flow.pi;

import com.pi4j.exception.Pi4JException;
import com.pi4j.io.i2c.I2C;
import com.pi4j.io.i2c.I2CConfig;

import java.util.List;
import java.util.function.Consumer;

import static ch.fhnw.flow.pi.HardwareCommand.pi4j;

public class CH423 {

    private I2C CH423_CMD_SET_SYSTEMARGS;
    // Set low 8bit general-purpose output command
    private I2C CH423_CMD_SET_GPO_L;
    // Set high 8bit general-purpose output command
    private I2C CH423_CMD_SET_GPO_H;
    // Set bi-directional input/output pin command
    private I2C CH423_CMD_SET_GPIO;
    // Set bi-directional input/output pin command
    private I2C CH423_CMD_READ_GPIO;

    private final int eGPOTOTAL = GPO.values().length;

    // Bi-directional input/output pin, GPIO0
    public enum GPO {
        eGPO0(0, "GPO0"),
        eGPO1(1, "GPO1"),
        eGPO2(2, "GPO2"),
        eGPO3(3, "GPO3"),
        eGPO4(4, "GPO4"),
        eGPO5(5, "GPO5"),
        eGPO6(6, "GPO6"),
        eGPO7(7, "GPO7"),
        eGPO8(8, "GPO8"),
        eGPO9(9, "GPO9"),
        eGPO10(10, "GPO10"),
        eGPO11(11, "GPO11"),
        eGPO12(12, "GPO12"),
        eGPO13(13, "GPO13"),
        eGPO14(14, "GPO14"),
        eGPO15(15, "GPO15"),
        ;
        private int gpo;
        private String gpoStr;

        GPO(int gpo, String gpoStr) {
            this.gpo = gpo;
            this.gpoStr = gpoStr;
        }

        @Override
        public String toString() {
            return gpoStr;
        }

        public int toInteger() {
            return gpo;
        }
    }

    private final int eGPIO_TOTAL = GPIO.values().length;

    public enum GPIO {
        eGPIO0(0, "GPIO0"),
        eGPIO1(1, "GPIO1"),
        eGPIO2(2, "GPIO2"),
        eGPIO3(3, "GPIO3"),
        eGPIO4(4, "GPIO4"),
        eGPIO5(5, "GPIO5"),
        eGPIO6(6, "GPIO6"),
        eGPIO7(7, "GPIO7"),
        ;
        private int gpio;
        private String gpioStr;

        GPIO(int gpio, String gpioStr) {
            this.gpio = gpio;
            this.gpioStr = gpioStr;
        }

        @Override
        public String toString() {
            return gpioStr;
        }

        public int toInteger() {
            return gpio;
        }
    }

    // Bi-directional input/output pin, GPIO0~GPIO7
    public static final int eGPIO = 0;
    // General output pin, GPO0~GPO15
    public static final int eGPO = 1;
    // General output pin, GPO0~GPO7
    public static final int eGPO0To7 = 2;
    // General output pin, GPO8~GPO15
    public static final int eGPO8To15 = 3;

    // GPIO pin input mode, at high level when floating
    public static final int eINPUT = 0;
    // GPIO pin output mode, can output high/low level
    public static final int eOUTPUT = 1;
    // GPO pin open-drain output mode, can only be used for eGPO07 and eGPO815 digital ports. And GPO can only output low level or do not output in this mode
    public static final int eOPENDRAIN = 2;
    // GPO pin push-pull output mode, can only be used for eGPO07 and eGPO815 digital ports. And GPO can output high or low level.
    public static final int ePUSHPULL = 3;

    // configure pin interrupt, low level interrupt
    public static final int eLOW = 0;
    // configure pin interrupt, high level interrupt
    public static final int eHIGH = 1;
    // configure pin interrupt, rising edge interrupt
    public static final int eRISING = 2;
    // configure pin interrupt, falling edge interrupt
    public static final int eFALLING = 3;
    public static final int eCHANGE = 4;

    private static final int ARGS_BIT_IO_EN = 0;
    private static final int ARGS_BIT_DEC_L = 1;
    private static final int ARGS_BIT_DEC_H = 2;
    private static final int ARGS_BIT_INT_EN = 3;
    private static final int ARGS_BIT_OD_EN = 4;
    private static final int ARGS_BIT_SLEEP = 6;
    private int args;
    private int[] modes =  new int[8];
    private Consumer<Integer>[] consumers;
    private int intValue;
    private int gpo0To7;
    private int gpo8To15;
    private static final int busAddr = 1;
    private int channel;
    private TCA9548A tca9548A;

    public CH423(int channel, TCA9548A tca, boolean listener) {
        this.channel = channel;
        tca.addGravityBoard(this);
        if (listener) {
            tca.addGravityBoardToListener(this.channel);
        }
        tca.selectChannel(channel);
        setAddressPorts();
        setConstrParams();
        this.tca9548A = tca;
        this.begin();
    }

    public void setAddressPorts() {
        CH423_CMD_SET_SYSTEMARGS = createI2C(0x48 >> 1);
        // Set low 8bit general-purpose output command
        CH423_CMD_SET_GPO_L = createI2C(0x44 >> 1);
        // Set high 8bit general-purpose output command
        CH423_CMD_SET_GPO_H = createI2C(0x46 >> 1);
        // Set bi-directional input/output pin command
        CH423_CMD_SET_GPIO = createI2C(0x30);
        // Set bi-directional input/output pin command
        CH423_CMD_READ_GPIO = createI2C(0x4D >> 1);
    }

    public I2C createI2C(int deviceAddr) {
        I2CConfig i2cConfig = I2C.newConfigBuilder(pi4j)
                .id("CH423" + channel + "" + deviceAddr)
                .bus(busAddr)
                .device(deviceAddr)
                .provider("linuxfs-i2c")
                .build();
        return pi4j.create(i2cConfig);
    }

    public void setConstrParams() {
        this.args = 0;
        this.modes = new int[8];
        this.consumers = new Consumer[8];
        this.intValue = 0;
        this.gpo0To7 = 0;
        this.gpo8To15 = 0;
    }

    public void begin() {
        begin(eINPUT, ePUSHPULL);
    }

    public void begin(int gpioMode, int gpoMode) {
        args = 0;
        if (gpioMode < eOPENDRAIN) {
            if (gpioMode == eOUTPUT)
                args |= 1 << ARGS_BIT_IO_EN;
        }
        if (gpoMode > eOUTPUT && gpoMode <= ePUSHPULL) {
            if (gpoMode == eOPENDRAIN)
                args |= 1 << ARGS_BIT_OD_EN;
        }
        setSystemArgs();
        intValue = 0xFF;
    }

    public void pinMode(int group, int mode) {
        if (group == eGPIO && mode <= eOPENDRAIN) {
            if (mode == eINPUT) {
                args &= ((~(1 << ARGS_BIT_IO_EN)) & 0xFF);
            } else {
                args |= 1 << ARGS_BIT_IO_EN;
            }
            setSystemArgs();
        } else if (group > eGPIO && mode > eOPENDRAIN) {
            if (mode == eOPENDRAIN) {
                args |= 1 << ARGS_BIT_OD_EN;
            } else {
                args &= ((~(1 << ARGS_BIT_OD_EN)) & 0xFF);
            }
        }
    }
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

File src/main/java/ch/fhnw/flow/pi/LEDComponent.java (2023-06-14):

package ch.fhnw.flow.pi;

import java.util.*;
import java.util.stream.Collectors;

public class LEDComponent extends Component {
    public static final int DEFAULT_BLINK_INTERVAL = 800;
    private boolean isBlinking;
    private boolean isOn;
    private Map<Integer, Boolean> pinAddrMap = new HashMap<>(); // Boolean -> true: light is on; false: light is off;
    private Map<Integer, Boolean> pinPrevAddrMap = new HashMap<>();
    private Thread blinker;

    public LEDComponent(CH423 ch423, Collection<Integer> pins) {
        super(ch423);
        pins.forEach(pin -> {
            pinAddrMap.put(pin, false);
            pinPrevAddrMap.put(pin, false);
        });
        ch423.pinMode(CH423.eGPO, CH423.ePUSHPULL);
    }

    public void toggleOnOff() {
        if(isOn) {
            turnOff();
        }
        else {
            Set<Integer> pins = pinPrevAddrMap.keySet().stream().filter(i -> pinPrevAddrMap.get(i)).collect(Collectors.toSet());
            if(pins.isEmpty()) {
                turnOn(pinAddrMap.keySet());
            } else {
                turnOn(pins);
            }
        }
    }

    public void turnOn(Collection<Integer> pins) {
        super.getCh423().getTca9548A().selectChannel(super.getCh423().getChannel());
        pins.forEach(pin -> {
            if(!pinAddrMap.get(pin)) {
                super.getCh423().gpoDigitalWrite(pin, CH423.eHIGH);
                pinAddrMap.put(pin, true);
            }
        });
        isOn = true;
    }

    public void turnOff() {
        super.getCh423().getTca9548A().selectChannel(super.getCh423().getChannel());
        pinAddrMap.forEach((pin, on) -> {
            if(on) {
                super.getCh423().gpoDigitalWrite(pin, CH423.eLOW);
                pinAddrMap.put(pin, false);
                pinPrevAddrMap.put(pin, true);
            }
            else {
                pinPrevAddrMap.put(pin, false);
            }
        });
        isOn = false;
    }

    public void turnOffForced() {
        pinAddrMap.keySet().forEach(pin -> {
            super.getCh423().gpoDigitalWrite(pin, CH423.eLOW);
        });
    }

    public void blink() throws InterruptedException {
        blink(DEFAULT_BLINK_INTERVAL);
    }
    public void blink(int time) throws InterruptedException {
        toggleOnOff();
        Thread.sleep(time);
        toggleOnOff();
        Thread.sleep(time);
    }
    public static void blink(Collection<LEDComponent> leds) throws InterruptedException {
        blink(leds, DEFAULT_BLINK_INTERVAL);
    }

    public static void blink(Collection<LEDComponent> leds, int time) throws InterruptedException {
        leds.forEach(LEDComponent::toggleOnOff);
        Thread.sleep(time);
        leds.forEach(LEDComponent::toggleOnOff);
        Thread.sleep(time);
    }

    public void blinking(int time) throws InterruptedException {
        if(!isBlinking) { return; }
        toggleOnOff();
        if(!isBlinking) { return; }
        Thread.sleep(time);
    }

    public void startBlinking() {
        startBlinking(DEFAULT_BLINK_INTERVAL);
    }

    public void startBlinking(int interval) {
        if(isBlinking) return;
        isBlinking = true;
        blinker = new Thread(() -> {
            boolean initOn = isOn;
            int i = 0;
            while (isBlinking && i < 15) {
                try {
                    blinking(interval);
                } catch (InterruptedException e) {
                    // TODO: log
                    isBlinking = false;
                }
                i++;
            }
            if(initOn && !isOn) {
                turnOn(pinPrevAddrMap.keySet());
            }
        });
        blinker.start();
    }
    public void addPin(int pin) {
        pinAddrMap.put(pin, false);
        pinPrevAddrMap.put(pin, false);
    }
    public void stopBlinking() {
        isBlinking = false;
        if(blinker.isAlive()) {
            try {
                blinker.join();
            } catch(InterruptedException exception) {
                // TODO: LOG
                System.out.println(exception.getMessage());
            }
        }
    }
    public boolean isBlinking() {
        return isBlinking;
    }
    public boolean isOn() {
        return isOn;
    }

    public Collection<Integer> getPins() {
        return pinAddrMap.keySet();
    }
    public Collection<Integer> getActivePins() {
        return pinAddrMap.entrySet().stream().filter(entry -> entry.getValue()).map(Map.Entry::getKey)
                .collect(Collectors.toCollection(HashSet::new));
    }
}

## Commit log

2023-05-31 Dokumentation wurde mit dem Doku Ordner hinzugefügt
    [AcrylstabHalter.stl, HyperLoopStationVar4_2.stl, LCD_Abdeckung_1.stl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]
2023-05-31 Dokumentation mit dem Ordner Doku hinzugefügt
    [AcrylstabHalter.stl, HyperLoopStationVar4_2.stl, LCD_Abdeckung_1.stl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]
2023-06-13 added source code
    [Deckel_mit_Arrow.stl, IP12_Edge_Capacity_Number_1.stl, IP12_Edge_Capacity_Number_2.stl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]
